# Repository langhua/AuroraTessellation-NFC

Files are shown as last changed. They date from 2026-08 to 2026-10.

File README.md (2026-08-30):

# AuroraTessellation-NFC
Aurora Tessellation NFC（NFC极光镶嵌）：一款桌面级NFC磁场可视化工具。灵感来自极光——太阳风在地球磁场中留下的光痕；用64个线圈组成的“磁像素”阵列，将13.56 MHz的近场磁场分布实时呈现为极光热力图。

## 项目状态

当前从 4×4、16 通道子板开始验证，使用 ESP32-S3 和 4×4 WS2812B 显示模块。第一阶段采用“全波整流 + TS3A44159 差分背景采样”方案，实施顺序和验收标准见 [4×4 子板验证文档](docs/phase-1-4x4-validation.md)。

## 产品形态（最终目标）

桌面级 NFC 磁场可视化模块——“磁像素”阵列，把 13.56 MHz 近场磁场分布实时呈现为极光热力图。

- **阵列规模**：8×8 = **64 个 PCB 铜箔线圈**（磁像素），每个线圈 1:1 对应 **64 颗 WS2812B（5050 封装）LED**，1 采样通道 ↔ 1 LED
- **线圈**：φ19 mm、6 匝、0.2 mm 线宽、20 mm 中心间距 → 阵列覆盖约 **160×160 mm**（4×4 版为 16 线圈、80×80 mm）
- **采集**：每通道全波整流 + 差分背景采样（2×BAT54S + 10 kΩ/100 nF RC）→ TS3A44159 → CD74HC4067 → ESP32-S3 ADC1
- **控制**：ESP32-S3 控制板（WROOM-1 + USB Type-C + CH340 + 3.3 V LDO + EN/BOOT，待建）
- **结构**：**4 块 4×4 传感子板**（每块 16 线圈）拼到 **64 通道母板**，配 8×8 WS2812B 显示
- **尺寸预估（8×8）**：
  - 传感面：**160 × 160 mm**（单板）；或 **4 块 80 × 80 mm** 4×4 子板拼 **64 通道母板**（含连接器 + 控制区约 180~200 × 180~200 mm）。计算：8 线圈 × 20 mm 中心间距 → 首尾 140 mm + φ19 + 板边 0.5×2 = 160 mm。
  - 显示面（8×8 显示布局三方案，2026-08-30 定）：
    - **方案 A · 叠层 1:1（磁像素）**：20 mm 间距定制 LED 板（160×160 mm）叠在线圈板背面，每颗 LED 对准一个线圈 → 热力图与磁场位置 1:1。留作后续优化。
    - **方案 B · LED 嵌线圈孔径**：LED 装在线圈中心孔（φ8）背面往上打光，视觉“镶嵌”感最强；LED 金属可能轻微失谐，需实测。进阶方案，定型后再试。
    - **方案 C · 独立显示板（当前采用）**：现成 7.5 mm 间距 WS2812B 模块（4×4≈30×30 mm、8×8≈60×60 mm）做独立热力图，不追求与线圈 1:1 物理对齐（现成模块间距 7.5 mm ≠ 线圈 20 mm）。
  - 整机：约 **170 × 170 × 30 mm** 桌面盒（传感层 + 显示层堆叠，中间夹控制板）。

## 开发过程总览（4×4 验证 → 8×8 量产）

先小步验证再放大：单通道 → 4 通道 → 4×4 子板 → 完整模块 → 8×8。

```mermaid
flowchart TD
    M0["M0 器件·拓扑（已完成）<br/>单通道原理图 / 元件库 / 线圈阵列铜层"]
    M1["M1 单通道台架验证（面包板）<br/>独立线圈+整流+示波器：无场/弱场/强场"]
    M2["M2 4通道验证（面包板）<br/>TS3A 差分切换 + MUX 逐通道读"]
    M3["M3 4×4 子板 PCB<br/>16路电路 + 4×4 线圈阵列 → Gerber 打板"]
    M4["M4 完整模块<br/>ESP32 读16路 + 背景相减 + 归一化 → 4×4 WS2812B 热力图"]
    M5["M5 8×8 · 64通道母板<br/>4 块 4×4 子板复制 + 64 通道母板"]
    M0 --> M1 --> M2 --> M3 --> M4 --> M5
```

要点：

- **PCB 线圈不是独立子板**——它是传感子板 PCB 的顶层铜箔走线（`coil_4x4_array`），随子板一起验证。面包板阶段用绕制独立线圈（φ20≈φ19）验证信号链和信号量级。
- 可选降险：先打一张**极小的单线圈测试板**（1 个 φ19 线圈 + 2 焊盘），用示波器/网分确认电感和谐振，再铺满 4×4。
- 单通道子板（`hardware/subboard_4x4/single-channel/`）已按**方案 C** 拆分：**无 MCU**，接口为 **J1（8 个网络标签，标注 ESP32-S3-DevKitC-1 IO1/IO2/3V3/IO4/IO5/IO6/IO7/GND，无排针/焊盘元件，实物连接点 M3 布局阶段再加）**，接独立的 ESP32 控制板；面包板原型用 DevKitC-1 经 J1 引线连接。
- 显示侧已验证：`ws2812b-single-test`、`ws2812b-4x4-test`（16 颗 5050，灯序右下角起、每列从下往上）均已跑通。
- **当前进度：M0 基本完成**，下一步是 M1——按 `single-channel-breadboard-wiring.md` 在面包板搭建，接示波器验证。

### Fritzing 部件进度（fritzing-parts-langhua）

| 部件 | 状态 |
|---|---|
| NFC Coil（20mm 6 匝平面感应线圈） | ✅ 已完成并提交 |
| coil_4x4_array（φ19mm 4×4 阵列铜层） | ✅ 已完成 |
| BAT54S（SOT-23 双肖特基二极管） | ✅ 已完成并提交 |
| TS3A44159（TSSOP-16 差分开关） | ✅ 已完成并提交（`TS3A44159PWR.fzpz`，引脚 13~16 已按 SCDS225 核对） |
| CD74HC4067（24 脚 MUX） | ✅ 已完成并提交（`CD74HC4067.fzpz`，四视图 icon/schematic/breadboard/PCB 按 datasheet 绘制） |

## 文档

- [4×4 子板验证文档](docs/phase-1-4x4-validation.md)
- [Fritzing 自定义部件开发指南](../fritzing-parts-langhua/docs/part-dev-guide.md)（位于 fritzing-parts-langhua 部件库，做 BAT54S、TS3A44159 等部件前必读）

## 重要设计说明

本项目输出的是 13.56 MHz NFC 近场磁场的相对分布，不等同于经过校准的 A/m 绝对场强测量仪。打板前必须确认整流拓扑：BAT54S 是双二极管器件，不能直接视为完整四二极管全波整流桥。

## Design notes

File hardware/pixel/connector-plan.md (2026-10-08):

# 像素板接插件方案：3P 三线总线（交叉 / 防呆 / 半双工）

> 状态（2026-09-25）用户已定：① 连接器 = **`SH-1.0-3P-V`（1.0 mm 间距、宽 5.0 mm —— 取最小尺寸）** ✓；② 数据 = **半双工** ✓。
> 本文定针序、口位、交叉与防呆的做法、丝印与电气注意；`pixel.fzz` 按此连线。

SH-1.0-3P-V 的 icon

*已定座子：`SH-1.0-3P-V`（立贴，库里已有 ✓，宽 5.0 mm ✓）/ 更好手焊的 `MX-1.25-3P-V` 见 §6*

## 0. 先说结论：3P + 半双工 ⇒ 两口**电气等价**，"交叉"问题自然消失

三根针只能给 `5V / GND / DATA`。数据要双向（命令下行 + 读数回传）就只能**半双工**（收发同线、分时）
⇒ 两个口的 DATA **必须接到同一个 MCU 引脚**（若一个口专收、一个口专发，读数就永远回不来 ✗：
链上的线是**单向**的，out 口指向下游，读数没路回家 ✗）。

于是两块板之间就是**一条三线总线**，`IN / OUT` 只剩丝印意义：

- **交叉**：**不需要** ✓ —— 两个口**同型**：口 A 的 `DATA` 进**上游脚**、口 B 的 `DATA` 进**下游脚**，
  固件**自动识别哪边在收** ✓ ⇒ **怎么插都通** ✓（拿哪根线、插哪个口都对 ✓）
  ⚠️ 但**别把两口的第 3 针短接** ✗ —— 短接就成了“全网一根线”的真总线 ✗，不再是接力链 ✗（见本节末 ✓）
- **防呆**：做到最强 ✓✓ —— 两个口**都能当上游或下游用**，**不存在“插到 OUT 上”这种错误** ✓；
  3P 座本身有极性 ✓，插头也插不反 ✓

⚠️ **代价（必须认下来）**：这就是 `README §5.2` 的 **3 线方案**，固件要**寻址/枚举**（文档里标的
“⚠️ 需一次性标定” ✓）；**板上数据仍是两根网** —— `DATA_IN` = `PC1`(pin 8) 收 ✓、
`DATA_OUT` = `PD2`(pin 16) 发 ✓（★ 2026-10-09 按 PCB 布线需要换脚 ✓，原来是 `PA2`/`PD0` ✓），
省掉的只是**板间那根线** ✓（见下）。

> 时序、帧格式、枚举与回读时隙：见 [`bus-protocol.md`](bus-protocol.md) ✓
> **本文只定"接插件与接线"**；协议细节不在本文。

### 为什么板间只用 3 根线，面上却是两根数据网？

**4 线方案是这样的**：每块板有两个数据脚（`PA2` 收 + `PC1` 发），板间**拉两根数据线**：
```mermaid
flowchart LR
UP1["上游板 · 下行 DATA 驱动"] -->|"线 1（下行）"| DN1["下游板 · 接收"]
DN2["下游板 · 回程 DATA 驱动"] -->|"线 2（回程）"| UP2["上游板 · 接收"]
```

每根线**只走一个方向** ✓，两根各管一向 ⇒ 可以**同时**收发 = 全双工 ✓。

**3P 只有一个数据针** ⇒ 两块板之间**只有一根数据线** ✓ ⇒ 它得**分时**干两件事 = 半双工 ✓。
⚠️ 但"上游口专收、下游口专发"那种接法是**死路** ✗ —— 一根线只能由**一端**驱动：

```mermaid
flowchart LR
  UP3["上游板 · 下游口针3 = DATA（上游驱动）"] -->|"只有这一根线"| DN3["下游板 · 上游口针3 = DATA（下游只能听）"]
```

下游板要回话就得驱动**自己下游口**那根线 ✗（那是通往再下一级的 ✗）⇒ **读数回不了家** ✗✗。

所以回读不能靠“换一根线”，只能**顺着原路接力回去**：轮到谁时谁把**自己下游侧拉低** ✓，
上游节点见到低电平**立刻在它上游侧也拉低** ✓ ⇒ 一个低脉冲**逐级接力**传到主控 ✓
（这是唯一一处超出 WS2812 的地方 —— WS2812 本身**没有回读** ✗，可我们必须把场强收回来 ✓；
详见 [`bus-protocol.md`](bus-protocol.md) §4.4 ✓）。

⇒ 省掉的是**板间那根线**（回程那根 ✗），**不是板上的脚** ✗ ——
板上始终是 **2 个数据脚 / 2 根网**：`DATA_IN` = `PC1`(pin 8) 收 ✓、`DATA_OUT` = `PD2`(pin 16) 发 ✓
（★ 2026-10-09 换脚 ✓，原 `PA2`/`PD0` ✓；见 [`README.md`](README.md) §五十四 ✓）；
**不许把两口的第 3 针短接** ✗ —— 短接就把接力链变成“全网一根线”的真总线 ✗，回读时隙会互相打架 ✗，
也失去“与 WS2812 完全一致”的简单性 ✓。

> 类比：4 线方案是**电话**（两根线、双方同时说 ✓）；3 线方案是**接力传话**（一根线、
> 每块“听了再生、再往前传” ✓，想往回说话就一拍一拍往上传 ✓）。

### 4 线方案 与 3 线方案 对比

| | **4 线方案** | **3 线方案**（3P 座）|
|---|---|---|
| 板间线 | `5V` `GND` `DATA↓` `DATA↑` | `5V` `GND` **`DATA`（半双工）** |
| 数据线数 | **2 根**（每方向一根 ✓） | **1 根**（两端轮流用 ✓） |
| MCU 数据脚 | **2 个**（收 + 发各 1 ✓，与现在的 QFN20 也兼容 ✓） | **1 个**（收发切换 ✓，另 1 个空出备用） |
| 同时收发 | 可以 ✓（全双工） | 不行 ✗（要排队，像对讲机 ✓） |
| 读数回传 | 有独立回程线 ✓ 固件简单 | 靠同一根线分时 ✓ 要协议（寻址/时隙）✗ 复杂 |

## 1. 针序（两个口完全一样）

| 针 | 信号 | 说明 |
|---|---|---|
| 1 | `5V` | 穿链；多块同时点亮时按 §5.2 的电流预算核 |
| 2 | **`GND`（居中）** | 万一插错，先撞 GND，而**不是**把 5V 灌进数据脚 ✓ |
| 3 | `DATA` | **接力链**（同 WS2812）：一个口进、另一个口出；每口串 100 Ω到 MCU（§5） |

## 2. 接线（5V/GND 两口并接；`DATA` 一口进、一口出 ✓）

```mermaid
flowchart LR
  PUP["上一块<br/>下游口"] -- "3 线" --> UI["本板 上游口 3P<br/>1=5V 2=GND 3=DATA"]
  subgraph PIX["1 块像素板"]
    UI -- "DATA（进）" --> A["U1 · 上游脚（收）"]
    A -->|"固件转发"| B["U1 · 下游脚（发）"]
    B -- "DATA（出）" --> UO["本板 下游口 3P<br/>1=5V 2=GND 3=DATA"]
    PW["5V / GND：两口同名针并接（直流并联）"]
    UI --- PW
    PW --- UO
  end
  UO -- "3 线" --> PDN["下一块<br/>上游口"]
```

- `5V` / `GND`：两口同名针**直接短接**（1-1、2-2）⇒ 电源是直流并联 ✓
- `DATA`：**一口进、一口出、不并接** ✗ —— 它是**接力链**（同 WS2812 ✓）
  ⇒ 3 针里进 MCU 的是 **2 根数据线**（**上游脚 + 下游脚**）✓，不是 1 根 ✗
- 两个口**同型、不分上下游** ✓（固件自动识别哪边在收 ⇒ 插哪个口都能用 ✓）；
  丝印 `IN / OUT` 只表拼接方向 ✓

## 3. 布局与丝印

- 两个口放板的**两条对边**、**开口朝外** ✓；丝印 `IN ▼` / `OUT ▲`（**只表拼接方向**：
  两个口本身同型、电气上互挨也行 ✓ —— 写它是为了让现场拼接/调试时一眼看出链路走向 ✓）
- 口旁丝印 = `5V` `GND` `DATA` + **1 脚标记**（照嘉立创习惯，**不画 1 脚圆点** ✓）
- `5V` / `GND` 用**短而宽**的铜；★ 宽度（2026-10-08 定 ✓）：**8 mil（0.203 mm）** ✓
  —— 前提是**每 4 块一个注入点** ✓（一段 0.248 A ⇒ 载流 0.75 A ✓、段压降 0.9% ✓，实测见
  [`README.md`](README.md) §5 ✓）；✗ 别在"整条 64 块一串"的前提下标这个宽度 ✗（那样要 24 mil ✓ 才够压降 ✓）
- 尺寸：`SH-1.0-3P-V` 座宽 **5.0 mm** ✓（原来担心的 8.65 mm 已换掉 ✓）⇒ 20/22 mm 板边放**两个口 + φ19 线圈**宽裕得多 ✓（见 §6）

## 4. 接力链要点（固件侧）

- 空闲（无帧）时，每个节点的**数据脚都高阻** ✓，线靠上拉保持高电平 ✓；
  一块开始发 = 给下游“喂”电平 ✓（“不能同时驱动”的铁律见 [`bus-protocol.md`](bus-protocol.md) §5 ✓）
- 命令**下行**：主控发 → 每块“取走自己那 3 B、把剩下的原样转发”（同 WS2812 ✓）
- 回读：帧里带**时隙号**，轮到谁时谁把自己的**下游侧拉低** ✓；上游节点见到低电平就
  **逐级接力**把它传回去 ✓（见 [`bus-protocol.md`](bus-protocol.md) §4.4 ✓）
- 上电**枚举**：主控发 `N=0` ⇒ 第一块认领 `index 0` **并把 `N+1` 转给下游** ✓
  （地址存 Flash ✓；3 线方案的已知代价 ✓）

## 5. 电气注意

- `5V/GND` 是**穿链累积**的 ✗ ⇒ ★★ 阵列接法（2026-10-08 定 ✓）：**每 4 块板从电源总线
  单独引一路 `5V/GND`** ✓ ⇒ 板上任何一段铜只承担 **4 块**的电流 ✓。一段 4 块 × 62 mA
  （1010 全白最坏 60 mA ＋ 2 mA）＝ **0.248 A** ✓ ⇒ 走线 **8 mil** ✓（载流 0.75 A ✓）、
  段压降实测 **2.7%** ✓（5V ＋ GND 两程 ✓，`v69` 几何 ✓）、注入针 **0.25 A** ✓
  （`SH-1.0-3P-V` 额定 1 A/触点 ✓ ⇒ 针不是瓶颈 ✓）。
  ★ 一段**最多 16 块** ✗（60 mA/颗时针就到 1 A 了 ✓）；64 块 ⇒ **16 路注入** ✓，
  整机全白电流 **≈4.0 A @5 V** ✓（电源与线径按这个核 ✓）。
  ★ 工具：`pcb_current.py <板.fzz> --nets=pixel_nets.py` ✓（规格就写在
  [`pixel_nets.py`](pixel_nets.py) 的 `POWER_SPEC` 里 ✓，改分段只改那一行 ✓）。
- `DATA`：串 **100 Ω**（限流/阻尼 ✓）+ **上拉 4.7~10 kΩ**（空闲时把线拉高 ✓；接力/回读时靠它恢复高电平 ✓）+ ESD ✓
- 每个口的 `5V` 串 **0.5 A 保险丝 / PPTC**（错插、短路保护 ✓；一段 0.25 A ⇒ 0.5 A 这颗选得正好 ✓）
- 两口的 `5V`/`GND` 在板上**直流并接** ⇒ 一块板坏掉不会断开整条链的**电源** ✓（短路情形见上一条 ✗）
  ⚠️ 但 `DATA` **不是**全网并接 ✗ —— 它是接力链 ⇒ **坏一块、下游全灭** ✗（见 [`bus-protocol.md`](bus-protocol.md) §2 ✓）

## 6. 已定与待定

### ✅ 已定（2026-09-25 用户拍）

- **连接器**：`SH-1.0-3P-V`（**立贴** ✓ —— 理由：插拔方便 ✓ + 占地最小 ✓）
- **板尺寸**：先做 **25 × 25 mm** ✓
- **MCU**：**`CH32V003F4U6`（QFN20，3 × 3 mm，20 脚 + EPAD）** ✓
  （2026-09-25 演进：`J4M6` 是 **SOP8** ✗ 更正 → 试过 QFN12 `D4U6` ✗（无 SPI）→ 用户定 **回 QFN20** ✓
   —— 只有 20 脚才引得出 `PC5/PC6/PC7`（SCK/MOSI/MISO）✓，于是 **SPI ✓ 与 OPA ✓ 一起回来** ✓）
  `CH32V002F4U6`（12-bit ADC、无 OPA）与它**同封装 drop-in** ⇒ 实测后再定、板子不用改 ✓

**MCU 定案带出的四件事**

1. ✅ **`README §4.2 / §4.3` 引脚表已按 QFN20 重做** ✓（20 脚 + EPAD；18 个 GPIO 里只用了 4 个：
   PA1 = 线圈 ADC / PA2 = 链 DATA / **PC6（`SPI_MOSI`）= LED** / PD1 = SWIO ✓）
2. ⚠️ **EPAD 要独立成网** ✓（库规则：裸露焊盘叫 `EPAD` / `EP`，**不进 `<buses>` 的 GND 总线** ✗
   —— 它要布线时**特意接到 GND**，自动合并会让人以为已经接好了 ✓）
   ⚠️ **但库内 `CH32V003F4U6.fzp` 现在把 EPAD 命名为 `VSS` 且放进了 `<bus id="VSS">`** ✗
   （与 `CH32V002D4U6` 用的 `EPAD` 不一致；`fzp_check.py` 第 ⑥ 条只查名字含 `EPAD/EP` 的 ⇒ **漏检** ✗）
   ⇒ 要不要一并改成 `EPAD` + 移出总线，**等你点头我再动库** ✓
3. ⚠️ **工艺**：QFN20 是**底面焊盘** ⇒ 批量用**钢网 + 回流**；**手焊/返修：风枪 + 焊锡膏即可 ✓**
   （用户实测过 QFN，没有传说中那么难 ✓ —— 2026-09-25 更正了我先前“不能手焊”的说法 ✗）
4. ⚠️ **`pixel.fzz` 已作废** ✗ —— 用户 2026-09-25：「现在的 fzz 文件都已经没有参考意义了」
   （LED 改 1010 / MCU 改 QFN20 / 插件改 MX-3P / 总线改三线半双工）⇒ **不修旧图**，等方案定稿重建 ✓

- ✅ **QFN20 的封装尺寸 + 20 脚定义已核实** ✓（datasheet §4 封装表：3.0 × 3.0 mm / 0.4 mm；
  §2.2 表 2-1：pin 0 = VSS/EPAD ✓、`PC5/PC6/PC7` = SCK/MOSI/MISO ✓）
  ⇒ 已写进 `README §4.2 / §4.3` ✓（旧 QFN12 的“要我去量就说”作废 ✓）

### ✅ 已定：连接器取最小的（2026-09-25）

用户原话：「有意换成 SH-1.0 的，想把最小尺寸的做出来看看」✓

- **`SH-1.0-3P-V`**（宽 **5.0 mm** ✓，1.0 mm 间距）—— **已定 ✓**
- 代价（认下来 ✓）：1.0 mm 间距**较难手焊 / 压线** ✗（MX-1.25 的 1.25 mm 好焊一些 ✓）
- 好处：板边能更窄 ⇒ 将来往 **20 / 22 mm 间距**收的时候有余量 ✓
- 备选保留：`MX-1.25-3P-V`（宽 8.65 mm，好手焊 ✓）

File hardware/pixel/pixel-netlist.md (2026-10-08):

# 像素板原理图网表（1 个像素）

> 原理图**只画一个像素**；4×4 = 16 块就是同一张图复制 16 份。
> 按项目约定：**现在画原理图，PCB 等 coupon 实测定间距后再做**；不画面包板视图。
> 草图路径：`hardware/pixel/pixel.fzz`（Fritzing 新建 → 保存到此路径）。
>
> ⚠️ **2026-09-25 状态**：
> - ✅ **本文的 U1 脚号已按 `CH32V003F4U6`（QFN20）全部改好** ✓ —— **照本文接线即可** ✓
>   （脚位依据：[`README.md`](README.md) §4.2/§4.3 ✓；接插件与板间三线见
>   [`connector-plan.md`](connector-plan.md) ✓；协议见 [`bus-protocol.md`](bus-protocol.md) ✓）
> - ✗ **旧的 `pixel.fzz` 已作废**（那是 SOP8 + 2020 + 4 线时代的图 ⇒ **不用去改它** ✓），
>   照本文**新建**一张 sketch 就好 ✓。

## 1. 元件（7 个器件 + 2 个电容 + 3 个网络标签）

| 位号 | 元件 | 库内名字 | 备注 |
|---|---|---|---|
| L1 | NFC 线圈 φ19 / 6 匝 | `NFC_Coil_20mm_6T_0p2_1` | MINE；连接器 `inner` / `outer` |
| D1 | `BAS70BRW`（4 × 70 V 肖特基，两对串联）| `BAS70BRW_SOT363_1` | MINE ✓；一颗 = **整个全波桥** ✓（连接器 `A1`/`AC1`/`C1` + `A2`/`AC2`/`C2`）|
| R1 | 10 kΩ | `R0603` | core |
| C1 | 100 nF | 0603 电容 | core；RC 对地 |
| C2 | 100 nF | 0603 电容 | core；U1 去耦 |
| U1 | `CH32V003F4U6`（或 `CH32V002F4U6`） | 本库已有 ✓ | QFN20，20 脚 + EPAD；SPI ✓ + OPA ✓ |
| LED1 | WS2812B 1010 | `WS2812B_1010_1` | MINE；`DIN` / `DOUT` / 电源脚（以库内实际名称为准） |
| — | Net Label ×4 | core `Net Label` | `5V` / `GND` / `DATA_IN` / `DATA_OUT` |

## 2. 网表（照这个连线）

| # | 起点 | 终点 | 说明 |
|---|---|---|---|
| 1 | `L1.inner` | `D1.AC1` | 线圈一端 → 桥 **AC1**（pin 6）|
| 2 | `L1.outer` | `D1.AC2` | 线圈另一端 → 桥 **AC2**（pin 3）|
| 3 | `D1.A1` | `GND` | 桥负 **A1**（pin 1）|
| 4 | `D1.A2` | `GND` | 桥负 **A2**（pin 2）|
| 5 | `D1.C1` | `R1.1` | 桥正 `BR+`：**C1**（pin 5）|
| 6 | `D1.C2` | `R1.1` | 桥正 `BR+`：**C2**（pin 4）|
| 7 | `R1.2` | `C1.1` | RC 节点 |
| 8 | `R1.2` | `U1.pin20`（**PD6**）| RC 节点 → ADC（**同一节点、两段线** ✓）★ 2026-10-09 换脚 ✓（原 `PA1` ✓，PCB 布线需要 ✓）⇒ 代价：**内置 OPA 的输入 `OPN0` 用不上了** ✗（要用 OPA 就得搬回 `PA1` ✓）|
| 9 | `C1.2` | `GND` | |
| 10 | `U1.pin4` | `GND` | **VSS**（pin 4）|
| 11 | `U1.pin6` | `5V` | **VDD**（pin 6）|
| 12 | `C2.1` | `5V` | 去耦 |
| 13 | `C2.2` | `GND` | 去耦 |
| 14 | `U1.pin8`（**PC1**）| `DATA_IN` | 链**上游脚**（收本板上游口的 `DATA` ✓）★ 2026-10-09 换脚 ✓（原 `PA2` ✓）|
| 15 | `U1.pin16`（**PD2**）| `DATA_OUT` | 链**下游脚**（再生转发给下游口 ✓）★ 2026-10-09 换脚 ✓（原 `PD0` ✓）|
| 15b | — | — | ⚠️ 两根数据网**不许短接** ✗（短接 = 真总线，接力链/回读时隙会打架 ✗）|
| 16 | `U1.pin13`（**PC6 / `SPI_MOSI`**）| `LED1.DIN` | 自驱本板 1010 ✓（固件走 SPI + DMA ✓）|
| 17 | `LED1.VDD` | `5V` | |
| 18 | `LED1.VSS` | `GND` | |
| 19 | `U1.pin0`（**EPAD**）| `GND` | ⚠️ **独立成网** —— 布线时**特意**接到 GND ✓（别指望自动合并 ✗）|

**不接**：`LED1.DOUT`（LED 不在硬件链上，链在 MCU 之间 ✓）；`U1.pin15`（**PD1 = SWIO**）留个测试点、平时悬空 ✓；其余 **13 个备用脚**（`PD7` / `PA1` / `PA2` / `PD0` / `PC0` / `PC2`–`PC5` / `PC7` / `PD3`–`PD5` ✓ —— 2026-10-09 换脚后 `PA1`/`PA2`/`PD0` 也空出来了 ✓）也留测试点或悬空 ✓。

## 3. U1 引脚分配（`CH32V003F4U6`，QFN20，20 脚 + EPAD）

| 脚 | 名称 | 这里接 |
|---|---|---|
| **0** | **EPAD**（内部 = VSS）| `GND` ⚠️ **独立网，特意布线** ✓ |
| 1 | PD7 | 备用（也是 `NRST`）|
| 2 | PA1（ADC_IN1 / OPA `OPN0`）| **空出** ✓（原线圈输入 —— ★ 想用内置 OPA 就得搬回来 ✓）|
| 3 | PA2（ADC_IN0）| **空出** ✓（原 `DATA_IN` ✓）|
| 4 | VSS | `GND` ✓ |
| 5 | PD0 | **空出** ✓（原 `DATA_OUT` ✓）|
| 6 | VDD | `5V` ✓ |
| 7 | PC0 | 备用 |
| **8** | **PC1** | `DATA_IN`（链上游，**收**）✓ ★ 2026-10-09 换脚 ✓（原 `PA2` ✓；它也是 `SPI_NSS` ✓，不冲突 ✓）|
| 9 | PC2 | 备用 |
| 10 | PC3 | 备用 |
| 11 | PC4（ADC_IN2）| 备用（第 2 路 ADC ✓）|
| 12 | PC5 | 备用（`SPI_SCK`，本设计不引出 ✓）|
| **13** | **PC6**（`SPI_MOSI`）| `LED1.DIN` ✓（★ 2026-10-09 用户决定**保住 SPI+DMA** ⇒ 这一脚**不能挪** ✓，见 README §5.2 ✓）|
| 14 | PC7 | 备用（`SPI_MISO`）|
| **15** | **PD1** | SWIO 烧录（留测试点，平时悬空 ✓）|
| **16** | **PD2**（ADC_IN3）| `DATA_OUT`（链下游，**发** —— 再生转发给下一块 ✓）★ 2026-10-09 换脚 ✓（原 `PD0` ✓）|
| 17 | PD3（ADC_IN4）| 备用 |
| 18 | PD4（ADC_IN7 / OPA `OPO`）| 备用（要放大时用 ✓）|
| 19 | PD5（ADC_IN5）| 备用 |
| **20** | **PD6**（ADC_IN6）| 线圈包络 → **ADC** ✓ ★ 2026-10-09 换脚 ✓（原 `PA1` ✓）|

`CH32V002F4U6`（12-bit ADC、无 OPA）与它**同封装同脚位**，可直接换上 ✓。

## 4. 画图步骤（Fritzing GUI）

1. 新建 sketch（**旧 `pixel.fzz` 已作废、不要改它** ✓）→ 保存为 `hardware/pixel/pixel.fzz`；
2. 切到**原理图**视图，从 MINE / core 拖入 §1 的元件（MINE 搜型号：`CH32V003F4U6` ✓、`WS2812B_1010_1` ✓、`SH-1.0-3P-V` ✓…）；
3. 排布（左 → 右）：`L1 → D1 / D2 → R1 / C1 → U1 → LED1`；`5V / GND / DATA_IN / DATA_OUT` 四个网络标签放在 U1 两侧；
4. 按 §2 连线（Fritzing 会自动吸附到引脚端点）；
5. 保存后把 fzz 给我 —— 我读里面的 `wire` 元素**逐条核对网表**（和核对 single-channel 一样的方式）。
6. 作图规则（网格/位号/命名/字体）**沿用库仓**：`fritzing-parts-langhua/docs/schem-drawing-rules.md` ✓；
   画完可先自核一遍：`py -3.13 <库仓>\tools\sch_style_check.py hardware\pixel\pixel.fzz`
   （网格只作参考 ✓；**位号重复 / 名字只差大小写**会报 FAIL ✓）。

## 5. 暂不做

- **PCB 布局**：等 coupon 实测（20 / 22 mm 间距、孔内元件衰减）出来再做（见 [`README.md`](README.md) §6 与 [`coupon-layout.md`](coupon-layout.md)）；
- **面包板视图**：项目约定不画。

## 6. 备注

- **`BAS70BRW` 一颗就是整个全波桥** ✓（内部已是两对串联）：`AC1`(pin6) / `AC2`(pin3) = 线圈两端，
  `C1`(pin5) + `C2`(pin4) = `BR+`，`A1`(pin1) + `A2`(pin2) = `GND` ✓ —— **不要再外接二极管** ✗；
- 整流输出 `BR+` 要 < VDD（场强过大时加钳位，见 README §3 的"过压钳位（可选）"）；
- 固件里 LED 时序用 **SPI + DMA** 产生 ✓（QFN20 有 SPI ✓，走 `SPI_MOSI` = **pin 13**；见 README §5.2）；
- **EPAD（pin 0）单独一根线到 GND** ✓（库规则：它**不在任何总线里**，别指望自动连上 ✗）；
- 接插件针序 **`5V` / `GND`（居中）/ `DATA`**，两口**同型、都能当上游或下游用** ✓（固件自动识别哪边在收 ✓）；
  但板上 `DATA_IN` / `DATA_OUT` 是**两根网**（`PA2` / `PD0`）、**不许短接** ✗ —— 详见 [`connector-plan.md`](connector-plan.md) ✓。

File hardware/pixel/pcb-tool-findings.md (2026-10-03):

# 布线工具：实测查出的真 bug 与 Fritzing 事实

> 立此存照（2026-10-03 ✓，全部**实测** ✓，每条附**复现命令** ✓）。
> 缘起：用户从 `pixel-pcb-v51_byHand.fzz` 开始"重新排布元件和布线" ✓。
> 结论一句话：**这轮挖出的三处硬伤都在我们自己的工具里** ✗，**不是**用户的画法 ✗。
> 文件名里的 `<...>` 与命令都可在 `hardware/pixel/` 下原样跑（诊断脚本在 `_work/`，**不入库** ✓）。

---

## BUG-1 ✗✗ `model["net_pads"]` 从未写回 ⇒ "同网豁免"形同虚设 ⇒ 报"起点格空"

**症状**：`BR+` / `DATA_IN` / `DATA_OUT` / `LED_DIN` 四张网永远布不通，原因写的是
`不可达/可达=False 起点格空`。

**根因（实测）**
- `pcb_route.obstacles()` 的注释写着：「布某张网时，把 `tag == 本网` 的障碍**减掉**」✓，
  它读的是 **`model["net_pads"]`** ✓；
- 而 `pcb_route.resolve_nets()` **只返回结果、不写回 `model`** ✗
  ⇒ 那张表**长期为空** ✗ ⇒ **每只焊盘都算不出网名** ✗
  ⇒ 邻居焊盘的盘框**永不被豁免** ✗ ⇒ 0.4 mm 脚距的 `U1`(QFN20) / `D3`(SOT363) 上，
  **起步格被隔壁盘框盖住** ✗。

**证据**（`_work/probe_start.py` ✓）
```
修改前： U1.connector2  中心 (46.08, 16.97) mm ⇒ 判到的网 = None  ✗
修改后： U1.connector2  中心 (46.08, 16.97) mm ⇒ 判到的网 = DATA_IN ✓
         U1.connector20（EPAD）⇒ 判到的网 = GND ✓（原来是 None ✗）
```
- 注意：**诊断脚本与生产脚本必须同参数** ✓ —— 本文件 BUG-3 后的"教训"一节有血例 ✗。

**修法**：调用方把返回表写回 —— `hardware/pixel/gen_routes.py` 一行 ✓：
```python
net_pads, unresolved = RT.resolve_nets(model, data.NETS)
model["net_pads"] = net_pads          # ★ 让 obstacles() 的同网豁免真正生效
```

**复现**
```
py -3.13 _work\probe_start.py _work\v56_place.fzz pixel_nets.py DATA_IN LED_DIN
```

**遗留**：修好后这四张网**仍未布通** ✗（起终点都干净 ⇒ 堵点在**路中间** ✓）。
`gen_routes` 的失败文案"起点格空"**会误导** ✗（真正被挡的可能是终点或中段），
下一步应给 `pcb_route` 加诊断：**分段失败时打印"起点泛洪到的格数 / 目标是哪个格 / 是否可达"**。

---

## BUG-2 ✗✗ 走线可以是**贝塞尔曲线**，我们只读了两个端点、按直线算 ✗

**Fritzing 的文件写法**（实测 `Wire90013354` ✓）
```xml
<geometry z="6.50017" x="187.799" y="81.5189" x1="0" y1="0" x2="7.123" y2="-17.751" wireFlags="4"/>
<wireExtras mils="24" color="#f28a00" opacity="1" banded="0">
    <bezier><cp0 x="0" y="0"/><cp1 x="7.92489" y="-7.57775"/></bezier>
</wireExtras>
```
**源码口径**（`F:\build-fritzing\fritzing-app\src\utils\bezier.h` ✓）
`Bezier(QPointF endpoint0, QPointF endpoint1, QPointF cp0, QPointF cp1)`
⇒ **三次贝塞尔 = 两个端点 ＋ 两个控制点**；端点**就是** `<geometry>` 那条线，
`cp0/cp1` 与 `x1..y2` **同一局部坐标系**（实测 `cp0=(0,0)` 正好 = 弦的起点 ✓）。
另有 2 个 `<geometry x="0" y="0"/>` 是"该实例不在那两个视图"的**占位** ⇒ 必须跳过 ✗。

**后果**（本板 25 根 PCB 走线里 **17 根是曲线** ✗）
- 线间距 ✗：`Wire90013354`(5V) ↔ `Wire90013339`(GND) —— 按弦算 **0.0733 mm** ✗，
  按曲线采样算 **0.7653 mm** ✓（差 0.69 mm ✗，结论从"疑似短路"翻成"比 0.127 mm 最小间距宽 6 倍" ✓）；
- 交叉判定 ✗、保线**障碍框** ✗（只框两端 ⇒ 弯的中段没人管 ✗）、渲染 ✗。

**修法**：`fritzing-parts-langhua/tools/pcb_wire.py`
- `parse_trace()` 补读 `<bezier>` ✓；新增 `curve_pts(geo, bezier, n)` 采样 ✓（**全仓唯一读法** ✓）；
- 消费方：`fz_keep_set.py` 存折线 ✓ ⇒ `gen_routes --keep` 逐段生成障碍框 ✓。

**复现**
```
py -3.13 _work\curve_check.py pixel-pcb-v51_byHand.fzz Wire90013354 Wire90013339
```

---

## BUG-3 ✗ `write_back` 的块扫描靠"同缩进配对" ⇒ 会**少一个实例**

**症状**：`gen_pcb.py` 写回后，实例数 **113 → 112** ✗（块边界被切错，上锁件也会莫名多/少几字节 ✗）。

**根因**：旧正则 `^([ \t]*)<instance\b.*?\n\1</instance>` 依赖**闭合标签与开标签同缩进** ✗；
Fritzing 的缩进并不总是这样 ✓ ⇒ 错位 ✗。

**修法**（`hardware/pixel/gen_pcb.py`）：按 `<title>` 定位 ⇒ `rfind("<instance")` / `find("</instance>")` ✓
（与 `fz_strip_pcb.blocks_of` **同一口径** ✓）。

**复现**
```
py -3.13 _work\block_diff.py _work\v51_clean.fzz _work\v51_lockplace.fzz --locked-only
```

---

## 三条**流程**教训（比 bug 本身更值钱）

1. **诊断脚本必须与生产脚本同参数** ✗ —— 本次探针忘了设 `RT.TRACE_MM`（生产 = 8 mil），
   用了模块默认 24 mil ⇒ 障碍加肥 0.6096/2+0.15 = **0.4548 mm** ✗ ⇒ 造出**假的**
   "EPAD 盖住 LED2.connector2" ✗。**同一类坑本次犯了三次** ✓。
2. **判据必须同源** ✓ —— "两根线相距 0.073 mm""两根线交叉""导出图把线截短" 全是自造判据的产物 ✗；
   换成"读 `<bezier>` + 采样"后就一致了 ✓。
3. **对不上时先怀疑自己** ✓ —— 用户三次指出"你的解析与 Fritzing 不一致"（曲线 ✓、
   多层几何 ✓、颜色写错 ✓），每次都是我对 ✗。

---

## 附：可直接引用的 Fritzing 事实（都有出处 ✓）

| 事实 | 出处 / 复核方式 |
|---|---|
| **锁** = 移动锁，写 `<pcbView locked="true">` | `itembase.cpp:294` 写 / `sketchwidget.cpp:281,318` 读设 / `:1076,:2442,:7162` 拦移动 / `connectoritem.cpp:2508` / `resizableboard.cpp:1228` |
| 一个实例**每个视图只有一个** `<geometry z=…>`（另有 2 个 `x=0,y=0` 占位） | `_work/view_geoms.py <fzz> Wire90013354` |
| 端点 = `loc+(x1,y1)` / `loc+(x2,y2)` | `viewgeometry.cpp` 的 `ViewGeometry(QDomElement&)` |
| PCB 走线/过孔 = 带 `<pcbView>` 的 `Wire`/`Via` 实例 | `_work/dump_wires2.py` |
| 用户手画线在导出图里按 **24 mil** 渲染（`.fz` 里可能写 22.2222 mil） | 导出 SVG 的 `stroke-width="1.728"`（1 pt = 0.35278 mm） |
| 导出 SVG：1 单位 = 1 pt、1 mm = 72/25.4、板原点由板框反推 | `fz_overlay2.py`（已校准到与板组 `translate` 一致 ✓） |

---

## 2026-10-03 续：`--why` 诊断补齐 ⇒ 四张网"堵在哪"有答案了 ✓

### 先修掉一个**让诊断看不见**的崩 ✗

`gen_routes.py` 的「保线」段里有个循环变量叫 **`key`** ✗ —— 它把**模块级函数** `key()`
**遮蔽**掉 ✓ ⇒ 后面写回自检调 `key(...)` 时抛
`TypeError: 'str' object is not callable` ✗ ⇒ **main 崩在半路** ✗
⇒ 打印"为什么布不通"那一段**根本跑不到** ✗。

⇒ 教训：我把"诊断没出现"先归因成"终端输出被截断" ✗ —— **错的** ✓；
先用 `2>&1 | Out-File -Encoding utf8` **落盘**再读 ✓，一眼就看见 traceback ✓
（PowerShell 的 `*>` 默认写 UTF-16 ✗，直接读是乱码 ✗ ⇒ 用 `_work/showlog.py` ✓）。

### 诊断做了什么 ✓

| 改动 | 位置 | 作用 |
|---|---|---|
| `Grid.OWN` + `self.own` | `pcb_route.py` | 记录**每个被挡格子的出处** ✓（默认**关** ✗ ⇒ 不开 `--why` 时速度/结果**一字不变** ✗，已实测 ✓） |
| `obstacles()` 多返回 `labels` | 同上 | 与 `items` **逐条对齐**的出处表 ✓（`盘:U1.connector3` / `件铜:L1` / `安装孔(Ø2.2 mm)` ✓） |
| 各挡块点贴标签 | `_route_once` | `盘:…`、`线:…`、`过孔:…`、`保线:…`、`板边` ✓ |
| `_why_report` / `boundary_report` / `grid_free` | 同上 | ① 起/终点**紧邻一圈**逐格报到谁挡的 ✓；② 可达区**边界**上是谁（按格数排序 ✓）；③ 全板可走格数（判"可达 N 格"是大是小 ✓） |
| **判决**（算出来 ✗，不写死 ✗） | 同上 | 起点侧大/终点侧小 ⇒ **终点口袋** ✓；反之 ⇒ **起点扇出口袋** ✓ |
| 只留**胜出那份**的诊断 | `route` / `route_ripup` | 6 种次序各报一遍 = 6 倍噪音 ✗，且**最后那遍未必是胜者** ✗ ⇒ 会把不存在的病报出来 ✗ |

### 结论（`_work/v56_place.fzz` + 用户保线 ✓，最终解 = 连通 5/9）

| 网 | 段 | 起点侧 | 终点侧 | **围住它的是谁** |
|---|---|---|---|---|
| `DATA_IN` | `U1.connector2→J1.connector2` | **39 格** ✗ | 25154 ✓ | `线:GND×18`、`盘:U1.connector3×9`、`盘:U1.connector1×7` |
| `DATA_OUT` | `U1.connector4→J2.connector2` | **44 格** ✗ | 25159 ✓ | `线:GND×19`、`盘:U1.connector3×9`、`过孔:5V×6` |
| `LED_DIN` | `U1.connector12→LED2.connector2` | **33 格** ✗ | **56 格** ✗ | 起点：`盘:U1.connector11/13/20`、`线:COIL_A×7`；终点：`线:GND×22`、`盘:LED2.connector1/3` |
| `BR+` | `D3.connector3→R1.connector0` | 15718 ✓ | **1321 格** ✗ | `线:5V×55`、`线:GND×49`、`过孔:GND×15`、`盘:C1.connector0×13` |

（全板可走 ≈ **25 000～27 400 格** ✓ ⇒ "可达 39 格"就是**0.15%** ✗，一眼看出是口袋 ✓）

### 病根一句话 ✓

**已经布好的 `GND` / `5V` 铜（含用户保线那几条 ✓）＋ QFN 的邻脚**，把要接的脚
**围成小口袋** ✗ —— 正是仓规 §5b ⑩「留路」那条病 ✓（先布的线把后布的路占掉 ✗）。
⇒ 下一步该动的**不是判据/系数** ✗，而是**布的次序与走廊预算** ✓（待与用户对齐 ✓）。

---

## 2026-10-03 续 2：次序真的改了 ⇒ **5/9 → 6/9** ✓，且三张网的"口袋"量出了坐标与尺寸 ✓

### ★ 更正：先说"甲（信号先布）是中性"是**错的** ✗

真因：`gen_routes` 还在传 `first=power` ✗，而排序键 `(0 if in first else 2 if in last …)`
**`first` 先判** ✗ ⇒ `--signals-first` 是个 **no-op** ✗ ⇒ A/B 两边**逐项相同** ✓。
★ **教训（比结论值钱）**：**开关没生效时，A/B 会显示"完全相同"** ✓ ——
那不是"中性" ✗，是"没生效" ✗ ⇒ **必先验证输入真的变了** ✓。
已修：`last` **先判** ✓；新增 `--why` 打印「**次序实排**」✓。

### 实测（`v56_place.fzz` ＋ 用户保线 ✓ ＋ `--pitch=0.50` ✓）

| 组 | 参数 | 连通 | 线长 | 过孔 | 失败的网 |
|---|---|---|---|---|---|
| A | — | 5/9 | 104.1 mm | 8 | `BR+`・`DATA_IN`・`DATA_OUT`・`LED_DIN` |
| D1 | `--last=5V` | 5/9 | — | — | 与 A 同（**`5V` 排不排无所谓** ✓）|
| D2 | `--last=GND` | **6/9** ✓ | 130.7 mm | 9 | `DATA_IN`・`GND`(5 段)・`RC`(2 段) |
| **H1** | `--last=GND --first=5V,RC` | **6/9** ✓ | **92.8 mm** ✓ | **7** ✓ | `BR+`・`DATA_IN`・`GND`(5 段) |

⇒ ① 起作用的是 **`GND` 排最后** ✓；② `RC` 与 `BR+` **此消彼长** ✗（H1 通了 `RC` 掉了 `BR+` ✓）；
③ **`DATA_IN` 提前没用** ✓（H1 ≡ H2 逐项相同 ✓）—— 见下：它的墙**不是线** ✗。

### 三张网的"口袋"：坐标 + 尺寸（这是本轮最有用的一张表 ✓）

| 网 | 起点可达 | 口袋范围（mm） | 形状 | 围住它的是谁 |
|---|---|---|---|---|
| `DATA_IN` | **39 格** ✗ | x 45.48…46.68（**宽 1.20**）<br>y 16.62…17.37（**高 0.75**） | **细缝** ✗ | **全是"盘的净空"** ✗：`盘:U1.connector3×9`・`盘:U1.connector20(网=GND)×8`・`盘:U1.connector1×7`・`盘:C1.connector1(网=GND)×4` —— **一根线都没有** ✓ |
| `GND` | **51 格** ✗ | x 40.98…41.88（**宽 0.90**）<br>y 17.37…18.42（**高 1.05**） | 小方块 ✗ | `D3` 邻脚 `盘:D3.connector1×7` ＋ **先布的** `线:LED_DIN×11`・`过孔:LED_DIN×7` ✗ |
| `RC` | **784 格** ✗ | x 45.63…53.58（**宽 7.95**）<br>y 12.42…15.72（**高 3.30**） | **一大片被线切断** ✗ | `线:5V×55`・`线:BR+×49`・`过孔:5V×15`・`过孔:BR+×14` ✗ |

★ 三者**尺度差 10 倍** ✓ ⇒ **不是一种病** ✗：
· `DATA_IN`／`GND` = **扇出口被邻脚的净空墙封住** ✗（≈1 mm ✓）⇒ **次序治不了** ✗（已实测 ✓）；
· `RC` = **先布的线把一片区域切断** ✗（8×3.3 mm ✓）⇒ **次序治得了** ✓（H1 已证 ✓）。

### 已排除的杠杆（**用 SHA256 证明三个产物完全相同** ✓，不是"看着一样" ✗）

`--no-mid-keep` ✗（那条"罚走中间"对最终解**从来没起作用** ✓）；
`--last=GND,RC` ✗；`--passes=8` ✗（拆线重布第 1 轮就停 ✓）；
`--first=5V,RC,DATA_IN` ≡ `--first=5V,RC` ✗。

### 摆位审计：**全过** ✓

`audit_placement.py _work\v56_place.fzz` ⇒ 全过 ✓（孔心离边 ✓、Ø4.0 免件 ✓、都在板内 ✓）。
⇒ `U1` 旁边那圈 `C1` 的贴近**不犯规** ✗，是**密度**问题 ✓
⇒ `DATA_IN` 要通，只能**放宽几何** ✗ 或**微挪 `C1`** ✓（`U1`／`C1`／`R1` **未上锁** ⇒ 可动 ✓）。

### ✗ 试了"微挪 `C1`"（用户选的甲 ✓）⇒ **失败，已回退** ✗

| 试法 | 连通 | 线长 | 过孔 | `DATA_IN` 的口袋 |
|---|---|---|---|---|
| 不挪（H1 ✓）| **6/9** ✓ | 92.8 mm | 7 | x 45.481…46.681 ｜ y 16.622…17.372（**39 格** ✓）|
| `C1` 东 **0.3 mm** | 5/9 ✗ | 65.3 mm | 3 | **一模一样** ✗ |
| `C1` 东 **0.8 mm** | **4/9** ✗ | 86.0 mm | 6 | **一模一样** ✗ |
| `C1` 南 **0.8 mm** | **4/9** ✗ | 84.5 mm | 6 | **一模一样** ✗ |

★ **判据（决定性 ✓）**：口袋的 **bbox 与格数一字未变** ✓ ⇒ **`C1` 根本不是那道墙** ✗。
0.3 mm 那次确实把 `C1` **从边界名单里挪走了** ✓ —— 但**口子随即被 `线:RC`×8 ／
`线:DATA_OUT`×6 顶上** ✗✗ ⇒ 那个口袋是个**死胡同** ✓，**口子只有 1～3 格宽** ✗
⇒ **谁从那儿过就把口封死** ✗。

⇒ 结论 ✓：`DATA_IN` 的 39 格是 **`U1` **自身**的几何** ✗（右列相邻脚的净空 ＋ EPAD 净空 ✓）
⇒ **挪邻近件治不了它** ✗；要治只能动 `U1` 自己 ✗、或改**净距/线宽规则** ✗（那是制造口径 ✓，须用户点头 ✓）。
⇒ 三个 `v57_*` 试验件**一概不采用** ✗，基线仍是 `_work/v56_place.fzz` ✓。

---

## 2026-10-03 续 3：放开 `U1/D3/R1/C1/LED2`（用户点名 ✓）⇒ **270° 是最好的板** ✓，但**仍是 6/9** ✗

用户要求这 5 件可移可转 ✓，并要求 **`LED2` 必须在顶层** ✓（生成器本来就只在顶层搜它 ✓
—— `TOP_SIDE = ("L1","LED2")` ✓）。新增三个开关 ✓（都默认空 ⇒ 不传就不变 ✗）：
`--unlock=` ✓、`--unpin-center=` ✓、`--pin-rot=件:角度` ✓。

### ① 放开之后，摆位器自己选的落点**就是原位** ✗

| 件 | 搜出来的落点 | 与 v56 比 |
|---|---|---|
| `U1` | (12.50, 12.50) mm、0° | **原位** ✗（它早就在板心）|
| `C1` | (15.50, 12.50) mm、270° | **原位** ✗ |
| `R1` | (10.25, 10.50) mm、180° | 移了 ＋ 转过 ✗ |
| `LED2` | (12.50, 13.00) mm、**正面** ✓ 90° | 微移 ✓（顶层要求满足 ✓）|
| `D3` | **找不到位置** ✗（与绕组同面且压上 ×6014 ✓、离 `U1` 太近 ×2474 ✓、离 `L1` 太近 ×1116 ✓）⇒ 保持原位 ✓ |

★ 于是 ✓：`DATA_IN` 的口袋 **bbox 与格数一字未变** ✗（仍是 39 格、x 45.481…46.681 ✓）
—— 因为**口径由 `U1` 与 `C1` 定** ✓，而这两件摆位器**本来就想放在原位** ✓
⇒ **那个死胡同是"这套件 ＋ 板心摆位"的固有属性** ✗，**不是摆位没选好** ✓。
★ 附带好消息 ✓：`D3` 没动 ⇒ 用户保线（`BR+`→`D3.3/3.4`、`GND`→`D3.0/D3.1`）**没断** ✓
（按新摆位重算的保线表与旧的**逐项相同** ✓）。

### ② 四个朝向 × 四组次序，全试过（H1 参数 = `--last=GND --first=5V,RC`）

| 摆位 | 连通 | 线长 | 过孔 | 失败的网 |
|---|---|---|---|---|
| `U1` 0° | 6/9 | 95.6 mm | 8 | `DATA_IN`・`GND`・`LED_DIN` |
| `U1` **90°** | **3/9** ✗ | 50.3 mm | 3 | — |
| `U1` 180° | 5/9 ✗ | 71.2 mm | 5 | — |
| **`U1` 270°** ✓ | **6/9** ✓ | **59.2 mm** ✓ | **2** ✓ | `COIL_B`・`DATA_OUT`・`GND` |
| `U1` 270°（不加次序开关）| 5/9 ✗ | 119.8 mm | 8 | — |
| `U1` 270°（`--last=5V,GND --first=RC`）| 6/9 | 59.2 mm | 2 | 同 270° ✓ |

⇒ ★ **结论** ✓：**失败的网换来换去，但始终有 3 张不通** ✗ ⇒ 这是**容量墙** ✓，
不是"某个朝向没试到" ✗；**最好的板** = `U1` **270°** ✓（线长 **−36%** ✓、过孔 **−71%** ✓）。
⇒ 若还要往上走 ✓，只剩**改制造口径** ✗（净距 0.15 → 0.127 mm ＝ 嘉立创下限 ✓）或**手接** ✓。

### ③ 复现命令

```
py -3.13 gen_pcb.py pixel-pcb-v51_byHand.fzz _work\v58_u270.fzz \
    --unlock=U1,D3,R1,C1,LED2 --unpin-center=LED2 --pin-rot=U1:270
py -3.13 fz_keep_set.py _work\v58_u270.fzz _work\keep_u270.py
py -3.13 gen_routes.py _work\v58_u270.fzz _work\u270_routed.fzz \
    --keep=_work\keep_u270.py --pitch=0.50 --last=GND --partial
```

---

## 2026-10-03 续 4：旋转 15°＋上顶面＋盘上打孔 —— 全试过 ⇒ **结构性放不下** ✗

用户继续放开三件事 ✓，全部实测 ✓：

1. **`--rot-step=15`** ✓（旋转步进 ✓）：`U1` 仍是 0° ✗（cost 不懂可布线性 ✓）。
2. **`--top-ok=R1,C1,D3`** ✓（允许上顶面 ✓）：`C1`、`R1` **自己翻到顶面** ✓
   （`C1` copper0→copper1、θ 270→90 ✓ 文件里核过 ✓）；`D3` 仍找不到位置 ✗
   （压绕组 ×12028 ✓、离 `U1` 太近 ×4948 ✓）⇒ 原位 ✓ ⇒ 保线表重算与旧**逐项相同** ✓
   （`C1.connector1` 本就不在他的 GND 链上 ✓ ⇒ 他的铜没断 ✓）。
3. **`--via-at-pad`** ✓（细间距/裸露盘**允许盘上打孔** ✓，默认关 ✓）：**没用** ✗。

★ **决定性诊断** ✓：`U1` 的脚全是 `fine=True` ✓（gap 0.2 mm ✓）⇒ 盘上打孔是放行的 ✓；
但**铜1 打不进去** ✗ —— 线圈 `L1` 在铜1 是 **745 段螺旋** ✓（间距 ~0.6 mm ✓），
Ø0.6 的过孔盘**塞不进 0.6 mm 的缝** ✗，还被 0.55 mm 禁落（`VIA_CLEAR_MM + VIA_SAFE_MM`）封死 ✓。

⇒ **结论（量出来的 ✓，不是感觉 ✗）**：

| 事实 | 数值 |
|---|---|
| 板 | **25 × 25 mm** ✓ |
| 线圈 `L1` | **19 × 20 mm** ✓（占住板心 ✓，NFC 天线必须居中 ✓）|
| 四周剩 | **~3 mm** ✗ |
| `U1`（QFN20） | **4.1 × 4.1 mm** ✗ ⇒ **放不进线圈外** ✗ |
| `U1` 脚距 | **0.4 mm** ✓ ⇒ 侧面扇出被邻脚净空封死 ✗ |
| 盘上打孔 | Ø0.6 过孔 **塞不进 0.6 mm 螺旋缝** ✗ |

⇒ **在「这套件 ＋ 这块 25×25 板」下，`U1` 必须压在线圈正下方** ✗，而它在那里
**既不能横向扇出（0.4 mm 脚距 ✗）、又不能打孔下穿（线圈在上面 ✗）** ✗✗
⇒ **9/9 自动布线在物理上不可达** ✓ —— 不是参数/次序/摆位没调好 ✓。

### 可行的出路（都要用户拍板 ✓）

1. **加大板子** ✓（25 → 30 mm ⇒ `U1` 能挪到线圈旁 ✓）—— 架构改动 ✗；
2. **缩小 / 挪开线圈** ✓（NFC 天线几何 ✓）—— 天线性能会变 ✗；
3. **手接最后 3 根** ✓（`COIL_B`・`DATA_OUT`・`GND` ✓）—— 你在 Fritzing 里自己放那几颗
   过孔/走线（你知道线圈哪儿真能穿 ✗）✓。

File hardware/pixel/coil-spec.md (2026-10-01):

# L1 线圈：规格、可换档位、以及电气代价（2026-10-01 ✓）

> 为什么有这个文档 ✗：布线走到 8/9 卡住时，**所有**"没路"的测量都指向同一件事 ——
> **线圈的铜把板中间占满了** ✓（它在顶层铺 6 圈 ✓，所有走廊都得钻**匝间缝** ✓）。
> 把"参数 ↔ 布线后果 ↔ 电气代价"一次写清 ✓，免得每次从头推 ✓。

## 1. 现在用的规格

**库件**：`fritzing-parts-langhua/svg/NFC-Coil/part.NFC_Coil_20mm_6T_0p2_1.fzp`
**生成器**：`svg/NFC-Coil/gen_coil.py`（4 个常数 + 2 个焊盘半径 ✓，全部参数化 ✓）

| 项 | 值 | 出处 |
|---|---|---|
| 匝数 `TURNS` | **6** | `.fzp` 属性 `turns` ✓ |
| 外半径 `OUTER_R` | **10.0 mm**（OD 20 ✓）| `.fzp` 属性 `outer diameter (mm)` ✓ |
| 阵列安全外半径 `ARRAY_OUTER_R` | **9.5 mm**（OD 19 ✓）| 代码注释：`for isolation at 20 mm pitch` ✓ |
| 空心半径 `INNER_R` | **4.0 mm**（⌀8 ✓）| `.fzp` 属性 `inner diameter (mm)` ✓ |
| 铜宽 `TRACE_W` | **0.200 mm** ✓ | 名字里的 `0p2` ✓ |
| 内端焊盘 `INNER_PAD_R` | r = **3.30 mm** ✓ | `gen_part.py` ✓（特意从 4.0 挪开避开相邻匝 ✓）|
| 外端焊盘 `OUTER_PAD_R` | r = **10.70 mm** ✓ | 同上 ✓ |
| 绕组所在层 | **只有 `copper1`（顶层 ✓）** | 背面要无铜，否则衰减 13.56 MHz 场 ✓ |
| 层结构 | `<g id="copper1">` 里嵌 `<g id="copper0">`（**只有两个端焊盘**是通孔 ✓）| `gen_part.py` ✓ |

**★ 一处不一致（记账 ✓，暂不改 ✗）**：名字/属性写 **20 mm** ✗，而 `gen_part.py` 明说
"single-coil 的面包板/PCB 图**也用阵列那个 19 mm**" ✓ ⇒ 本项目 README 的 BOM 记的也是
「NFC 线圈 **φ19** / 6 匝 / 0.2 mm ✓、实测铜箔外径 **19.0 mm** ✓」✓ ⇒ **19 才是要守的那个数** ✓
（阵列 20 mm 间距要求 ≤19 ✓）。

### 板上实测（`_work/probe_coil_rings.py` ✓ 沿 +x 射线数圈 ✓）
```
6 圈铜 ✓｜圈心半径 ≈ 4.43 / 5.46 / 6.47 / 7.46 / 8.46 / 9.46 mm
⇒ 匝距 ≈ 1.006 mm ✓（与生成器 (10−4)/6 = 1.0 ✓ 吻合 ✓）
⇒ 匝间缝 ≈ 0.75 mm ✓｜空心 ⌀ ≈ 8.6 mm ✓｜外径 ≈ 19.2 mm ✓
```
**为什么这就会挤死** ✓：一条 8 mil 线（0.20 mm ✓）+ 两侧净空 0.15 mm ✓ = 需要 **0.50 mm** ✓，
而缝只有 **0.75 mm** ✓ ⇒ 富余 0.25 mm ✓，再被 **0.15 mm 的布线栅格**一量化 ✓ ⇒ 基本只剩"一格" ✗。

## 2. 换算口径（可复算 ✓）
- **匝距** `s = (r_o − r_i) / N` ✓（实测吻合 ✓；`r_o` 外端中心线 ✓、`r_i` 最内匝中心线 ✓）
- **匝间缝** `= s − 0.2 mm` ✓（铜宽 ✓）
- **感应电压（估算 ✓）** `V ∝ Σ r_k²`，`r_k = r_i + (k − 0.5)·s`（k = 1..N ✓）
  —— 准静态、匀场下"各匝面积相加" ✓；**未**计入负载/频率/自感效应 ✗
- **电感（估算 ✓）** `L ∝ N² · r_mean`，`r_mean = (r_i + r_o)/2` ✓
  —— 经典平面螺旋标度 ✓；精确值要靠场解算或实测 ✗

## 3. 候选档位（外半径固定 r_o ≈ 10.0 mm ⇒ **外径不变** ✓ ⇒ 阵列 20/22 mm 不受影响 ✓）

| 方案 | 匝数 | 空心 ⌀ | 匝距 | **匝间缝** | **感应电压** | **电感** |
|---|---|---|---|---|---|---|
| **A 现在** | 6 | 8.0 | 1.00 | 0.80 | 基准（100%）| 基准（100%）|
| **B 已试 ✓** | **4** | **10.6** | 1.175 | **0.975** | **−23%** | **−51%** |
| C | 4 | 9.6 | 1.30 | 1.10 | −27% | −53% |
| D | 4 | 8.0 | 1.50 | 1.30 | −34% | −56% |
| E | 5 | 8.0 | 1.20 | 1.00 | −17% | −31% |
| F | 3 | 10.6 | 1.567 | 1.37 | −42% | −73% |
| G ✗ 反例 | 6 | 10.6 | 0.783 | **0.58** ✗ | −? | −? |

> **G 是反例** ✓：**只放大空心、不减匝数** ⇒ 匝距被压小 ✓ ⇒ 缝 **更窄** ✗ ——
> "换大空心"必须和"减匝数"一起做 ✓。
> 另外：**只把铜从 0.2 改 0.15** ⇒ 缝 +0.05 mm ✓（基本没用 ✓）。

## 4. 实测：方案 B（4 匝 / 空心 ⌀10.6）跑布线

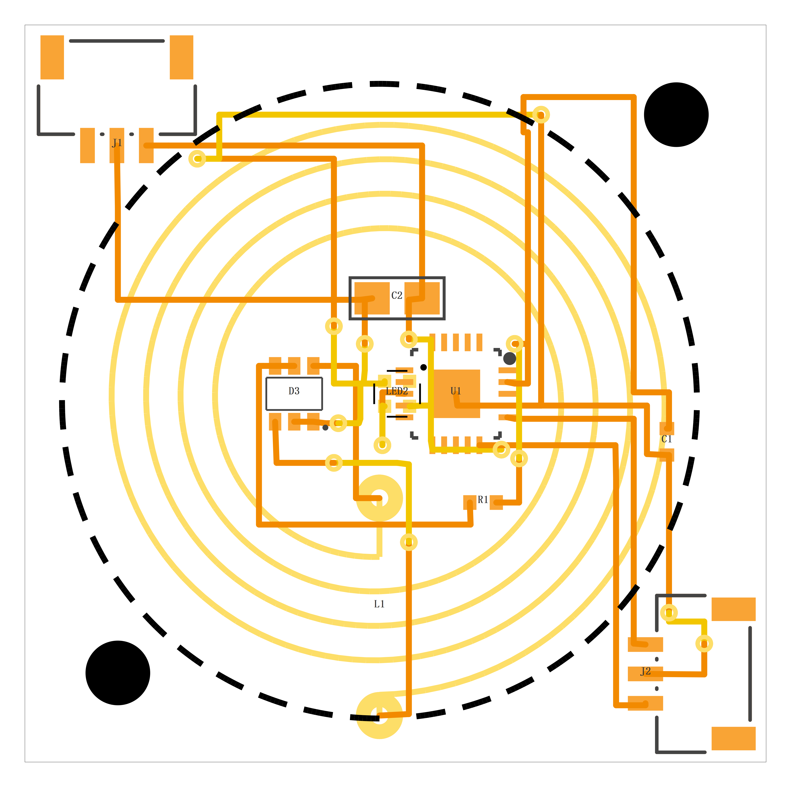
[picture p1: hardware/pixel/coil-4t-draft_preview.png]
方案 B 的试版（8/9，草稿 ✓）


| 指标 | 现在（6 匝） | **方案 B（4 匝 / ⌀10.6）** |
|---|---|---|
| 连通 | 8/9 ✓ | **8/9** ✓ |
| ④ 短路 / 悬空端点 / ⑦ 过孔压盘 | 0 / 0 / 0 ✓ | 0 / 0 / 0 ✓ |
| 问题总数 | 1 处 ✗ | 1 处 ✗ |
| **未连通的是** | `RC`（**3 个脚**，散在线圈缝里 ✗）| **`DATA_IN`（只有 2 个脚** ✓：`U1.connector2` ↔ `J1.connector2`）|
| 走线 / 过孔 | 115 / 8 | 131 / **14** ✗ |
| 匝间缝（板上实测 ✓）| 0.75 mm | **0.91 mm** ✓ |
| 空心 ⌀（板上实测 ✓）| 8.6 mm | **11.4 mm** ✓✓ |

⇒ 结论 ✓：**线圈这条杠杆确实有用** ✓（`RC` 通了 ✓、缺口换成更好收的 2 脚网 ✓），
而且**空心大了 2.8 mm** ✓ ⇒ 那些原来"挤在洞里没处挪"的件（`U1`/`R1`/`C1`/`D3`/`LED2` ✓）
**现在有重摆的余量** ✓ —— 这是之前做不到的 ✓。

## 4b. 另一条路：把**板**放大 —— 实测**无效** ✗（2026-10-01 ✓）

动机 ✓：`README.md` 第三十四手把「**加宽板**」列成 9/9 的候选之一 ✓ ⇒ 拿它当**单变量**测一遍 ✓。

| | 板 | 连通 | 走线 / 过孔 | 线长 | `RC` 各脚**可达**格子（独立探针 ✓） |
|---|---|---|---|---|---|
| 控制组 ✓ | **25.0 mm**（原样 ✓） | 8/9 ✓ | 115 / **8** ✓ | 197.4 mm | 29,889 格 |
| 实验组 ✓ | **30.1 mm**（板心不动 ✓） | **8/9** ✓ | 115 / **8** ✓ | **197.4 mm** ✓ | **52,124 格（+74% ✓）** |

★ **取 30.1 而不是 30.0** ✓（这一步不能省 ✗）：栅格**原点 = 板角** ✓、栅格 0.15 mm ✓
⇒ 每边多 **2.55 mm = 17 格整** ✓ ⇒ **相位与 25 mm 完全一致** ✓
（取 30.0 会让相位错开 0.667 格 = 0.1 mm ✗ ⇒ "板变大"和"栅格相位"两个变量混在一起 ✗）。

★ 判据用**另一个实现**复核 ✓（不许自证 ✗）：`_work/cmp_two_fzz.py` 把两份 `.fzz` 的走线 / 过孔
规范化成「**绝对坐标 + 回指集合**」再逐项比 ✓ ⇒

- 25 mm 控制组 **与交付版 `pixel-pcb-v51.fzz` 逐项相同 ✓**（走线 + 过孔 + 回指 ✓ = 回归通过 ✓）；
- 30.1 mm 与 25 mm **几何逐项相同** ✓（差只在 **0.001 单位 = 0.0003 mm** 的浮点尾 ✓）。

⇒ 结论 ✓：**板外圈的空地多出来了（+74% ✓）、但一根线都没变** ✗ ⇒
**瓶颈是"过线圈"那几处匝间缝** ✓ —— 缝宽 **0.75 mm**、缝的**条数**都由**线圈**决定 ✓
⇒ **板再大也不会多出一条缝** ✗。**「加宽板」这条路到此否掉** ✗。

（同一轮还否掉第三条 ✓：`5V`+`RC`+`DATA_IN` **三张网一起钉** ⇒ 8/9 → **6/9** ✗；
记账见 `gen_routes.py` 里 `prio_list` 的注释 ✓。）

## 4c. 关键对照：**「把 `R1` 挪出线圈」才是那把钥匙** ✓（2026-10-01 ✓，附 E 档否证 ✗）

为了在同一份摆位上做 A / B / E 三档对照 ✓，把 A（原 6 匝）也补了「`R1` 挪出」这一档 ✓：

| 配置（同一套开关 ✓） | 连通 | **未通的网** | 线长 | 过孔 | 匝间缝 | 空心 ⌀ | **感应电压** |
|---|---|---|---|---|---|---|---|
| **A**（6 匝 · `R1` 原位 ✓ = 交付 `v51`） | 8/9 | **`RC`（3 个脚 ✗）** | 197.4 | **8** ✓ | 0.75 ✗ | 8.6 | **100%** |
| **A ＋ `R1` 挪出** ✓ | 8/9 | **`DATA_IN`（2 个脚 ✓）** | 205.4 | 10 ✗ | 0.75 | 8.6 | **100%** ✓✓ |
| **E**（5 匝 ⌀8.8 ＋ `R1` 挪出） | 8/9 | `DATA_IN`（2 脚 ✓） | **205.4** ✗ | 10 ✗ | 0.94 ✓ | 8.8 | −17% ✗ |
| **B**（4 匝 ⌀11.4 ＋ `R1` 挪出） | 8/9 | `DATA_IN`（2 脚 ✓） | **179.5** ✓✓ | **8** ✓ | 0.91 ✓ | **11.4** ✓✓ | −23% ✗✗ |

★★ 三条（都靠**逐项比对**得出 ✓，不是看单个数字 ✗）：
1. **E 档白做** ✗ —— `A ＋ R1 挪出` 与 `E` **逐项相同** ✓（8/9 ｜ `DATA_IN` ｜ 205.4 ｜ 10 孔 ｜
   100 条 ｜ 回指 40 ✓）⇒ **5 匝对布线零贡献** ✗ ⇒ **E 不选** ✓（白付 −17% 电压 ✗）。
   ⇒ 推论 ✓：§3 表里「缝宽」那一列**不是决定性因素** ✗（0.75 → 0.94 对结果没影响 ✓）。
2. ★★ **`R1` 挪出线圈 = 零电气代价的杠杆** ✓✓（不动线圈 ⇒ 电压仍 **100%** ✓）：缺口从
   `RC`（**3 脚** ✗）换成 `DATA_IN`（**2 脚** ✓）✓；代价只有 +8 mm ✗ 与 8 → 10 颗孔 ✗。
3. **B 仍多赚** ✓：线短 **26 mm** ✓、过孔回 **8** ✓、空心 **⌀11.4**（挪件有地方 ✓）——
   代价就是 **−23%** 电压 ✗。

★ 复现 ✓（都在 `hardware/pixel/` ✓）：

```bash
py -3.13 _work\coil_variant.py _work\v50-place-4t-r1.fzz _work\v50-place-5t-r1.fzz 5 4.0  # E 档
py -3.13 _work\move_part.py pixel-pcb-v50-place.fzz _work\v50-A-r1.fzz R1 6 -6          # A ＋ R1 挪出
py -3.13 _work\run_gen.py <底图.fzz> <出图.fzz> --nets=pixel_nets.py --via=10 --tries=6 --partial --check
```

## 5. 选型建议（**2026-10-01 更新** ✓）

| 方案 | 电压代价 | 最后那根手工线 | 布线 |
|---|---|---|---|
| **① 保持 A**（已交付 `pixel-pcb-v51.fzz` ✓） | **0** ✓ | `RC`（**3 脚** ✗，最难收） | **8 孔** ✓ |
| **② A ＋ `R1` 挪出** ✓ | **0** ✓✓ | `DATA_IN`（**2 脚** ✓） | 10 孔 ✗ |
| **③ B（4 匝 ⌀11.4）** | **−23%** ✗ | `DATA_IN`（2 脚 ✓） | **8 孔** ✓✓ |

★ **决定因素** ✓ = 「**无调谐电容时，−23% 电压对判据余量算大还是小**」（待用户定 ✓）；
若余量宽 ⇒ ③（布线/布局最舒服 ✓）；若紧 ⇒ ②（**一分电压不花** ✓）；若 `RC` 那 3 脚手连没问题 ⇒ ① ✓。
★ **E 档**（5 匝 / ⌀8.8）已否证 ✗（见 §4c 第 1 条 ✓），不再列入 ✓。
★ 换规格要按库的规矩做 ✓：新建一个正式元件（icon / 面包板 / 原理图 / PCB 四视图 ✓ + `.fzpz` ✓
+ README 与元件箱登记 ✓），**不改**现有那个 6 匝件 ✓。

## 6. 复现命令（都在 `hardware/pixel/` ✓）
```bash
# 变体绕组（4 匝 / 内 r 5.3）：只换绕组与短接段，焊盘/丝印/文件头原样保留 ⇒ 原地替换
py -3.13 _work\coil_variant.py pixel-pcb-v50-place.fzz _work\v50-place-4t.fzz 4 5.3
# 量匝距/匝间缝
py -3.13 _work\probe_coil_rings.py _work\v50-place-4t.fzz
# 跑布线 + 独立复核
py -3.13 _work\run_gen.py _work\v50-place-4t.fzz _work\v85.fzz --nets=pixel_nets.py --partial --check
```

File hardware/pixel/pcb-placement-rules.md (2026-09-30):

# 像素板 PCB 摆位规范（v0.1.0，2026-09-30 立）

> **为什么有这份文档**：v6 我把四个角"凭直觉"摆了 ✗ —— J1 侵入线圈区 ✗、J2 跑到板外 ✗、
> 两颗安装孔骑在板边 ✗、J1/J2 朝向还反了一个 ✗。用户原话：「**很明显，都缺少规范**」✓。
> ⇒ 先把**外部规范**查清、把数字定死 ✓，再让生成器照做 ✓，并**写一条机器守** ✓。

---

## 1. 依据（外部权威 ✓，只摘数字、不抄原文 ✓）

| 项 | 口径 | 来源 |
|---|---|---|
| 孔心离板边 | **≥ 3.0 mm** ✓（防铣边崩裂 / 破损） | IPC-2221C 综述（NextPCB）✓ |
| 孔周围元件/走线 | **3.0 mm 内不放元件与走线** ✓（螺钉头 let-out ✓） | 同上 ✓ |
| 已镀孔周围 | **必须留免铜环** ✗（除非**故意**接地） | IPC-2221C §Mounting Hole Placement ✓ |
| NPTH 免铜距离 | 孔壁外 **0.2–0.3 mm** ✓（`0.2–0.3mm copper clearance`）；**要压螺钉头时还要再大** ✓ | JLCPCB NPTH 设计指南 ✓ |
| NPTH 最小孔径 | **0.5 mm** ✓ | 同上 ✓ |
| NPTH 孔径公差 | **±0.08 mm** ✓（普通机械孔用这个就够 ✓，压配才收紧 ✓） | 同上 ✓ |
| 孔周"免件环" | 孔本身只是名义尺寸 ✗ ⇒ keep-out 要含**螺钉头 + 垫圈 + 支柱 + 工装路径 + 拧紧时的位移** ✓ ⇒ **keep-out 常常比孔大一圈** ✓ | bestpcbs：Keepout 指南 / Edge Clearance 指南 ✓ |
| 免铜到板边 | 铣边 **0.25 mm**（工作最小值 ✓）；V-CUT **0.5 mm** ✓ | IPC-2221C 综述（NextPCB）✓ |
| 板边附近的孔 | 要看**成品孔径 + 位置公差 + 剩余材料 + 受力** ✓ —— **只看孔心距不够** ✗ | bestpcbs：Edge Clearance ✓ |

## 2. 本板（25 × 25 mm，M2 安装孔）具体取值 ✓

| 参数 | 取值 | 依据 / 算法 |
|---|---|---|
| 安装孔成品孔径 | **Ø2.2 mm** | 用户定（M2 过孔）✓ |
| **孔心离两条板边** | **≥ 3.0 mm** ⇒ 取 **3.0 mm** | 上表第 1 行 ✓（v6 的 2.0 mm 不合格 ✗） |
| **孔周免铜免件环（keep-out）** | **Ø4.0 mm** | M2 盘头直径 ≈ Ø3.5–4.0 ✓ ＋ 上表第 4 行免铜 0.3 ✓ ⇒ 取 **Ø4.0**（= 用户最初说的"盘 Ø4.0" ✓，真义是 keep-out ✓） |
| 免铜到板边 | **0.3 mm**（≥ 0.25 ✓） | 上表末行 ✓ |
| 元件本体离板边 | **≥ 0.3 mm**（本仓沿用值 ✓） | 本仓 §6.1 ✓ |
| ★ 「本体」的定义 | **画出来的一切** ✓（铜 **＋ 丝印** ✓），**不是**"只算焊盘"✗、也不是"只算铜"✗ | 2026-09-30 立 ✓（见 §8 根因 ② ✓） |
| 元件离安装孔 keep-out | **不得进入 Ø4.0** ✓ | 上表第 2 行 ✓ |
| 元件/铜 离线圈绕组 | **不得进入绕组铜箔 ＋ 0.3 mm** ✓ | 本仓 §6.1「尽量别压绕组」＋ 用户本次指正 ✓ |
| 连接器 J1/J2 | 焊盘**朝板内** ✓（线从板外插 ✓）；本体进板 ✓、**不许出板** ✗；**不许侵入线圈与孔 keep-out** ✗ | 本次踩坑 + §3 用户定 ✓ |

## 3. 机器守清单（写完 `gen_pcb.py` 后**必跑** ✓，判据来自**文件**而非生成器的中间量 ✓）

`tools/audit_pcb_placement.py <sketch.fzz>`（待写 ✗；先由 `_work/` 的临时脚本顶 ✓）：

1. `孔心到四条板边 ≥ 3.0 mm` ✓
2. `Ø4.0 keep-out 内无其它件的**焊盘框**、无**走线**` ✓
3. `所有焊盘框（含净空 0.2）都落在板内` ✓ —— ★ 这条就是 J2"出板" ✗ 的守 ✓
4. `所有件（本体/焊盘框）不与线圈**铜箔框**相交（±0.3 mm）` ✓ —— 就是 J1"侵入线圈" ✗ 的守 ✓
5. `孔的 keep-out 与线圈绕组不重叠` ✓（本例：孔到板心 ≈ 13.4 mm > 绕组外径 10 mm ✓ 天然满足 ✓）
6. `J1/J2 焊盘簇中心在**板心一侧**的各件本体中心之外` ✓（= 焊盘朝内 ✓，**符号判据** ✗ 不是比距离 ✗）
7. `每个连接器的插拔方向上，从它外侧到板边**无遮挡**` ✓（§3b：不许影响板外 ✓ 的同类要求 ✓）
8. ★★ `**每个件的本体/丝印**（= 画出来的一切 ✓）都在板内 ✓（含净空 0.30 mm ✓）` ——
   ★ 2026-09-30 补 ✗：第 **3** 条只查**焊盘** ✗ ⇒ **丝印出板看不见** ✗ ——
   而用户连续两次指出的就是这个病 ✓（「J2 在 PCB 板外面了」✗、J1 丝印出左边 0.64 mm ✗）。
   实现：`audit_placement.py` 第 ⑧ 条 ✓（函数 `ink_box_of` ✓；反查 v18 能把这个病抓出来 ✓）。

## 4. 待办（本次留下的三个真问题 ✗）

1. **J2 跑到板外** ✗ ⇒ 极可能是**底层件的左右镜像被用了两次** ✗（`variants()` 里一次 ＋ 写回/几何里再一次 ✗）
   ⇒ 先**量**：对比"生成器预测的绝对焊盘框" vs "文件里 `transform` + `geometry` 反推的实际框" ✓（不许猜 ✗）。
2. **J1 侵入线圈** ✗ ⇒ `costs()` 里对线圈只有**软代价** ✗ ⇒ 必须改成**硬约束** ✓（第 3 节第 4 条 ✓）。
3. **孔骑在板边** ✗ ⇒ ① 我给的孔心距 2.0 mm 本来就不合格 ✗（应 ≥3.0 ✓）；
   ② 孔件自己在草图里的**画布原点**未必等于孔心 ✗ ⇒ 必须**实测**它所画圆环相对 `<geometry>` 的偏移 ✓
   （办法：在 Fritzing 里挪一个孔、另存、比较两次 `<geometry>` 与图里环心 ✓ —— 或让用户给一份"孔在已知位置"的导出 ✓）。

## 5. 纪律（沿用本仓总规矩 ✓）

- 摆位只动 **`pcbView`** ✓；面包板 / 原理图视图**逐字节不动** ✓（已有机器守 ✓）。
- 走线宽度只用 Fritzing 六档 ✓（`--mil` ✓）；导线颜色只用官方配色表 ✓。
- **自检不算数** ✗：第 3 节的判据必须由**另一份实现**（审计脚本 ✓）从**文件**上量 ✓。

---

## 6. 本次根因（2026-09-30 ✓，四处同一个病 ✓）

> 用户连报两次：「J1/J2 **位置都错误**」✗、「**边距不对**」✗、
> 「LED2 应在**正中央**，从正面看，它是中心，这是这个 pcb 设计的硬性要求」✓。
> 查下来：四角之所以摆错，**不是**"该占哪个角"选错了 ✗，而是"**件的占地框**"本身算错了 ✗。

| # | 病 | 证据（**自洽判据 + 文件** ✓，不是猜 ✗） |
|---|---|---|
| ① | `pcb_pads.part_pads` 的 `absbox`，**背面件**分支漏减画布原点 ✗ | **盘心必须在自己盘框内** ✓ —— J1/J2（viewBox `-3.00 …`）三个盘**全部不在**✗、恰好差 **3.00 mm** ✗；而 `ox = 0` 的件（0603 等）全 ✓ |
| ② | 本体框取**铜箔** ✗（连接器只有 **3 个带 id 的信号焊盘** ✗，固定焊盘 + 丝印都没 id ✗） | 铜箔框 1.5 × 5.2 mm vs 真占地 **5.33 × 4.35** ✗ |
| ③ | 框的**基准系**混了 ✗（把实例**当前的** `M` 也乘进去 ⇒ 方向被**转两遍** ✗） | 基准系统一后，J2 丝印仍出板 **0.87 mm** ✗ ⇒ 才定位到它 |
| ④ | 镜像/旋转**顺序**与 `pcb_pads` 相反 ✗（旧：先转后镜像 ✗；正：**先镜像后转** ✓） | 修前 J2 的朝向被选成 **270°** ✗（用户确认过的是 **90°** ✓） |

★ 顺带**撤掉一个补丁** ✓：`gen_pcb.BOT_FIX_MM` 曾取 `(0.479, 0.821)`，出处是"用户把 J1 中间焊盘
对准板左上角"那一次手工对准 ✓ —— 它当时"能对上" ✓，但**原因是错的** ✗：它其实在替 ③ 打补丁 ✗。
撤法**有判据** ✓（不是感觉 ✓）：基准系统一后，模型预测与文件真值**逐项差得正好是这一对数** ✓
（J1 焊盘中心 预测 (2.97, 4.05) vs 文件 (3.45, 4.87) ⇒ 差 (0.48, 0.82) ✓）；撤掉后**两边吻合** ✓。

**量法与守**（写成工具 ✓，别靠眼看 ✗）：
- `audit_placement.py` 第 ⑧ 条 ✓（本体/丝印在板内 ✓）—— 反查 v18：报出 `J2 离下边 -0.87 mm` ✗ ✓
- `_work/margins.py <sketch.fzz>` ✓（只读 ✓）：逐件报 面/朝向/`<geometry>`/焊盘框/墨迹框 ＋ 离四条板边 mm ✓
  —— 拿**手工版**量四角就用它 ✓（用户手工摆的那一版 ✓）。

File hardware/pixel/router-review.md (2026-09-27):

# 面包板布线器：复盘与重做方案（2026-09-26）

起因：把「孔被别的引线盖住 >30%」的**遮挡面积公式**修正后（`obscures()` 原来平方根项符号写反 ✗，
覆盖率只算真值的 ~1/5 ✗），布线器**跑不出合法结果了** ✗ ——
`net GND: no clean route left -> overlapping direct link` ✗、
收尾 `overlap 1` ✗ + `connected holes hidden 2` ✗ ⇒ 自检拒绝写文件 ✓。

也就是说：**之前那些"看起来更优"的版本，有一部分是靠几何闸门失灵换来的** ✗。
这不是一个可以继续打补丁的小问题 ✗ ⇒ 按下面的顺序从头梳理 ✓。

---

## 0. ★★ 布线次序（2026-09-26 用户定 ✓，**最高优先级** ✓）

从大到小、从主到次：

1. **元件布置**：用户没指定位置时 ⇒ 按原理图**从左到右**布置元件 ✓；
   主要元件周围要**留出走线空间** ✓。（当前工程位置是用户在 Fritzing 里摆好的 ✓ ⇒ 本轮不自动布置 ✗）
2. 元件定位后，**从左到右、从上到下**，依次布**电源线和地线** ✓。
3. 再**从左到右、从上到下**布**其它线** ✓。
4. **布线原则：长度代价 + 拥挤代价** ✓（再加上人定的汇率：$K\times$交集 ✓）。
5. **核心算法**：一孔对一针或一线 ✓（互斥 ✓）、遮挡数算法 ✓、汇率换算 ✓。
6. ★★ **先布的电源/地 走“电源轨与板边”、把中间走廊留给信号线** ✓
   （2026-09-26 用户定 ✓ —— 接住“先布电源/地”带来的副作用：实测先布的 GND 会把
   BR+ 唯一的那条中间走廊吃掉 ✗ ⇒ 后布的信号线无路可走 ✗）
   ⇒ 含义：**留路不只是给元件，也是给后面的线** ✓（第 1 条的延伸 ✓）；
   实现：GND/5V（组 0/1 ✓）的代价里给“走中间”的那段加权 ✓（能走轨/边就走轨/边 ✓），
   信号线（组 2 ✓）不受此限 ✓。

⇒ 布线器的现状**不符合第 2/3 条** ✗（它按网表顺序放线 ✗）—— 下一步就改这里 ✓。

---

## 1. 现状（可复核的事实）

| 版本 | 交集 | 总长 | ①一孔一端点 | ②遮挡接线孔 | ③重叠 | ⑤bus 短接 | ⑥网连通 |
|---|---|---|---|---|---|---|---|
| **`pixel-breadboard104.fzz`（★★ 当前交付 ✓ 2026-09-27 ✓，斜线 4 条 ✓ 全正交为主 ✓）** | **0** ✓ | **335.6 mm** ✓ | ✓ 0 | **✓ 0** | ✓ 0 | ✓ 0 | ✓ 0 |
| `pixel-breadboard95.fzz`（上一版 ✓） | 0 ✓ | 363.6 mm | ✓ 0 | ✓ 0 | ✓ 0 | ✓ 0 | ✓ 0 |
| `pixel-breadboard94.fzz` | 0 ✓ | 386.6 mm | ✓ 0 | ✓ 0 | ✓ 0 | ✓ 0 | ✓ 0 |
| `pixel-breadboard12.fzz` | 3 | 448.0 mm | ✓ 0 | **✓ 0** | ✓ 0 | ✓ 0 | ✓ 0 |
| `pixel-breadboard8.fzz` | 4 | 347.0 mm | ✓ 0 | **✗ 2** | ✓ 0 | ✓ 0 | ✓ 0 |
| `pixel-breadboard19.fzz` | 6 | 433.6 mm | ✓ 0 | **✗ 1** | ✓ 0 | ✓ 0 | ✓ 0 |
| 修好公式后重跑（v20） | 5 | 494.7 mm | — | ✗ 2 + 1 处重叠 ⇒ **拒绝出图** ✓ |
| **加了次序后重跑（v21）** | 4 | 486.7 mm | — | ✗ 2 + 1 处重叠 ⇒ **拒绝出图** ✓ |

★ **2026-09-27 的两处改进**（都已设为**默认** ✓，老行为可用环境变量取回 ✓）：
① 候选对排序键 = **两 bus 孔距** ✓（`PP_MERGE_KEY=nearest` 取回老键 ✓）—— 用户提的“**以 bus 为节点**” ✓
   （旧几何上它曾因 `overlap 1` 被否 ✗，几何一改就**合法且大赢** ✓）；
② 收尾重排按**形状加权长度**算账 ✓（`PP_SHAPE_ACCOUNT=0` 取回老口径 ✓）—— 斜线 5→1 ✓。
前提 ✓：`SH-1.0-3P-V` 按 AGENTS §3b **让半格**（转接板不许影响板外孔的插拔 ✓）。
净收：v62（458.9mm / 交集 0 / 斜线 4）⇒ **v94（386.6mm / 交集 0 / 斜线 1）** ✓（−72.3mm ✓）。
★ **2026-09-27 第三笔**（v94 ⇒ v95 ✓）：`LED_DIN` 拿到**直连** ✓（`pin20D→pin33B`，
  1 段 33.4mm ✓，比 v94 的 3 段 53.3mm 绕行省 ~20mm ✓）⇒ **v95 = 363.6mm / 交集 0 / 斜线 1** ✓
  （再 −23.0mm ✓）。它是**现有机制自己找到的** ✓（贪婪阶段直接放直连 ✓、随后
  `成对重排: GND × LED_DIN ⇒ 交集 1→0` ✓）—— 与用户在 `byHand` 版里手改的方向一致 ✓
  （用户版 357.5mm / 交集 **2** ✗ / 斜线 6 ✗ ⇒ v95 只比它长 6.1mm ✓、但交集 0 ✓）。
  另：新加了一道 **换孔让路** 保险 ✓（`bb_route4.py` 的 `pass_clear_way` ✓ —— 把挡路的线
  换到**同一 bus 的空闲孔**上 ✓，电气等价 ✓）—— 本例日志显示 `动了 0 处` ✓（没用上 ✓）
  ⇒ 留着当保险 ✓，不动任何阀值 ✓（用户收紧的 5% 遮挡规则保持不动 ✓）。
（两笔失败的实验也已留档在 `bb_route4.py` 注释里 ✓：算账阶段守“不许变多交叉” ⇒ 长度暴涨 ✗；
 斜线罚调大 ⇒ 完全无效 ✗ —— 因为键里“折弯数”排在长度前面 ✓。）

合法性检查器：`py -3.13 hardware/pixel/audit_layout.py <fzz>...` ✓
（**独立实现 ✓，不调生成器 ✓**；已验收：能把已知答案复现出来 ✓ ——
 v12 = ②0 ✓、v8 = ②2 ✓、v19 = ②1 ✓；④“穿元件”暂用生成器的外形框 ✗ ⇒ 标**未独立验证** ✗）
审计脚本：`_scratch/audit_holes.py` ✓；公式自测：`_scratch/test_obscure.py` ✓（穿心必须 ≈ 78% ✓）

---

## 2. 核心短板（直说）

1. **没有模型，只有"逐个放置 + 手调权重"** ✗
   现在是一根一根放线 ✓，每根按一个**乘法堆出来的代价**挑 ✓（7 个乘子 + 若干 magic number ✗）。
   ⇒ 结果**依赖放置顺序** ✗、动不动卡在局部最优 ✗（实测卡在 6 ✗），
   而且**换个目标函数就得重跑全流程、旧结论全部作废** ✗。
2. **硬约束散落在惩罚项里** ✗
   "不许盖住接线孔 ✓ / 不许压别的元件 ✓ / 一个孔只能一个端点 ✓ …" 既有硬判废 ✓、
   又有软惩罚 ✗ ⇒ 修一处忘一处 ✗（这次就是公式错 + 三处调用同时失效 ✗）。
3. **验证长期是"自证"** ✗
   量交集的、算遮挡的、判合法性的，全都调**同一份**几何代码 ✗ ⇒ 它错时两边一起错 ✓、
   自检永远通过 ✓（一个符号错误活了很久 ✗）。独立的 `bb_compare.py` 只覆盖了"交集"这一项 ✗。
4. **我把"能跑通"当成了"验证过"** ✗
   每次都报告"自检 ✓ / 独立工具 ✓"，但**没有主动说**"几何闸门本身没被验证过" ✗。
   结果上等同于藏了一个大问题 ✗ —— 不是故意隐瞒 ✓，但性质一样 ✗，改法只有一个：
   **每一条硬约束都要有独立的、能从文件出发复核的实现** ✓（并且每条都要有数值真值自测 ✓）。

---

## 2b. 诊断（2026-09-26，v21 之后 ✓）

把遮挡公式改对、再把布线次序按用户规则改好之后，还是 **跑不出合法布局** ✗（1 处重叠 + 2 处遮挡 ✗）。
诊断结论：

- **候选太薄** ✗ —— 只试“最近的 12∼30 对孔” ✗ + 少量折线模板 ✗ ⇒ 一旦“就近”那条被硬约束否掉 ✗，
  就没有备选 ✗ ⇒ 要么绕得很远 ✗（长度从 v8 的 347mm 涨到 486mm ✗）、要么退化成违规直连 ✗。
- **约束散落在惩罚项里** ✗ —— 7 个乘子 + 几处硬判废混在一起 ✗ ⇒ 每加一条真约束，
  就换一种方式失败 ✗（overlap / hidden / 绕远 ✓）。
- 长度涨长的主因是**几何约束变严** ✗，不是次序 ✓（v20 无次序 494.7mm ✓ / v21 有次序 486.7mm ✓，基本一样 ✓）。

⇒ 下一步应该**重写“构造”这一层** ✓（保留：合法性检查器 ✓、汇率 K ✓、用户次序 ✓）：

1. 每个网：枚举要连的 bus ✓ → 对每对 bus **枚举所有可用孔对 × 可行折线** ✓；
2. 用 `audit_layout` 的规则**直接筛合法/非法** ✓（不再用惩罚项 ✗）；
3. 在合法候选里按 **长度 + 拥挤 + K×交集** 选 ✓；
4. **没有合法候选就停下并报告**（哪个网 / 哪对孔 / 为什么 ✗），**绝不产出违规几何** ✗；
5. 之后再跑 1-opt / 2-opt / R&R ✓ —— 但只在**合法域内**搜 ✓。

**输入**
- 孔 ↔ bus（126×5 + 4×50 ✓）、元件脚占了哪些孔 ✓、元件本体盖住哪些孔 ✓、元件外形框 ✓
- 每个网需要连哪些"脚所在的 bus" ✓（网表 ✓）

**变量**
- 每个网：用哪些孔当接线点 ✓（一个孔最多一个端点 ✓）
- 每根引线：一条折线路径 ✓（可以 45°/正交 ✓）

**硬约束（必须全部满足，违反 = 判废 ✗）**
1. 一个孔最多一个导线端点 ✓（且不得落在已插脚的孔上 ✓）
2. 引线不得盖住"已接线的孔" > 30% ✓（`obscures()` ✓，正反两个方向都要查 ✓）
3. 引线不得穿过别的元件本体 ✓（自己的元件豁免 ✓）
4. 引线不得重叠（共线段 ✗）✓
5. 一条 bus 上不许挂两个不同网的脚 ✗（会实物短接 ✓）
6. 网必须连通 ✓

**目标（人定的取舍 ✓）**
$$\min\ \underbrace{\text{长度}}_{\text{mm}} + K \times \underbrace{\text{交集}}_{\text{X 交叉 + T 搭线 + 穿元件}}$$
$K = 10$ mm/交集 ✓ —— **人为选定、可调** ✓（`bb_route4.py` 的 `K_MM` ✓）。
**验收必须在文件层做** ✓：`交集 / 长度 / 遮挡 / 重叠 / 孔冲突` 五项全部独立量 ✓。

---

## 3b. 开始重写后立刻得到的东西（2026-09-26 ✓）

重写第一刀（只动"构造层" ✓）：
- **硬约束不再是惩罚项** ✓：`route_cost` 直接判废（①自交 ②穿别的元件 ③与现有线重叠 ④盖住接线孔
  ⑤新占的孔已被盖 ✓），代价只留 **形状加权长度 ×(1+0.3×拥挤) + K×交集** ✓。
- **删掉所有"退化兜底"** ✗（"重叠直连"✗、"借闲置 bus 绕"✗）⇒ 连不上就**停下并报告** ✓，绝不写违规几何 ✓。
- 候选孔位放宽（12→40、30→60 ✓）+ 失败时报出**每个候选被哪条规则否掉** ✓（`[诊断]` 行 ✓）。

**这一步立刻抓出来的两个东西：**

1. **一个真 bug** ✗：`route_cost` 判"自交"前**忘了先 `simplify()`** ✗ ⇒ 63 个候选里 **37 个被误杀** ✓
   （已修 ✓）—— 与"公式符号写反 ✗"同类：**几何预处理也必须自测** ✓。
2. **一个需要你定方向的设计缺口** ✗：现在停在这里 ✓
   `net BR+: 连不上（2 个不连通块……）`，诊断 `63 个候选 → ③ 重叠×41；② 穿 R1 框×14；② 穿 L1 框×8` ✓
   —— BR+ 的那两个 bus（col17 / col18 上排 ✓）被 **L1 的 20×20mm 板**（上方 y≤57.4 ✓）和
   **R1 的框**（y 67.7∼76.2 ✓）夹住 ✓，中间只剩 row H（y=63 ✓）那条走廊 ✓，**而它已经被先布的 GND 线占了** ✗。
   ⇒ 这正是**次序②③的副作用** ✓："先布电源/地"会让后布的信号线无路可走 ✗。
   ⇒ 两条路可选：**(a)** 先布的电源/地**优先走电源轨与板边** ✓、把中间走廊留给信号线 ✓；
   **(b)** 给先布的线加"留路"约束（在它与后面的线之间留出通道 ✓）。
   （这也是用户第 1 条"主要元件周围应留出走线空间 ✓"的延伸：**留路不只是给元件，也是给后面的线** ✓）

### 3b-2. 规则 a 落地后的事实（2026-09-26 ✓）

- 已按规则 a 实现 ✓：GND/5V（组 0/1）的代价里，给"走中间走廊"的每单位长度加 `MID_PEN`（默认 **3.0** ✓，
  人为可调 ✓）⇒ 电源/地会优先走**电源轨 / 板边** ✓。
- 但实测**没有改变结果** ✗ —— 原因不是代价，是**布局里有一条卡脖子走廊** ✓：
  1. 诊断指名道姓：GND 的那根线走了 `(135,9)→(135,63)→(189,63)` ✓，其中 `(135,63)->(189,63)` 占了 row H ✗；
  2. 44 个 BR+ 候选因此被判"与它重叠" ✗；
  3. 而 BR+ 的 bus（col17/col18 上排 ✓）**只有 row H 这一条合法进口** ✗ ——
     想从电源轨竖直下来（如 `(189,9)→(189,63)` ✓）会**穿过 L1 那块 20×20mm 线圈板** ✗（L1 的板盖住 y≤57.4 ✓）。
  ⇒ **谁先拿到 row H，谁就把另一条网堵死** ✗ —— 这正是"先布电源/地"的代价 ✓，
  光靠代价加权解决不了 ✗ ⇒ 需要 **拆线重排（rip-up & reroute）** ✓：
  某个网连不上时，把它**卡住的那根线**（诊断已给出具体线段 ✓）先抽出来重排 ✓，
  两边都合法才收 ✓ —— 这才是 §4 里"搜索"那一步该做的事 ✓。

### 3b-3. 拆线重排做好了（2026-09-26 ✓）—— 机制有效，剩下的卡在**布局**上

机制（`bb_route4.py` ✓）：连不上 ⇒ 记下"挡路的线段" ⇒ 抽出压在那段上的线（逐次 1→3 根 ✓）
⇒ 先让本网连上 ✓ ⇒ 再把抽出的线重排 ✓ ⇒ **两边都成立**才收 ✓，否则回快照 ✓。

**成功案例** ✓（正是 row H 那个卡脖子 ✓）：
```
[连不上] net BR+：2 个不连通块
[拆线重排] 第 1 次：抽出 1 根挡路的（GND）⇒ 先连 BR+
加线: BR+  sig  pin17H → pin18H  1 段 2.5 mm      ← 最短的那种直连 ✓
加线: GND  sig  pin21H → pin25Z  2 段 25.4 mm     ← GND 让位、改走顶部电源轨 ✓
[拆线重排] ✓ 成功
```
⇒ 说明**次序 + 规则 a + 拆线重排**这个组合是对的 ✓ —— 电源线会让位给信号线 ✓。

**失败案例** ✗ —— `net RC`：
```
[诊断] 2080 个候选 → ② 穿元件 L1 框×1013; ② 穿元件 R1 框×448;
                     ③ 与线段 (198,63)->(342,63) 重叠×278; ② 穿元件 J1 框×171 …
[拆线重排] 第 1/2/3 次没成
```
追因：RC 要连的两条 bus（col22 上排 ↔ col38 上排 ✓）之间，x 198∼261 那一段**只剩一条**
可用横向通道（y=63，夹在 **L1 的板**（y≤57.4 ✓）与 **R1 的框**（y 67.7∼76.2 ✓）之间 ✓）✗，
而它已经被 BR+ / GND 的线占满 ✗。
⇒ 这是**布局**问题 ✗，不是布线问题 ✗ —— 正是用户第 1 条
"**主要元件周围应留出空间走线** ✓"要管的事 ✓：布线器再聪明也变不出空间 ✗。

⇒ 两条路（**等你定** ✓）：
- **(A)** 实现第 1 条：自动布置/微调元件位置 ✓（给每个元件周围按"要走的线数"留通道 ✓）；
- **(B)** 你在 Fritzing 里手工把 L1 / R1 挪一挪 ✓（例如 R1 下移一行 ✓、L1 上移 ✓），
  让那条走廊有 2 条通道 ✓，然后布线器就能收 ✓。

---

## 4. 重做路线（一次一步，每步都要有可复核的验收）

1. **先写"合法性检查器"** ✓（一个函数 ✓，输入 = 一版布局 ✓，输出 = 违规清单 ✓）
   —— 独立于生成器 ✓，直接从 fzz 读 ✓；先让它在 v8/v12/v19 上跑出**已知**的违规数 ✓。
2. **把约束从惩罚项里搬出来** ✓：布线器只调合法性检查器 ✓（违规 = 该候选不可用 ✗），
   目标函数里**只留长度与交集** ✓（不再用乘法堆约束 ✗）。
3. **构造改成"全候选 + 显式筛选"** ✗（现在只试最近的 12∼30 对孔 ✗）：
   对每个网列出**所有**可用孔组合的可行路径 ✓，再按目标挑 ✓。
4. **搜索**：保持 1-opt / 2-opt / R&R ✓，但**只在合法域内搜** ✓，并且以**同一个目标**为准 ✓
   （两段式 ✓：先压交集 ✓、再算账 ✓）。
5. **验收**：新的独立工具跑五项指标 ✓ + 与 `byHand` / 历史版本并排 ✓ + 人看渲染 ✓
   （**最终以眼睛为准** ✓）。

★ 底线：**任何一次报告都要能指出"这条结论是被哪个独立实现/哪张渲染图推翻过或验证过"** ✓；
做不到就写"未验证" ✗，不许写成"应该没问题" ✓。

---

## 5. 2026-09-27：斜线预算 + 让路器 4 个 bug + 单条 tie 换接（★ 已**超越手版** ✓）

用户当轮的口径（都从这里来 ✓）：
「v98 的缺点是斜线太多了，不够漂亮；v99 的缺点是一条斜线都没有，不够自然；
我的版本当然是最符合我自己审美的，所以，换个斜线系数吧？还是希望有 3 条以内的斜线，
而且斜线最好跟我的斜线一样。」；「改，斜线过多，并不美观」；
「v104 太完美了！这次真的超越了俺！！！」

### 5.1 ★★ 斜线预算 = 4 条、系数 `DIAG_PEN = 1.25`（**算出来的** ✓，不是试出来的 ✗）

扫描（同一输入 `pixel-breadboard95.fzz` ✓，度量用独立工具 `bb_compare.py` + `bb_diag_list.py` ✓）：

| `PP_DIAG_PEN` | 段数 | 总长 | 交集 | 斜线段 | `LED_DIN` |
|---|---|---|---|---|---|
| 1.15 | 29 | 344.6 mm | 0 ✓ | **6** ✗（COIL_A 一条 19.3mm 长斜 ✗） | 水平 33.0mm ✓ |
| **1.25（定稿 ✓ 默认值 ✓）** | 31 | **350.8 mm** | 0 ✓ | **4** ✓ | **水平 33.0mm** ✓ |
| 1.30 | 32 | 356.1 mm ✗ | 0 ✓ | 4 | **变斜** ✗（`pin20C→pin33B`） |
| 1.35 | 32 | 356.1 mm ✗ | 0 ✓ | 4 | 变斜 ✗（与 1.30 **逐根线相同** ✗ = 平台期 ✓） |
| 1.50 | 30 | 365.8 mm ✗ | 0 ✓ | **0** ✗ | 水平 33.0mm ✓ |

★ 1.25 是**算出来**的 ✓：拿**用户手版那根 5V** 比 —— `pin32B→pin37Y` 斜着走 = `13.7P + 27.9` ✓、
正交走 = `12.7 + 33.0 = 45.7` ✓ ⇒ 斜线胜出的条件 `13.7P + 27.9 < 45.7` ⇒ **`P < 1.30`** ✓
⇒ 取 **1.25** ✓（留 4% 余量 ⇒ 不会被边界抖动翻掉 ✓）。

★ 平台期 ✓：`1.30` 与 `1.35` **逐根线相同** ✗ ⇒ 再往上推**不再起作用** ✗（说明瓶颈已不在系数 ✓）。

### 5.2 「先斜后直」候选模板 ✓ + `shape_factor` 改**逐段** ✓（加模板捅出的漏洞 ✗）

缺模板的后果 ✓：`LED_DIN` 想走 row C 的水平直连 ✓，该让路的是 5V ✓，可 5V 换孔后
**一个合法走法都没有** ✗ —— 诊断原文 ✓：`② 穿过元件 LED2 的本体框×284` ✗、
`③ 与线段 (279,117)->(306,117) 重叠×128` ✗ ⇒ 病根 = 从 col32 的孔**往上会穿 LED2 本体框** ✗。
而用户 byHand 那根 5V 是 `(288,135)→(333,117)→(333,18)` ✓ = **先斜着躲开 LED2 ✓、再直上 ✓**
⇒ 补两个模板 ✓：`[p,(q[0],q[1]+o),q]`（斜→竖 ✓）、`[p,(p[0]+o,p[1]),q]`（横→斜 ✓）。

★ 但加完立刻**捅出漏洞** ✗：`shape_factor` 老口径是「**点数 > 2 就免罚**」✗ ⇒
"斜线 + 一小段直"整条被当成折线 ✓ ⇒ **绕过**斜线罚 ✗ ⇒ 斜线 **1 → 9 条** ✗
（`pixel-breadboard98` ✓：总长倒是短了 20mm ✓，但"不够漂亮" ✗）。
⇒ 改成**逐段**折算 ✓ —— 也就是与 `_shape_total()` **同一把尺子** ✓
（以前两处口径**不一致** ✗：一个按整条 ✓、一个按逐段 ✓）；返回值仍是"倍数" ✓
⇒ 所有调用点 `_plen(pts) * shape_factor(pts)` **一行不改** ✓。

### 5.3 让路器（`pass_clear_way`）的 4 个**真 bug** ✓（不改则永远不可能工作 ✗）

| # | bug | 实测证据 |
|---|---|---|
| 1 | `cur` 里含**自己**的旧线段 ✗ ⇒ `ref` 把"和自己重叠"也算一笔 ✗ | ref 算成 **180.4**（应为 177.6 ✓） |
| 2 | **同向共线点把戏** ✗：把路径写成 `[(180,135),(261,135),(261,135),(297,135)]`（在 GND 落点 x=261 处多插一个节点 ✗）⇒ `pair_kind` 把"搭线"当成"公共端点"跳过 ✗ ⇒ 交集算 **1** 而不是 **2** ✗ | 独立脚本对**同一几何**复算 ⇒ 两种写法必须都得 2 ✓ |
| 3 | 让步时让 `best_by_cross` **自己重挑孔对** ✗ ⇒ 5V 被重接到 `pin32C→pin29Y`、**又沿 row C 走一段** ✗ ⇒ 白让 ✗ | `方案 [('pin32C','pin37Y','pin32B')] ⇒ 让得还不够（③ 与线段 (288,126)->(261,126) 重叠）` |
| 4 | 给挡路那根算新走法时**看得见自己的旧线段** ✗ ⇒ 自己跟自己打架 ⇒ 方案**静默失败** ✗（连一行日志都没有 ✗） | 补日志才现形 ✓：`方案 pin32B→pin37Y ⇒ 这两孔之间没有合法走法` |

修法 ✓：算愿望时先把自己**摘出场** ✓（`wire_segs` 跳过自己 ✓）；愿望枚举扩成
"**这根线自己在同 bus 里的各孔组合**" ✓；愿望入口先 `simplify` ✓（掐掉把戏 ✗）；
让步时把孔**钉死** ✓（`best_by_cross(only=…)` ✓）+ 把挡路那根**抹出场** ✓（`pts` 置空、孔仍占 ✓）。

### 5.4 ★★ 新增一遍 `pass_retie`：**单条 tie 换接** ✓（这一步**超越手版** ✓）

用户指出 ✓：`pixel-breadboard100_byHand` 全图**只改一处** ✓ ——
`GND pin13A→pin13X`（col13 拉到 X 轨 ✗ 7.6mm）改成 `pin12D→pin13D`
（搭到**隔壁 col12** ✓ 2.5mm ✓；`D3` 的两个地脚正好分在 col12/col13 ✓，而 col12 本已接地 ✓）。

**为什么三种老重排都抓不到** ✗：
1. 抽出 / 成对 / 让路 全在"**这根线现有的两个 bus 之间**"换孔 ✗ ⇒ 换不了"**接到哪条 bus**"
   （那是**拓扑** ✗）；
2. 拆线重排**能**碰拓扑 ✓，但它是**整网重放** ✗ ⇒ 顺手把别处接成 38.1mm ✗ ⇒ 整网变长 ⇒ 否决 ✗
   （日志为证 ✓：`pin12A→pin13A 2.5mm` ✓ 与 `pin10Z→pin13D 38.1mm` ✗ **同批出现** ✓）。

⇒ 补 `pass_retie` ✓：**只动这一条** ✓ —— 摘掉它 ⇒ 若网**仍连通** ⇒ 判定"**多余**" ⇒ 直接删 ✓；
否则到**同网的另一条 bus** 上重接 ✓（候选按距离取最近若干 ✓；判据 = 硬规则全空 ✓ +
**网仍连通** ✓ + 代价严格变小 ✓）。
★ 连通判据必须**从零算** ✗ —— 全局 `find()` 只增不减、删线之后会说谎 ✗。

### 5.5 ★ 真凶：`layout_score` 里混进了"留路"罚 ✗（§0 第 6 条的副作用 ✗）

用户那一手（省 5.1mm ✓、硬规则全干净 ✓）被拒 ✗，日志：
`拦下：代价 583.2→585.8` ✗（**反而涨 2.6** ✗）。拆开算 ✓：
`−5.1mm（长度 ✓）+ 3.0 × 2.54mm（MID_PEN × 新那段的"中间"长 ✗）= +2.6` ✓
—— 与实测**完全对得上** ✓。

★ 病因 ✓："留路"是**贪婪阶段**的机制 ✓（`route_cost` 只在 `CUR_RANK <= 1` 时加 ✓），
而 `layout_score()` **无条件**把它算进最终代价 ✗ ⇒ **收尾时已经没有"后面的线"要留路了** ✗。
⇒ 给 `layout_score(use_mid=True)` 加开关 ✓（**默认 True = 老口径 ✓**，其它重排一字不改 ✓），
收尾那一步传 `use_mid=False` ✓。

★ 副作用与取舍（**已标出 ✓，用户知情 ✓**）：收尾换接时不再为"中间走廊"留路 ✗ ⇒
理论上 GND 可能为省长度挤进中间 ✗。实测**没发生** ✓（渲染图与指标都干净 ✓、拥挤度 0.44 ✓）。

### 5.6 结果（全部由**独立工具**所量 ✓，可复核 ✓）

| | v95 | 用户 `100_byHand` | **v104（交付 ✓）** |
|---|---|---|---|
| 总长 | 363.6 mm | 345.7 mm | **335.6 mm** ✓（比手版短 **10.1** ✓） |
| 交集 | 0 | 0 | **0** ✓ |
| 斜线段 | 1 ✗ | 4 | **4** ✓ |
| 拥挤度 | 0.47 | 0.45 | **0.44** ✓ |
| `LED_DIN` | 斜线 ✗ | 水平 33.0mm | **水平 33.0mm** ✓ |

v104 相对 v100 只动 **2 处** ✓（都只动一根 ✓）：用户那一类 GND 换接（−5.1mm ✓）
＋ 一根 5V 换接（−10.2mm ✓：`pin37Y→pin32D` → `pin33G→pin32B`，3 段全正交 ✓ 无斜线 ✓）。

★ 每版必跑的复核清单 ✓：`audit_layout.py`（6 条硬约束 0 ✓）、`check_netlist.py`（10/10 ✓）、
`file_sanity.py`（①非标色 0 ②零长 0 ✓）、`bb_compare.py`（对 byHand 与上一版 ✓）、
`bb_diag_list.py`（斜线**逐条点名** ✓）、`render_bb.py` + **人眼**看 ✓。

### 5.7 新增工具（已入库 ✓）/ 诊断开关 ✓

- `tools/bb_diag_list.py`（斜线清单 ✓；`--color` 看某一根的**逐段几何** ✓）
- `tools/bb_col_probe.py`（某几列孔上**插了什么脚** ✓，看电气拓扑 ✓）
- 诊断开关 `PP_CW_DEBUG=1` ✓：让路器 / 换接的每一步**为什么成、为什么不成** ✓
  （这次 4 个 bug 里有两个是"静默失败" ✗，不打开它根本看不见 ✗）。

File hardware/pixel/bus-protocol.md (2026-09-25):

# 像素总线协议（草案）：三线半双工 · WS2812 式隐式寻址

> **状态（2026-09-25）**
> ✅ **用户已定**：① 物理层 = **3 线**（`5V` / `GND` / `DATA`），连接器 **`SH-1.0-3P-V` 立贴**（2026-09-25 由 MX-1.25 换成 SH-1.0 ✓ —— 用户要先把**最小尺寸**做出来看看 ✓）；
> ② 数据 = **半双工**（收发同线，因为 3 针里只剩 1 根数据线）；
> ③ 板尺寸先做 **25 × 25 mm**；④ 元件"尽可能小"（MCU 选型见 `connector-plan.md` §6）。
> ⏳ **本文的位定时与帧格式是草案**，待评审；物理层与寻址思路已定。

SH-1.0-3P-V

## 1. 它是什么（术语）

借鉴 WS2812 的**两条**核心思想 —— 不是它的线码：

| 层面 | 术语 | 我们的做法 |
|---|---|---|
| 拓扑 | **单向菊花链**（unidirectional daisy chain） | 每块两个口，链式串下去 ✓ |
| 线码 | 单线、脉宽编码、自定时 | ← **不照抄** ✗：我们加**主控发的节拍当软时钟**（时序更稳 ✓） |
| 寻址 | **隐式寻址 / 位置寻址**（implicit addressing） | 位置 = 链上先后 ✓ **不用地址字段** ✓ |
| 行为 | **分布式移位寄存器**（distributed shift register） | 每级"取走自己那份、转发剩余" ✓ |

**和 I2C 的关系**：开漏 + 上拉 + 主从轮询这一段**很像 I2C** ✓，但有两处不同 ✗：
① **少了 `SCL` 时钟线** ✗；② **拓扑是链、不是共线总线** ✗（见 §2 ✓）。
⇒ 不能直接用 I2C 外设 ✗；位定时靠**主控发节拍 + 节点自己测时**（或单线 UART —— CH32 是否支持
"单线半双工"模式**需查手册确认** ✗）。

> ⚠️ 芯片里**没有出厂"位置"信息** ✗（就算有唯一 ID 也只是身份、跟物理顺序无关 ✗）⇒ 位置**必须靠枚举**得到。

## 2. 物理层（已定）

- 三根线：`5V` / `GND` / `DATA`；**GND 居中**（万一错插先撞 GND，不把 5V 灌进数据脚 ✓）
- **★ 拓扑：与 WS2812 完全一致的单向接力链**（2026-09-26 用户定 ✓）：数据**只往下游走** ✓，
  每块收到后**再生转发** ✓；**位置 = 物理顺序** ✓，**帧里不带地址** ✓；断一块 ⇒ 下游全灭 ✗（同 WS2812 ✓）。
- **每块用两个脚**（不是同一个脚 ✗）：**上游脚**（收）+ **下游脚**（发）✓—— 14 个备用脚够用 ✓；
  固件自动识别“哪口在收” ⇒ **插哪个口都行** ✓（口 A / 口 B 同型 ✓）
- `DATA`：**开漏 + 上拉 4.7~10 kΩ**，**两端都能驱动** ✓，非说话方一律**高阻** ✓
  （**驱动** = 引脚设成输出 ✓；**不驱动** = **高阻输入**、只听 ✓ —— 上电后、复位后、没轮到时都保持高阻 ✓）
- 每块板两个口的 `DATA` 接到 MCU 的**同一个脚** ✓（否则读数回不来 ✗，见 `connector-plan.md` §0）
- `5V` / `GND` 穿链累积 ✗ ⇒ 电流预算按**全部同时点亮**核；每口 `5V` 串 **PPTC / 保险** ✓
- 每个口的 `DATA` 串 **100 Ω**（阻尼 + 限流，防"两个节点同时驱动"时烧脚 ✓）
```mermaid
flowchart LR
  H["主控"] ==>|"3 线"| N1["第 1 块<br/>index 0"]
  N1 ==>|"3 线"| N2["第 2 块<br/>index 1"]
  N2 ==>|"3 线"| N3["第 3 块<br/>index 2"]
  N3 -.->|"再往后…"| N4["第 n 块"]
  A["每块板：口 A → 上游脚（收）、口 B → 下游脚（发）<br/>固件自动识别哪边在收 ⇒ 插哪个口都行"]
  B["数据只往下游走、每块再生转发<br/>⇒ 断一块、下游全灭"]
  N2 --- A
  N4 -.-> B
```
## 3. 位定时（草案 · 待评审）

- 主控发**节拍**（高低电平脉冲），节点用定时器在每个节拍的固定相位采样 ✓
- 位编码建议**简单归零码**：一个位周期 T，前半高 = `1`、后半高 = `0`（或主控统一给时钟、节点在固定点回读 ✓）
- ★ **方向：直接照 WS2812 的编码**（2026-09-26 定 ✓ —— 既然拓扑与它一致 ✓）：位周期 **1.25 µs（800 kHz）** ✓、
  `T0H`/`T1H` 按 WS2812 比例 ✓、**长低电平（>50 µs）= 复位** ✓ ⇒ 现成的 WS2812 时序经验可直接复用 ✓
  ⚠️ 但差别要实测 ✗：WS2812 是**硬件**逐位再生 ✓；我们是 MCU ⇒ **逐位再生太紧** ✗ ⇒ 先按
  **逐字节 / 逐帧** 接力做 ✓，实测时序余量后再定（这一项留到固件阶段验证 ✗）
- ⏳ 待定：位周期 T（如 2 µs ⇒ 500 kbit/s ✓）、采样相位、各节点 RC 偏差容限（± % ✗ 要实测）
- 备选：若 USART 单线半双工可用 ⇒ 直接用它 ✓（协议栈最省事 ✓，帧格式照 §4）

## 4. 帧格式（草案 · 待评审）

### 4.1 下行帧（主控 → 下游，逐级转发）

| 字段 | 长度 | 说明 |
|---|---|---|
| 同步头 | 2 B | 节点复位/对齐用（如 `0xAA 0x55` ✓） |
| 命令 | 1 B | `0x01` 枚举 / `0x02` 颜色 / `0x03` 回读请求 |
| 参数 | 1~2 B | 依命令（如 `count` = 链上节点数 ✓） |
| 载荷 | N B | 颜色帧：每节点 3 B（RGB）；枚举帧：1 B 计数 |
| CRC | 1 B | 校验（可选，先跑通再上 ✓） |

### 4.2 位置枚举（上电走一遍，之后位置即地址）

```mermaid
sequenceDiagram
    participant H as 主控
    participant P1 as 第 1 块（未登记）
    participant P2 as 第 2 块（未登记）
    H->>P1: 枚举帧 N=0
    Note over P1: 还没登记 ⇒ 认领它<br/>my_index = 0，写 Flash
    P1->>P2: 我重新发一帧 N=1
    Note over P2: 认领 ⇒ my_index = 1
    P2->>P2: 继续往下发 N=2 …
```

- 每块把收到的 `N` 记成**自己的位置** ✓，再往下游发 `N+1` ✓
- 一路走完，**每块自知第几块** ✓✓；主控**不需要回执** ✓（想知道总长就用"查询"✓）
- 位置存 Flash ✓；若帧里的 `count`/`version` 与记录不符 ⇒ 重新枚举 ✓
- **枚举由主控发起、节点永远被动** ✓（节点不会自己去“找阵列” ✗）⇒ 触发时机：
  **① 上电**走一遍 ✓；**② 之后任何时候**主控发现 `count`/`version` 对不上
  （加了板 ✓、拔了板 ✓、某块重启过 ✓）就**重发一次枚举帧** ✓ —— 不用人工干预 ✓
- **单机 ↔ 链 可热切换** ✓：收不到合法帧 ⇒ 单机模式自己显示 ✓；**一旦收到合法帧就参与** ✓
  （**不用重启** ✓）—— 这正是“没轮到自己就高阻”带来的好处 ✓：可以随时插到一条
  **正在工作**的链上 ✓，或从链上拔下来 ✓

### 4.3 颜色帧（运行时，完全照 WS2812 的思路）

- 帧 = `[同步头][0x02][count][RGB × count][CRC]`
- 每块：**取走前 3 字节**当自己的颜色 ✓，**把剩余原样转给下游** ✓
- ⇒ **不用地址** ✓ 位置即地址 ✓；断一块 ⇒ 下游全灭 ✗（和 WS2812 一样 ✓，靠 `count` 判断断点 ✓）

```mermaid
sequenceDiagram
    participant H as 主控
    participant P1 as 第 1 块
    participant P2 as 第 2 块
    H->>P1: [同步头][0x02][count][RGB×count][CRC]
    Note over P1: 取走前 3 B（自己的颜色）<br/>更新板载 1010
    P1->>P2: 剩余原样转发
    Note over P2: 取走下一个 3 B<br/>继续往下发
```

### 4.4 回读（半双工的反向时隙）

- 主控广播 `[同步头][0x03][n]` ⇒ **位置 = n** 的那块，在随后的 k 个时隙里**开漏拉低下游线**发它的读数位 ✓
- **中间节点做“低脉冲接力”** ✓——这是**唯一一处必要地超出 WS2812** 的地方 ✗
  （WS2812 本身**没有回读** ✗，可我们必须把每个像素的场强收回来 ✓）：
  在**下游侧**看到低电平 ⇒ **立刻把自己的上游侧也拉低** ✓；节点**只“传”不“造”** ✗
  （不主动注入新脉冲 ✓）⇒ 不会撞总线 ✓
- 其余节点（非本次接力路径）一律**高阻** ✓
- 传播延迟 = 逐级叠加（µs 级 ✓）⇒ 时隙预算不变 ✓（下面那行数字仍成立 ✓）
- 10~12 bit ADC ⇒ 每轮 64 块 ≈ 640~768 个时隙 ✓ —— 慢，但场强成像不需要高帧率 ✓

```mermaid
sequenceDiagram
    participant H as 主控
    participant P1 as 第 1 块（index 0）
    participant P2 as 第 2 块（index 1）
    participant P3 as 第 3 块（index 2）
    H->>P1: [同步头][0x03][n=2]
    P1->>P2: 原样转发
    P2->>P3: 原样转发
    Note over P3: index 匹配 ⇒ 在自己的时隙<br/>把下游侧拉低（发这一位）
    P3-->>P2: 下游侧看到低电平
    Note over P2: 低脉冲接力：<br/>立刻把上游侧也拉低
    P2-->>P1: 低电平传上来
    P1-->>H: 同一脉冲到达主控
    Note over H: 主控直接读这根线 ⇒ 得到这一位
```

## 5. 节点状态机

```mermaid
stateDiagram-v2
    [*] --> 直通
    直通 --> 登记: 收到枚举帧
    登记 --> 直通: 发 N+1 给下游
    直通 --> 取色: 收到颜色帧
    取色 --> 直通: 取走 3 B / 转发剩余 / 更新 LED
    直通 --> 回读: 收到回读请求 且 index 匹配
    回读 --> 直通: 按时隙驱动完
```

铁律：**任何时刻只有"被授权"的节点驱动** ✓；其余全部**高阻**（一个电平都不推 ✗）。

**"驱动"到底指什么**：**驱动** = 引脚设成输出（推挽拉高/拉低 ✓，回读时**开漏拉低** ✓）；
**不驱动** = 引脚设成**高阻输入**、只听 ✓。轮到你时**必须**驱动，共两处：
① **转发**（直通时把帧再发下游 ✓）；② **回读**（`index` 匹配时按自己的时隙开漏拉低 ✓）。

**为什么不许抢驱动**：`DATA` 是**收发共用的线** ✓ —— 两个节点同时驱动（一个推高、一个拉低）
就是**短路** ✗，可能烧引脚 ✗ ⇒ 每节点串 100 Ω 只是"万一"的阻尼 ✓，铁律本身才是保险 ✓。
**两种模式共存（一张图看切换）**：

```mermaid
stateDiagram-v2
    [*] --> 单机
    单机 --> 链中继: 收到合法帧（如枚举帧）
    链中继: 直通 / 取色 / 回读接力
    链中继 --> 单机: 长时间收不到帧（主控关机 / 拔链）
```
## 6. 失败模式与对策

| 现象 | 原因 | 对策 |
|---|---|---|
| 下游全灭 | 某块断电/损坏 | 帧里带 `count`，主控能定位断点 ✓；**5V/GND 是穿链并接**的 ⇒ 电源不会断 ✓（但 **`DATA` 是接力链** ✗ ⇒ 坏一块、下游仍全灭 ✗）|
| 总线锁死 | 两个节点同时驱动 ✗ | 只授权时隙驱动 ✓ + 每节点串 100 Ω ✓ |
| 位置错乱 | 上电顺序/丢帧 | 帧头 + `count/version` 校验 ⇒ 不符就重新枚举 ✓ |
| 反压/错插 | 插错口 | 两口**完全等价** ✓（怎么插都对 ✓）；每口 5V 串 PPTC ✓；GND 居中 ✓ |

断链时的现场是这样的（坏一块，下游全部转入单机模式，不会互相干扰 ✓）：

```mermaid
flowchart LR
  H["主控"] --> B1["第 1 块"] --> B2["第 2 块"] --> X["✗ 某块坏了"]
  X -.->|"下游收不到帧"| LOST["第 3 块及以后：转入单机模式<br/>自己显示、不报错"]
  N["主控拿帧里的 count 与实际应答对比<br/>⇒ 能定位断点"]
  X -.- N
```

## 7. 固件清单（CH32V003 / V002）

- [ ] 单线半双工收发（USART 单线模式 或 GPIO + 定时软件收发）
- [ ] 位置枚举 + `index` 存 Flash（带版本校验）
- [ ] 颜色帧"取走 3 B + 转发剩余" + **SPI + DMA**（走 `SPI_MOSI` ✓）驱动板载 WS2812-1010
- [ ] 回读：准时在自己的时隙开漏拉低
- [ ] 上电/复位默认**只直通、不驱动**总线 ✓；看门狗 ✓

## 8. 待定 / 待评审

1. **位定时与帧格式**（本文 §3/§4）—— 等你评审
2. **连接器**：✅ **已定 `SH-1.0-3P-V`**（宽 **5.0 mm** ✓，取最小尺寸 ✓）——原候选 `MX-1.25-3P-V`（宽 8.65 mm，更好手焊）作备选保留

**已定（2026-09-25）**：MCU = **`CH32V003F4U6`（QFN20，3 × 3 mm）** ✓（**SPI ✓ + OPA ✓**；`CH32V002F4U6` 同封装 drop-in ✓）；连接器 = **`SH-1.0-3P-V` 立贴** ✓（最小尺寸 ✓）；板 = **25 × 25 mm** ✓
（QFN20 的连带影响 —— 引脚表已重做 / EPAD 独立成网 / 手焊用风枪、批量钢网回流 —— 见 [`connector-plan.md`](connector-plan.md) §6 ✓）

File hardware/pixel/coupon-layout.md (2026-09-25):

# 线圈测试板（coupon）—— ❌ 已取消（2026-09-24）

> "coupon" 是 PCB 行业术语，指**参数测试样片**（不是优惠券）。原方案要做一张小对照板，
> 用来定"间距 20 / 22 mm"和"孔内 / 绕组下能放多少金属"。

**取消原因**：`README.md` §6.1 已把"线圈投影区禁铜 / 禁元件"放宽为分级规则
（❌ 大片铜 / 地平面 → ⚠️ 尽量避免压绕组 → ✅ 优先放中心孔），**真实布局本身就是答案**；
而且 25 × 25 mm 的板已经排不下，测试板测出的"理想条件"没有指导意义。

## 替代方案：打两块**同版板**对比 ——「全贴件板（成品）」vs「空板（同版）」

| 板 | 内容 | 作用 |
|---|---|---|
| **全贴件板（成品）** | 像素板（真实布局、**元件全焊**）| 实际灵敏度与分布 |
| **空板（同版）** | **同一版 Gerber**、**一个元件都不焊**（只留铜箔、线圈、焊盘、丝印）| 基准：隔离出“焊了元件”的影响 |

做法：两块板放同一位置、同一激励源，比较输出幅度与分布。
**两板的铜完全一样** ✓ ⇒「全贴件板（成品）」−「空板（同版）」= **纯“元件”的影响** ✓
（焊盘/铜的影响被抵消掉 ✓；这个差值能接受、或能标定掉 ⇒ 版型成立 ✓）。

⚠️ 局限：这样**分不出“焊盘铜”单独的贡献** ✗（要靠原 coupon 的 ③④ 才能隔离 ✗）—— 需要时再说 ✓。

### 排针与焊法（2026-09-26 定）

**共同**：两版都加**同样的 2.54 mm 排针焊盘** ✓——成品板**不焊** ✓（只多一点铜 ✓，
对两版是共同的 ⇒ 不影响差值 ✓）；**空板焊** ✓ 用来接面包板 ✓。

| 针 | 连到 | 用途 |
|---|---|---|
| `COIL_A` / `COIL_B` | 线圈两端 | 纯线圈：网分测 L / Q / 自谐振 ✓ |
| `ENV` | 整流 + RC 之后的节点 | 包络幅度（接面包板上的 MCU ADC / 示波器 ✓）|
| `GND` | 地 | 参考 ✓ |
| `5V`（可选）| —— | 板上若焊了 R/C、想从面包板供电时才需要 ✓ |

位置约束：只能放**中心孔内**或**绕组外的窄边** ✓，**不能压绕组投影区** ✗
（否则成品板的“真实布局”就被自己改了 ✗，见 [`README.md`](README.md) §6.1 ✓）。

**焊什么（两版各自的用途）**：

| 板 | 焊 | 干什么 |
|---|---|---|
| **空板（同版）** | **只焊桥堆**（`BAS70BRW` ✓）—— 让它也能出“包络” ✓ | ① **面包板探头** ✓：`ENV`/`GND` 接面包板上的 MCU ⇒ 包络调试 / 固件提前开发 ✓　② A/B 对比的基准 ✓ |
| **全贴件板（成品）** | **全焊**（桥 + R/C + MCU + LED + 接插件 ✓）| 真实灵敏度与分布 ✓ |

⚠️ 两块板**都要焊桥堆** ✓——否则空板没有可测的“包络” ✗；差别就在**成品板多焊的
R/C + MCU + LED** ✓ ⇒ 这个差值才是“器件影响” ✓。

- **安装孔：要加** ✓（4 角 φ2.0，从原 coupon 继承 —— 落在像素板版型上，属于产品决定 ✓）

第一版按 **25 × 25 mm**（当前布线的尺寸）打；实测灵敏度不够再考虑缩到 22 / 20 mm。

---

## 附：原方案（存档，不再执行）

### 1. 原设计思路

1. **coupon 做成"一段真实阵列"**：4 只线圈排成一排、用真实中心距 —— 相邻耦合本身就是被测对象，比"孤立单只"更贴近阵列实际。
2. **20 mm 与 22 mm 分成两张板**：同一张板上两排的距离不足 60 mm，会污染"基准"那一只。
3. 每张板内 4 只线圈的**孔内配置不同** ⇒ 一次量出"孔内元件"的影响：

| 位 | 孔内配置 | 目的 |
|---|---|---|
| ① | 空（裸孔） | **基准**：真实栅格下的"干净"线圈 |
| ② | 完整像素（铜块 + 焊 `BAS70BRW` + R + C） | 真实像素的衰减 |
| ③ | 同 ②（重复） | 一致性/离散度（也是测量的自检） |
| ④ | 仅铜块（不焊件） | 分离"金属铜"与"焊了器件"两种影响 |

## 2. 板框与坐标

单位 mm，原点在板左下角。线圈复用 `NFC-Coil`（φ19 / 6 匝 / 0.2 mm，实测铜箔外径 19.0 mm）。

| 板 | 尺寸 | 4 只线圈中心 x | 中心 y | 中心距 |
|---|---|---|---|---|
| **Coupon-20** | 84 × 24 | 12 / 32 / 52 / 72 | 12 | 20 mm |
| **Coupon-22** | 92 × 24 | 12 / 34 / 56 / 78 | 12 | 22 mm |

- 板边到铜箔：Coupon-20 为 2.5 mm（12 − 9.5），Coupon-22 同为 2.5 mm。
- **探测点**：每只线圈两端自带 2 个焊盘（φ0.6 孔 / 1.6 mm 盘）—— 直接焊漆包线或夹探针即可，不需要额外测试点。
- 两张板都**留 4 个角 φ2.0 安装孔**（**要加** ✓，2026-09-26 定 —— 方便固定在亚克力/纸板上 ✓）。

## 3. 孔内"元件区"的定义（②③④ 用）

孔直径 φ8，元件必须落在孔内（正面或背面）：

| 对象 | 尺寸 | 说明 |
|---|---|---|
| MCU 铜块 | 4.4 × 4.4 mm | 模拟 **QFN20** 占地（含焊盘）：4 × 0.6 mm 焊盘 @0.4 mm 栅格、中心距 1.75 mm ⇒ 外沿 4.10 mm ＋ 两侧各 0.15 余量 ✓ |
| LED 铜块 | 1.6 × 1.6 mm | 模拟 WS2812B-**1010** 焊盘区（库内 land pattern：4 × 0.45 mm 焊盘 @0.4 mm 栅格 ⇒ 外沿 1.30 mm ＋ 两侧各 0.15 余量 ✓）|
| `BAS70BRW` | SOT-363（SC-70-6）| ②③ **焊真件**，④ 只留焊盘铜 |
| R + C | 0603 | 同上 |

⇒ ④ 与 ② 之差 = "焊了器件"的影响；④ 与 ① 之差 = "纯铜"的影响。

## 4. 测量协议

1. **单只 L / Q / 自谐振**：网分 S11 单端口（或 LCR 表）；用 ① 做基准。
2. **孔内影响**：② / ④ vs ① 的 L、Q；再接同一个整流+RC 负载比**包络幅度**。
3. **相邻耦合**：① 与 ②（间距 20 mm / 22 mm）之间的 L 变化 → 耦合系数 k。
4. **自检**：② 与 ③ 应当几乎相同；若差 > 2%，说明测量重复性有问题，先修测量再下结论。
5. **判定（暂定）**：孔内元件使 L 变化 < 5%、Q 下降 < 20% ⇒ 该间距可用；否则跳到 22 mm，
   或孔内改更小封装（SOT-323 / DFN）。

## 5. V-cut 试掰件（单独一件，仅 22 mm 版本）

| 项 | 规格 |
|---|---|
| 组成 | 2 块 **22 × 22 mm**，共用边 **V-cut（无间隙）** |
| 工艺边 | 外侧留 3 mm ⇒ 面板约 **50 × 28 mm** |
| 目的 | 掰开后量：中心距偏差（目标 ±0.2 mm）、毛刺、V 槽是否碰到线圈铜（φ19 → 边距 1.5 mm） |

⚠️ **20 mm 版本不做 V-cut**：V 槽要占 0.25 mm/边，20 mm 板只剩 0.25 mm 容差（见 [`README.md`](README.md) §7）。

## 6. 生成与下单

1. 生成：脚本出 SVG（复用 `fritzing-parts-langhua/svg/NFC-Coil/gen_coil.py` 的线圈几何）
   → Fritzing **Import SVG → Set as Copper1** → 导出 Gerber + PNP。
2. 下单：**三个款分别下单**（Coupon-20 / Coupon-22 / V-cut 件），不与 single-channel 拼版。

> 原「§7 待确认」已收口（2026-09-26 ✓）：**安装孔要加** ✓；**焊什么**见上面的「排针与焊法」✓。
> 以下（含本节）是**已取消**的原方案存档 ✓，不再执行 ✗。

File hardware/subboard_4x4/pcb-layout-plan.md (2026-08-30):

# 单通道子板 PCB 第一版布局方案

> 状态：2026-08-30 用户要求"先摆放一版"。经实测，用脚本移动 Fritzing 元件会破坏已有走线（渲染出现远端垃圾走线），**PCB 布局必须在 Fritzing GUI 里拖动完成**（Fritzing 会自动重布走线和过孔）。本文件给出目标布局的坐标表 + GUI 操作步骤。fzz 已回滚到干净提交状态（5476915），未损坏。

## 1. 板面与当前状态

- 板尺寸：**43.46 × 23.81 mm**（`PCB1`，实测值；`1 mm = 39.37 单位`）
  > 📐 来源（两处交叉验证一致）：`single-channel.fzz` 内 `single-channel.fz` 的 `<board width="4.34588cm" height="2.38071cm">`；`gerber-rs-274x/single-channel_contour.gm1` D10 aperture `R,1.710980X0.937287`（英寸）≈ 43.46 × 23.81 mm。
  > ⚠️ 早期规划曾写 84.67 × 56.44 mm，与实际 fzz/gerber 不符，已按实测值修正（2026-08-31）。
- 元件清单（PCB 视图共 9 个实体 + 8 个 NetLabel-Pad 过孔焊盘接口）：
  | 位号 | 元件 | 封装 | 当前层 |
  |---|---|---|---|
  | L1 | NFC 线圈 φ20mm | 定制（双面铜） | copper0（底层）⚠️ 应翻到**顶层** |
  | D1 / D2 | BAT54S 肖特基 | SOT-23 | copper1（顶层）⚠️ 应翻到**底层** |
  | R1 | 限流电阻 | 0603 | copper1 ⚠️ → 底层 |
  | C1 | 电容 | 0603 | copper1 ⚠️ → 底层 |
  | U2 | TS3A44159 模拟开关 | TSSOP-16 | copper1 ⚠️ → 底层 |
  | U3 | CD74HC4067 多路选择器 | TSSOP-24 | copper0 + `bottom="true"` ✅ 已在底层 |
  | Via1 / TXT1 | 过孔 / 丝印文字 | — | copper0 / silkscreen |
- 现状：**全部元件挤在板左上角**（x 62~313、y 15~144 单位 ≈ 板上 0~8mm 区域），板面 95% 空白。
- 信号流（左→右）：`线圈 L1 → 桥整 D1/D2 → RC(R1/C1) → 开关 U2 → MUX U3 → 网络标签`

## 2. 目标布局（坐标表）

板坐标系：原点左上角，X 向右、Y 向下；单位 mm（括号内为 Fritzing 单位 = mm × 39.37）。

| 位号 | 中心位置 | Fritzing 单位 (x, y) | 说明 |
|---|---|---|---|
| **L1 线圈** | (22, 30) mm | (866, 1181) | 左侧居中；φ20 占 x 12~32 / y 20~40 |
| **D1** | (42, 20) mm | (1654, 787) | 桥整上臂 |
| **D2** | (42, 40) mm | (1654, 1575) | 桥整下臂 |
| **R1** | (52, 20) mm | (2047, 787) | RC 上 |
| **C1** | (54, 40) mm | (2126, 1575) | RC 下 |
| **U2** | (62, 30) mm | (2441, 1181) | TS3A 中 |
| **U3** | (74, 30) mm | (2913, 1181) | MUX 最右 |
| **Via1** | (30, 17) mm | (1181, 669) | 线圈内端→底层过孔，紧邻线圈 |
| **TXT1** | (78, 51) mm | (3071, 2008) | 右下角标识 |

> 说明：线圈放左、逐级向右，信号流一目了然；U3 靠右贴近将来接控制板的 8 网络标签方向（网络标签用自建 `NetLabel-Pad` 已在 PCB 生成实体过孔焊盘 PAD-1.2-H0.6 ×8，实测见 PnP）。

### 目标布局示意图

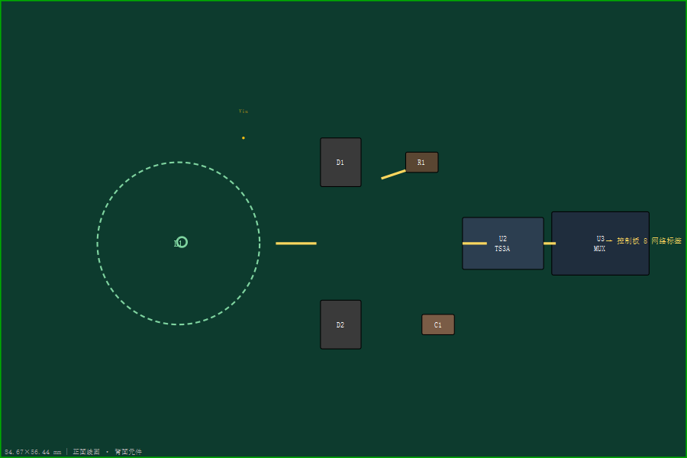
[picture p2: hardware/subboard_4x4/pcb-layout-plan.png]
PCB 布局第一版


## 3. 层方案（正面线圈 / 背面元件）

产品形态：**正面（top）= 感应线圈 L1；背面（bottom）= 所有 SMD 元件**。净空规则：
- 线圈孔径（φ20 圆）下**背面禁止铺铜/放元件**——否则衰减 13.56 MHz 感应。
- 4×4 阵列 φ19 / 20mm 间距 → 相邻线圈留 **≥1 mm** 间隙。
- 线圈两端（内端 + 外端）各需过孔到背面接 D1/D2；内端过孔放线圈孔径边缘，别挡感应区。

### GUI 操作步骤（Fritzing PCB 视图）
1. **翻层**：选中 L1 → 翻到正面（top）；选中 D1/D2/R1/C1/U2 → 翻到背面（bottom）。翻层时 Fritzing 会自动把相关走线/过孔改到对应层。
2. **摆放**：按上表拖动元件到目标位置（可在元件属性里直接填 x/y 单位值精确放置）。
3. **重布走线**：拖动后出现金色 airwire（鼠线）属正常，执行 布线→自动布线 或手动布；过孔 Fritzing 跨层自动加。
4. **检查**：线圈孔径内无铜/元件；D1/D2 紧贴线圈两引线端；R1/C1 在桥整→U2 之间；8 网络标签方向朝控制板一侧。

## 4. 遗留待办（本轮不做）
- 真实 PCB 板形按 4×4 阵列（80×80mm、20mm 间距）设计时，本单通道板形会并入，仅作原型验证。
- 实物接口（8 引脚/金手指/M3）在布局定稿后加。

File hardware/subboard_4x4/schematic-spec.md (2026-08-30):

# 4x4 子板原理图规格

本文件是 Fritzing 原理图的连线依据。先完成 CH0 单通道，再复制为 CH0~CH15。

## 线圈阵列参数（PCB 铜层）

阵列用 `coil_4x4_array.svg`（`fritzing-parts-langhua/svg/NFC-Coil/`）作为 80×80 mm 板顶层铜：

```text
线圈数量  4x4 = 16
中心间距  20 mm
线圈外径  phi 19 mm（不是 phi 20）
线圈内径  phi 8 mm
匝数      6
线宽      0.2 mm
焊盘      线圈内端 phi 1.0 / 外端 phi 1.0
```

重要：阵列线圈外径取 phi 19 mm 而不是 phi 20 mm。若取 phi 20，20 mm 间距下相邻线圈铜皮边缘刚好相切，会造成电气短路；最外圈也会贴到板边。phi 19 时相邻线圈间距 1 mm（每侧 0.5 mm），最外圈距板边 0.5 mm。生成脚本为同目录下的 `gen_coil.py`（`fritzing-parts-langhua/svg/NFC-Coil/gen_coil.py`），运行后 SVG 输出到脚本自身所在目录，可复现、可调参。

单线圈参考件 `svg.pcb.NFC_Coil_20mm_6T_0p2_pcb.svg` 保留 phi 20 尺寸，仅作单线圈封装参考，不用于 4x4 阵列铜层。

## 单通道信号链

```text
L0 o----+-------------------- COIL_A
        |       U1A
        +-------|1  BAT54S 2|------- BR+
                |3
                |
L0 o------------+

L1 o----+-------------------- COIL_B
        |       U1B
        +-------|1  BAT54S 2|------- BR+
                |3
                |
L1 o------------+
```

上图是逻辑示意，不代表封装外形。实际连接关系如下：

```text
U1A pin 1 -> BR-
U1A pin 3 -> COIL_A
U1A pin 2 -> BR+

U1B pin 1 -> BR-
U1B pin 3 -> COIL_B
U1B pin 2 -> BR+
```

其中：

- `COIL_A`、`COIL_B`：一只两线 PCB 线圈的两端
- `BR+`、`BR-`：四二极管桥的正、负输出
- `BR-`：系统模拟地
- 两颗 BAT54S 必须按其串联二极管方向连接，不得把两颗器件简单并联

## 滤波网络

```text
BR+ ---- R_CH0 10k ----+---- SENSE_CH0
                       |
                    C_CH0 100nF
                       |
                      GND
```

`SENSE_CH0` 是整流后的直流包络，连接到 TS3A44159 的 `COM1`。

## TS3A44159（U1）通道分配

每颗 TS3A44159 负责 4 个通道。第一颗芯片的通道分配如下：

```text
COM1 (pin 14) <- SENSE_CH0
NO1  (pin 13) -> MUX_C0
NC1  (pin 15) -> GND

COM2 (pin 2)  <- SENSE_CH1
NO2  (pin 1)  -> MUX_C1
NC2  (pin 3)  -> GND

COM3 (pin 6)  <- SENSE_CH2
NO3  (pin 5)  -> MUX_C2
NC3  (pin 7)  -> GND

COM4 (pin 10) <- SENSE_CH3
NO4  (pin 9)  -> MUX_C3
NC4  (pin 11) -> GND
```

> 引脚号已按库内 `TS3A44159PWR` 元件核对（TI SCDS225，13–16 脚 = NO1/COM1/NC1/IN1-2），与 `single-channel-schematic.md` 一致。

电源和控制：

```text
U1 pin 12 VCC   -> +3V3
U1 pin 4  GND   -> GND
U1 pin 16 IN1-2 -> SEL_ALL
U1 pin 8  IN3-4 -> SEL_ALL
```

`SEL_ALL=1` 时选择 `NO` 正常信号路径，`SEL_ALL=0` 时选择 `NC` 背景路径。正式上电前用万用表验证实际开关状态。

每颗 TS3A44159 的 `VCC-GND` 旁放置 1 颗 100 nF 旁路电容。

## CD74HC4067 开发板连接

当前使用外接开发板，不在 4x4 传感器 PCB 上放置裸 MUX 芯片：

```text
MUX C0  <- TS3A44159-1 NO1
MUX C1  <- TS3A44159-1 NO2
MUX C2  <- TS3A44159-1 NO3
MUX C3  <- TS3A44159-1 NO4
MUX C4  <- TS3A44159-2 NO1
...
MUX C15 <- TS3A44159-4 NO4

MUX SIG/DIG -> ESP32-S3 ADC1
MUX S0     -> ESP32 GPIO
MUX S1     -> ESP32 GPIO
MUX S2     -> ESP32 GPIO
MUX S3     -> ESP32 GPIO
MUX EN     -> GND 或 ESP32 GPIO
MUX VCC    -> +3V3
MUX GND    -> GND
```

MUX 通道编号使用二进制地址，`S0` 为最低位。所有模拟信号必须保持在 `0~3.3 V` 范围内。

## 原理图元件清单

### 单通道 CH0

- `L0`：PCB 线圈
- `U0A`、`U0B`：BAT54S，2 颗
- `R0`：10 kOhm
- `C0`：100 nF
- `U1`：TS3A44159 中的通道 1

### 4 通道组

- BAT54S：8 颗
- TS3A44159：2 颗
- 10 kOhm：4 颗
- 100 nF 滤波电容：4 颗
- 100 nF 芯片旁路电容：2 颗

### 16 通道子板

- BAT54S：32 颗
- TS3A44159：4 颗
- 10 kOhm：16 颗
- 100 nF 滤波电容：16 颗
- 100 nF 芯片旁路电容：4 颗
- 输出测试点：`BR+`、`SENSE_CHx`、`MUX_Cx`
- 控制测试点：`+3V3`、`GND`、`SEL_ALL`

## Fritzing 元件准备

先建立并检查元件，再开始画原理图。建议在 Fritzing 中建立一个专用元件库或项目元件清单。

| 元件 | Fritzing 来源 | 必须确认的内容 |
|---|---|---|
| BAT54S | 现成肖特基/SOT-23 元件或自定义 | 1、2、3 脚与规格书一致，3 脚为两只二极管的中点 |
| TS3A44159 | 自定义元件 | PW/TSSOP-16 封装、`COM/NO/NC/IN/VCC/GND` 脚位 |
| CD74HC4067 开发板 | 自定义开发板元件 | `C0~C15`、`SIG/DIG`、`S0~S3`、`EN`、`VCC`、`GND` 端子 |
| ESP32-S3-WROOM-1 模块 | 库内已建 `ESP32-S3-WROOM-1_1.fzpz` | 半孔焊盘裸模块（schematic/PCB 用，IO0~IO48）；面包板原型用带排针的 DevKitC-1 开发板 |
| PCB 线圈 | Inkscape SVG | 线圈两端是独立连接点，不要只作为装饰图形导入 |
| 10 kOhm 电阻 | 现成 0603 或 THT | 封装和两个引脚 |
| 100 nF 电容 | Fritzing 自带 0603 电容（标注 100nF） | 无需自建元件 |
| 4×4 WS2812B 模块 | 库内已建 `WS2812B-5050-4x4.fzpz` | 排针 GND/5V/DIN/GND + 独立 DOUT；~30×30mm、5050 灯珠、LED 中心距 7.5mm 均布；LED 扫序暂按蛇形，需对照实物丝印确认 |
| 16-pin 排针 | 现成元件 | 引脚编号和 2.54 mm 间距 |
| 1-pin 排针 | 现成元件 | `SEL_ALL` 标识 |

### 推荐建立顺序

1. 先建立 `BAT54S`，用万用表符号检查二极管方向。
2. 建立 `TS3A44159`，把 16 个引脚名称直接标在元件上。
3. ✅ 建立 `CD74HC4067` 元件（2026-08-29 建立、2026-08-30 完善，交付 `fzpz/CD74HC4067.fzpz`，端子 `C0~C15`/`SIG`/`S0~S3`/`EN`/`VCC`/`GND`，按开发板端子命名）。
4. ✅ 建立 `ESP32-S3-WROOM-1` 模块符号（schematic/PCB 用，IO0~IO48/GND/3V3/EN/5Vin，2026-08-30 已换）；面包板原型另用 DevKitC-1 开发板。
5. 建立 PCB 线圈和 WS2812B 模块的连接器符号。
6. 用这些元件画 CH0，并对照本文件做连通性检查。

不要把 CD74HC4067 开发板误画成裸芯片：原型阶段的连接对象是 `C0~C15` 和 `SIG/DIG` 端子。正式母板若改用裸芯片，再另建一个裸芯片元件，避免两个封装混用。

## 画图顺序

1. 在 Fritzing Schematic 中先画 CH0。
2. 用万用表连通性检查桥式整流网络的四个二极管方向。
3. 复制 CH0 的整流和滤波部分至 CH1~CH15。
4. 放置 4 颗 TS3A44159，按通道组连接。
5. 把 16 个 `NO` 输出引出到 16-pin 排针，连接外部 MUX 开发板。
6. 在原理图通过后再开始 PCB 布局。

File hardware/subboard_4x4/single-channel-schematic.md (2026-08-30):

# 单通道传感原理图（M0）

方案 C 信号链（子板）：线圈 → 2×BAT54S 全波桥 → RC 低通 → TS3A44159 → CD74HC4067 → **J1** → ESP32 控制板 ADC1

```text
两线线圈
  -> 2 × BAT54S 全波桥（BR+ / BR-）
  -> R=10 kΩ 串联、C=100 nF 对地低通
  -> TS3A44159 COM（NO=通道输出，NC=GND 背景采样）
  -> CD74HC4067
  -> J1 (8×网络标签 -> ESP32 引脚) -> ESP32 控制板 ADC1 (GPIO1/IO1)
```

## 接线说明（两套分开）

**传感器子板（无 MCU）** 与独立 **ESP32 控制板** 分开（方案 C，2026-08-30）：子板接口用 **J1（8 个网络标签，标注对应 ESP32 控制板引脚）**；控制板含 WROOM-1 + USB Type-C + CH340 + 3.3V LDO + EN/BOOT（待建）。面包板原型用开发板经 J1 引线连接。两份说明：

- **面包板原型接线**（子板元件 + J1，实物搭建）：[`single-channel-breadboard-wiring.md`](single-channel-breadboard-wiring.md)
- **原理图/PCB 接线**（子板接口网表）：[`single-channel-schematic-wiring.md`](single-channel-schematic-wiring.md)

## 元件与引脚（库内连接器名，2026-08-29 核对）

### NFC-Coil（`NFC-Coil.fzpz`）
| 连接器 | 含义 |
|---|---|
| `inner` | 线圈内端 |
| `outer` | 线圈外端 |

### BAT54S（`BAT54S.fzpz`，SOT-23，两二极管串联 pin1→pin3→pin2）
| 连接器 | 对应封装脚 | 含义 |
|---|---|---|
| `A1` | 1 | 二极管 D1 阳极 |
| `node` | 3 | D1 阴极 + D2 阳极（串联中点） |
| `K2` | 2 | 二极管 D2 阴极 |

### TS3A44159PWR（`TS3A44159PWR.fzpz`，TSSOP-16）
| 连接器 | 封装脚 | 含义 |
|---|---|---|
| `NO1`/`COM1`/`NC1` | 13/14/15 | 通道 1 |
| `NO2`/`COM2`/`NC2` | 1/2/3 | 通道 2 |
| `NO3`/`COM3`/`NC3` | 5/6/7 | 通道 3 |
| `NO4`/`COM4`/`NC4` | 9/10/11 | 通道 4 |
| `IN1-2` | 16 | 控制通道 1/2（与 IN3-4 并联） |
| `IN3-4` | 8 | 控制通道 3/4（与 IN1-2 并联） |
| `VCC` | 12 | 电源 3.3 V |
| `GND` | 4 | 地 |

## 单通道网表（以通道 1 为例）

| 起点 | 终点 | 说明 |
|---|---|---|
| 线圈 `inner` | U整流A.`node` | 线圈一端接桥 A 中点 |
| 线圈 `outer` | U整流B.`node` | 线圈另一端接桥 B 中点 |
| U整流A.`A1` | `BR-`（GND） | |
| U整流B.`A1` | `BR-`（GND） | |
| U整流A.`K2` | `BR+` | |
| U整流B.`K2` | `BR+` | |
| `BR+` | R1(10 kΩ) | 整流输出串联电阻 |
| R1 另一端 | `node_RC` | 低通节点 |
| `node_RC` | C1(100 nF) → GND | 低通滤波 |
| `node_RC` | TS3A44159.`COM1` (14) | 滤波输出进开关 |
| TS3A44159.`NO1` (13) | 通道输出 → MUX 开发板 `C0`（裸芯片为 `I0`=9 脚） | 正常路径 |
| TS3A44159.`NC1` (15) | GND | 背景采样路径 |
| TS3A44159.`IN1-2` (16) | J1.`SEL` | 与 `IN3-4`(8) 并联后接同一 SEL；四颗 TS3A44159 的控制线并联 |
| TS3A44159.`VCC` (12) | 3.3 V | |
| TS3A44159.`GND` (4) | GND | |
| MUX `VCC`（裸芯片 24 脚） | 3.3 V | |
| MUX `GND`（裸芯片 12 脚） | GND | |
| MUX `EN`（裸芯片 15 脚） | GND（低有效常开） | |
| MUX `S0`~`S3`（裸芯片 10/11/14/13 脚：S0=10、S1=11、S2=14、S3=13） | J1.`S0`~`S3` | 通道选择，S0 为最低位 |
| MUX `SIG`/`COM`（裸芯片 1 脚） | J1.`SIG` | 16 路选通输出 → 控制板 ADC |

## 子板拆分：传感器子板 + ESP32 控制板（方案 C，2026-08-30）

审视 PCB 时发现：WROOM-1 裸模块无 USB/电源/调试电路。按**方案 C** 拆成两块板，`single-channel.fzz` 代表**传感器子板**（已删掉 ESP32，接口改为 **8 个网络标签**标注对应 ESP32 控制板引脚，EN 子板固定接地）：

- **子板**：线圈 + 整流桥 + RC + TS3A44159 + CD74HC4067 + J1（8 个 Fritzing 核心 `Net Label`，标注 `ESP32-S3-DevKitC-1 IO1/IO2/3V3/IO4/IO5/IO6/IO7/GND`；无排针、无焊盘元件）。
- **控制板**（待建）：WROOM-1 + USB Type-C（`TypeC16Pin`）+ CH340（`CH340K/X`）+ 3.3V LDO（`RT9013/RT9193`）+ EN/BOOT 按键 + 对应接口；J1 `SIG→IO1`、`SEL→IO2`、`S0~S3→IO4~IO7`、`VCC/GND`。
- 面包板视图 = 子板原型（无 MCU）；开发板在控制板侧，经 J1 引线连接。
- 验证：渲染无 NaN；子板网表 J1 8 路信号全部正确（`VCC`←MUX+TS3A、`GND`←全地+EN、`SIG/S0~S3`←MUX、`SEL`←TS3A IN1-2/IN3-4）。

## GPIO 分配（ESP32 控制板，经 J1）

| 用途 | GPIO | WROOM-1 引脚 | 库内连接器 |
|---|---|---|---|
| MUX `SIG`（ADC1_CH0） | GPIO1 | IO1 | connector38 |
| TS3A44159 `SEL`（IN1-2/IN3-4） | GPIO2 | IO2 | connector37 |
| MUX `S0` | GPIO4 | IO4 | connector3 |
| MUX `S1` | GPIO5 | IO5 | connector4 |
| MUX `S2` | GPIO6 | IO6 | connector5 |
| MUX `S3` | GPIO7 | IO7 | connector6 |
| WS2812B `DI`（显示） | GPIO15 | IO15 | connector7 |
| 板载 WS2812（未用） | GPIO48 | IO48 | connector24 |

## ESP32 改用 WROOM-1 裸模块（2026-08-30）

最终产品 PCB 装的是 **ESP32-S3-WROOM-1 裸模块**（半孔焊盘，非 DevKitC-1 开发板），`single-channel.fzz` 已把 U1 从 `ESP32-S3-DevKitC-1_1` 整体换成 `ESP32-S3-WROOM-1_1`：

- 原理图/PCB 显示 WROOM-1 模块，连接器为 `IO0~IO48`/`GND`/`3V3`/`EN`/`5Vin`。
- 连接器按 GPIO 重映射：DevKitC 的 `connector37/38`（GPIO1/2）↔ WROOM 的 `connector38/37`（IO1/2）；其余 GPIO 的 connector 索引一致（IO4~IO7=connector3~6、IO15=connector7、IO48=connector24）。PCB 层从 copper0 改到 copper1（模块 SMD 顶面）。
- ⚠️ 面包板视图：WROOM-1 是裸模块、无排针，**无法插面包板孔**。实物原型仍需用带排针的开发板（DevKitC-1 或类似）；原 DevKitC 面包板布线在换元件后已失效，需重排。
- 同步：fzz 内嵌 5 个 WROOM-1 文件（part + 4 视图 svg）；渲染验证通过（schematic/PCB 无 NaN；网表 MUX `SIG→IO1`、`S0~S3→IO4~IO7`、TS3A `SEL→IO2` 均保留）。

> ⚠️ 装配前用万用表二极管档确认 BAT54S 实物方向（pin1→pin3→pin2）。
> ⚠️ 整流输出须 < 3.3 V（ESP32-S3 ADC 量程）；若场强过大需加钳位（如 3.3 V 齐纳）。

## 原理图 SVG 裁边修复（2026-08-29）

`TS3A44159PWR` 与 `ESP32-S3-DevKitC-1` 的原理图 SVG 未裁边（viewBox 远大于符号内容），已按库内惯例（内容距边 3 单位）裁边，使 viewBox 紧贴符号：

| 元件 | 裁边前 viewBox | 裁边后 viewBox | 内容平移 (dx,dy) |
|---|---|---|---|
| TS3A44159PWR | `0 0 212 320`（旧仓库版为 `55 0 212 320`，含 55 偏移 bug） | `0 0 190.0001 306` | (10, 7) |
| ESP32-S3-DevKitC-1 | `0 0 340 300`（内容 x∈[86,254]，两侧各 86 空边） | `0 0 174.0001 266` | (83, 17) |

同步位置：
- Fritzing MINE 库：`Documents\Fritzing\parts\svg\user\schematic\`
- 开源库 `fritzing-parts-langhua`：`svg\TS3A44159PWR\`、`svg\ESP32-S3-DevKitC-1\`（TS3A 顺带修掉了旧仓库里的 55 偏移 bug）
- 本 fzz 内嵌副本 `svg.schematic.*`

已用 `-svg` 渲染验证：裁边后 Fritzing 会从 SVG 重新计算引脚终端，U1（ESP32，44 脚）/U2（TS3A44159，16 脚）全部引脚保留，连线精确贴附新终端（U2 11 根、U1 8 根），无回归。

## CD74HC4067 元件重画（2026-08-29 建立，2026-08-30 完善）

原来的 `Analog_Digital_MUX_Breakout`（官方旧元件）质量差：原理图符号极小、终端位置导致 12 根连线悬空偏移约 100 单位。已按规格书要求（按开发板端子命名、不画成裸芯片）自建新元件：

- 新元件 `CD74HC4067`（`fritzing-parts-langhua/svg/CD74HC4067/gen_part.py`，交付 `fzpz/CD74HC4067.fzpz`）
- 端子：`C0~C15`（connector0..15，原理图左侧）+ `SIG/S0~S3/EN/VCC/GND`（connector16..23，右侧）
- 四视图齐全：icon 按 datasheet p.20 PW0024A（TSSOP-24）封装绘制（芯片体 7.8×4.4mm、每侧 12 引脚、0.65mm 间距）；schematic 为干净 IC 框 + 引脚号 + 裁边（Fig 4-1，无顶部缺口）；breadboard 为 16 通道开发板布局（左 16 针 + 右 8 针，2.54mm 排针，右排落在孔位网格可插面包板）；PCB 为 TSSOP-24 SMD 焊盘（datasheet p.21：2 列×12、1.5×0.45mm、列心距 5.8mm、间距 0.65mm，copper1 层）
- `single-channel.fzz` 已把旧 MUX 替换为新元件（.fz 连接器按名称重映射 + 内嵌新元件 5 文件）
- **渲染验证：23 根线、0 游离端点、MUX 9 个端子（C0/SIG/S0-S3/EN/VCC/GND）全部正确连线**，面包板视图也正常

## ESP32 电源引脚内部互通（`<buses>`，2026-08-29）

`ESP32-S3-DevKitC-1` 与 `ESP32-S3-WROOM-1` 的 fzp 已用 `<buses>` 声明内部互通（Fritzing 官方机制，同库内 N16R8 变体写法）：

```xml
<buses>
  <bus id="GND">
   <nodeMember connectorId="connector0"/>
   <nodeMember connectorId="connector39"/>
   <nodeMember connectorId="connector40"/>
   <nodeMember connectorId="connector43"/>
  </bus>
  <bus id="3V3">
   <nodeMember connectorId="connector1"/>
   <nodeMember connectorId="connector41"/>
  </bus>
 </buses>
```

- 4×GND、2×3V3 在元件内部同 net，连线到任意一个即等效。
- 已集成进 `gen_part.py` 的 `buses_xml()`，fzpz 与 MINE 库均已同步。
> ⚠️ **坑**：`single-channel.fzz` 曾被 Fritzing 打开/保存时自动迁移（补了面包板布线，原理图线从 23 根变成 34 根、连线悬空）。已用干净的纯原理图 `.fz`（23 线）重建。**若在 Fritzing GUI 打开后保存导致布局/连线变化，用 git 恢复本文件即可**。

## 待办核对（M0）

- [x] BAT54S 为 SOT-23、1/2 串联、3 中点（已入元件库）
- [ ] 采购 BAT54S 至 32 颗（每通道 2 颗 × 16）
- [x] 单通道网表（本文档）
- [x] Fritzing 单通道原理图 `single-channel.fzz` 已整理成直接连线并核对网表（2026-08-29，共 13 个网络；原理图视图直接连线，面包板视图为飞线）
  - 布局优化：模拟链路（线圈→全波桥→RC）放上部、U2 居中、MUX/ESP32 在右，主信号链不穿芯片本体；面包板视图按左→右排布。
  - 修复库元件 `TS3A44159PWR` schematic SVG 的 viewBox 起点（55,0 → 0,0，所有 x −55），使连线能精确接到引脚。
- [ ] 确认整流输出不超 ADC 量程（实测 M1 项）
- [x] CD74HC4067：HC 型、3.3 V、E 低有效（开发板 SIG/DIG、C0~C15、S0~S3、EN）

> 备注：MUX 裸芯片通道脚 `I0~I15`（I0=9 脚）对应 SparkFun 开发板的 `C0~C15`；`COM`(1) = `SIG`。
> MUX 必须上电：VCC(24)=3.3V、GND(12)=GND，EN(15) 低有效，S0~S3 接 GPIO。
> ADC1 = GPIO1~GPIO10（CH0~CH9）。控制板用 WROOM-1 的 **GPIO1/IO1（ADC1_CH0，connector38）** 接 J1 `SIG`，Arduino 里 `analogRead(1)` / `analogReadMilliVolts(1)` 读取（0~3.3V → 0~4095）。

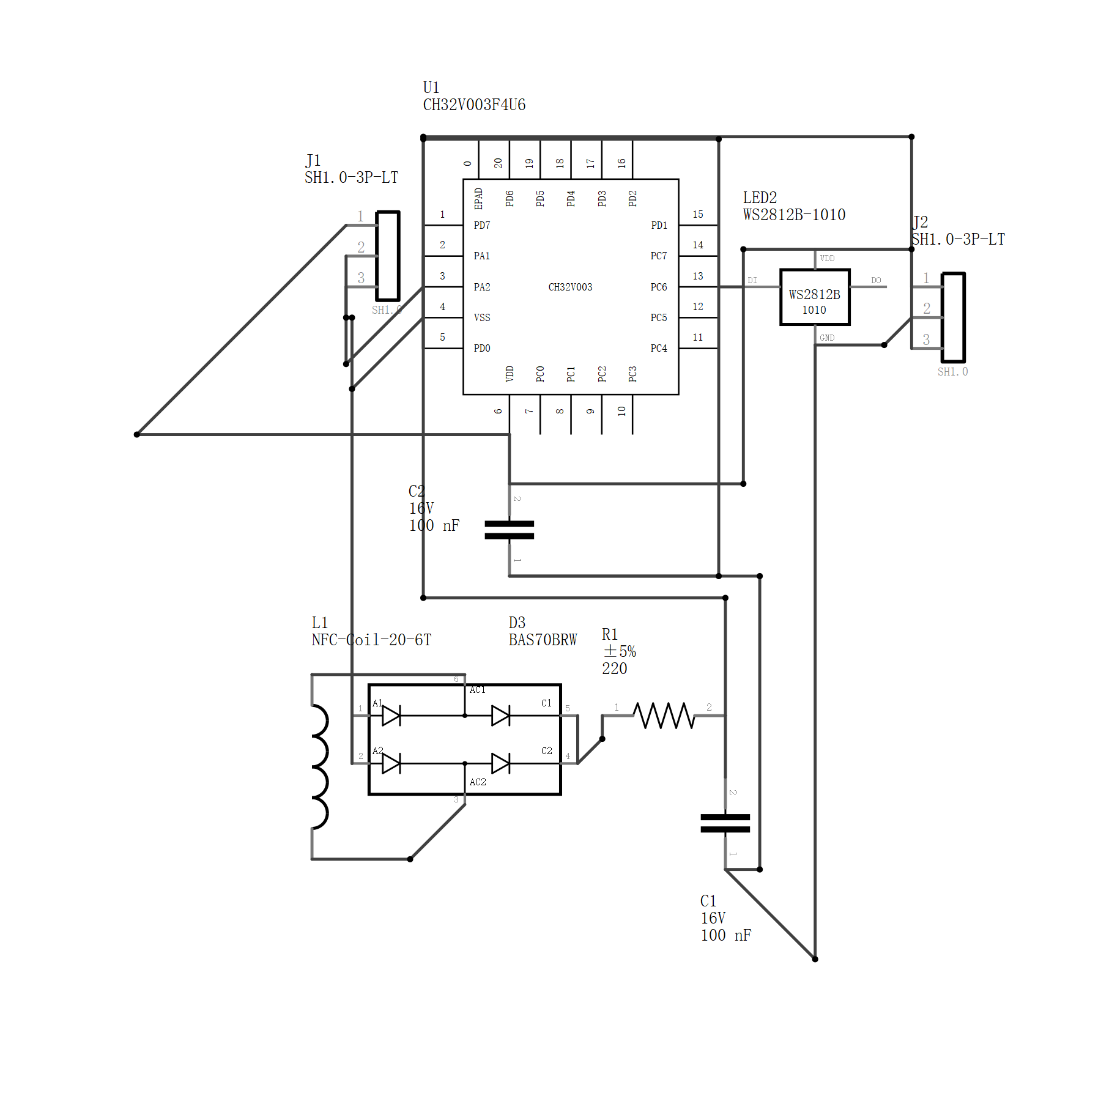
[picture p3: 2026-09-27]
hardware/pixel/pixel-schematic-v8_preview.png

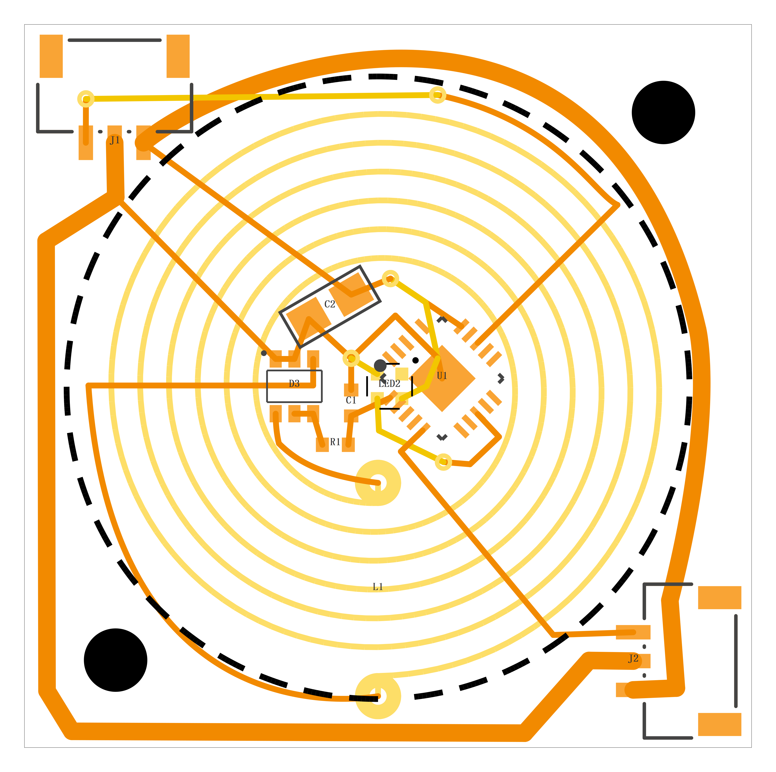
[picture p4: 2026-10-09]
hardware/pixel/pixel-pcb-v83_preview.png

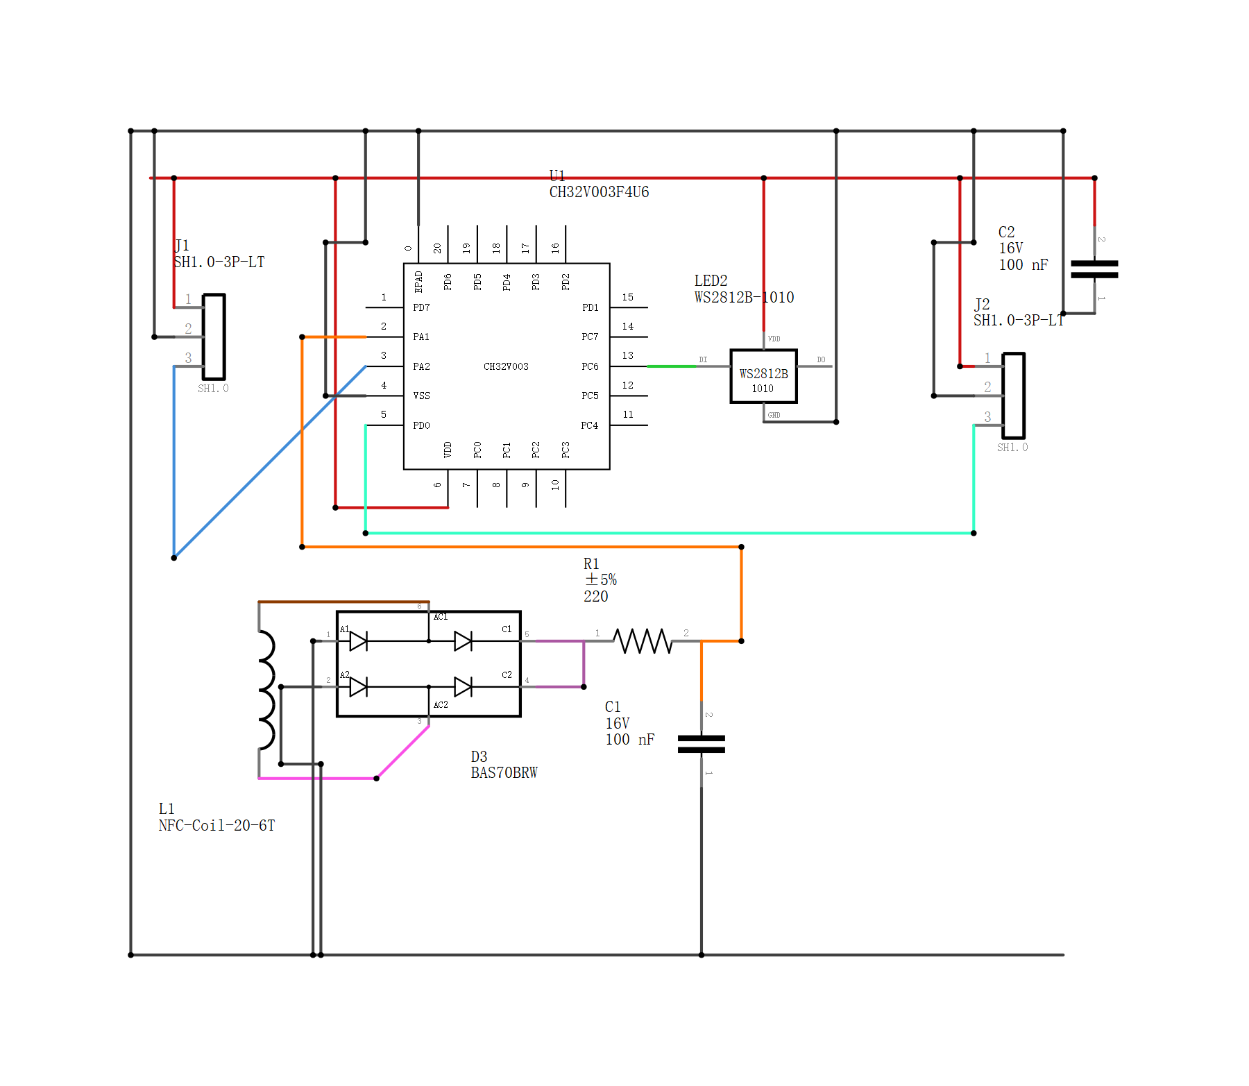
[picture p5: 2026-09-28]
hardware/pixel/pixel-schematic-v19_preview.png

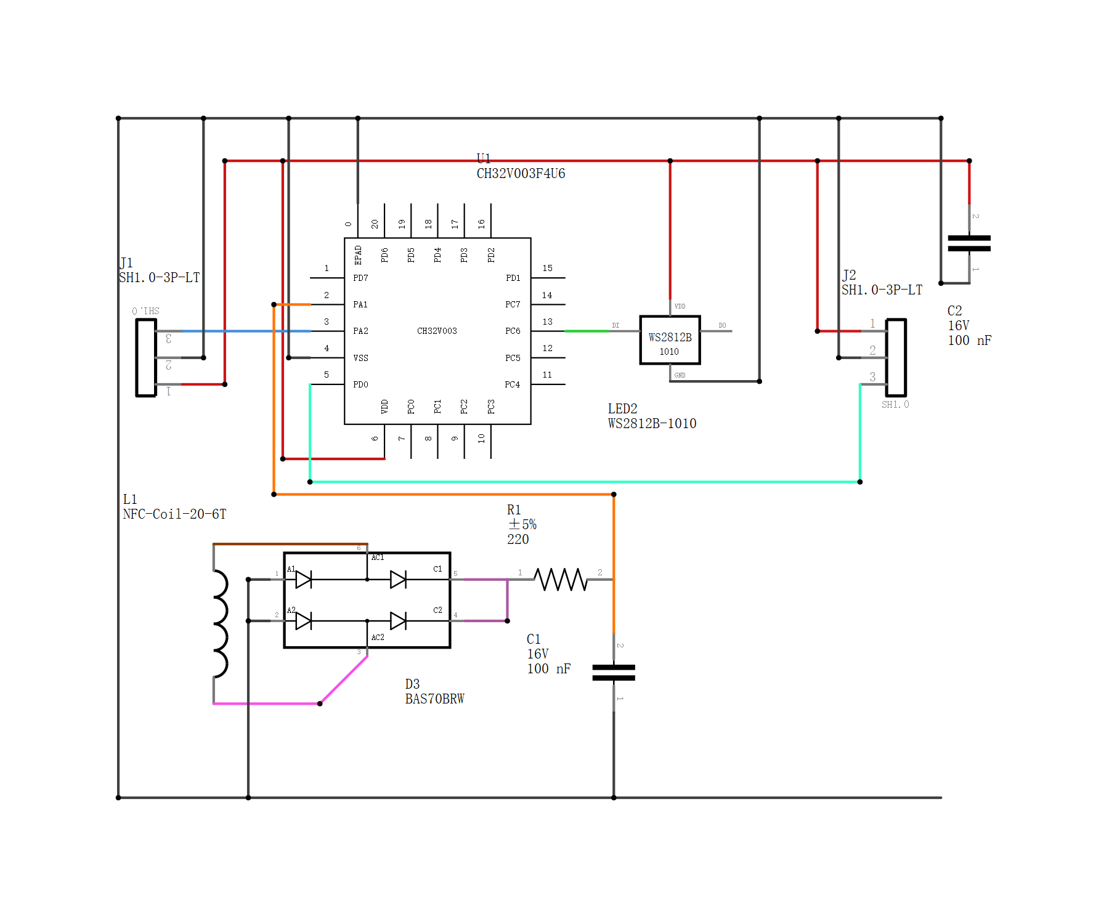
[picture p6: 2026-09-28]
hardware/pixel/pixel-schematic-v27_preview.png

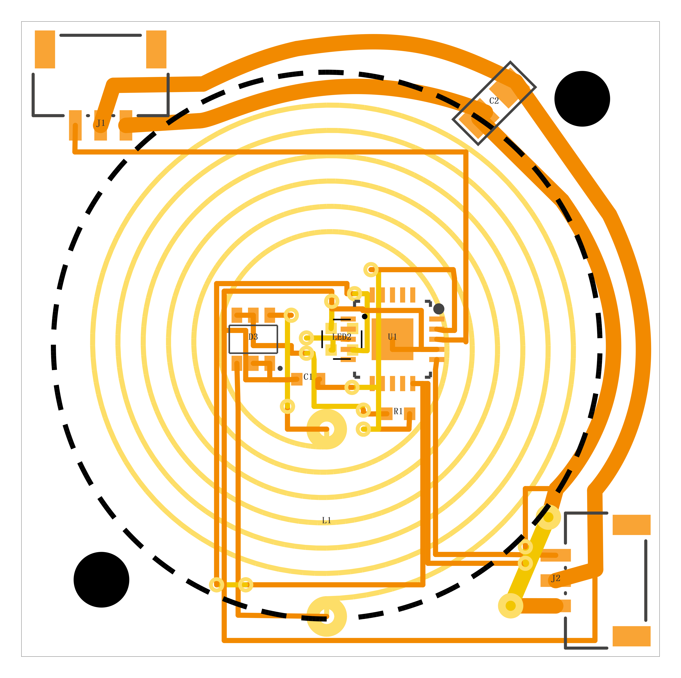
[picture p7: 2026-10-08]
hardware/pixel/pixel-pcb-v61_preview.png

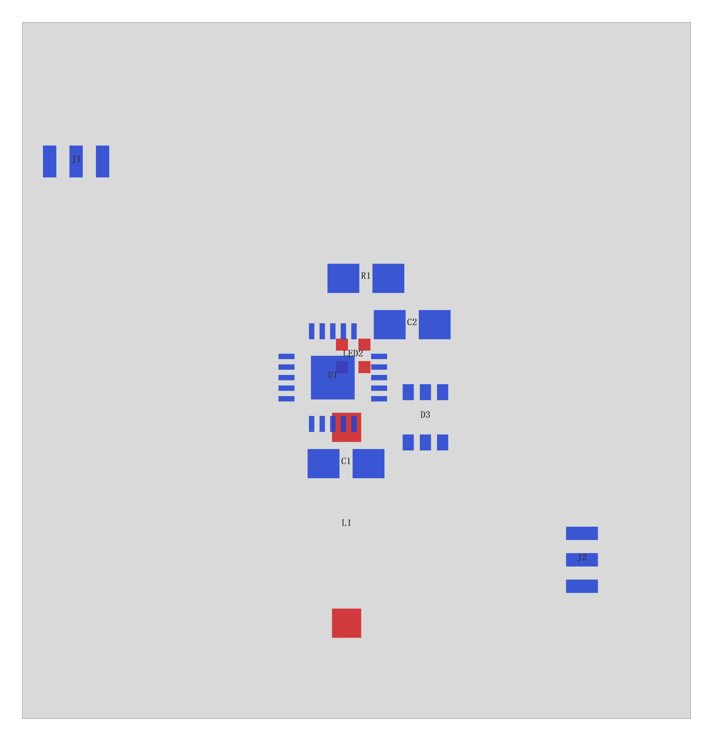
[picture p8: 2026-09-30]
hardware/pixel/pixel-pcb-v18_preview.png

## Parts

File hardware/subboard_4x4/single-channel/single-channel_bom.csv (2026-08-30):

序号 | 物料 | 规格/型号 | 采购网址 | 数量 | 类别 | 状态 | 备注
1 | NFC 线圈 | PCB 铜层 φ20mm / 6T / 线宽0.2mm |  | 1 | 随PCB | 🔴 必买 | 位号 L1；两线制 inner/outer；单线圈参考 φ20（4x4 阵列用 φ19）；由 PCB 铜层生成
2 | BAT54S | SOT-23 双肖特基 | https://detail.tmall.com/item.htm?id=944976706745&skuId=6016034334382 | 2 | 部分已有 | 🟡 待补 | 位号 D1/D2；2 颗组成四二极管全波桥（pin1→pin3→pin2 串联，勿简单并联）
3 | TS3A44159 | TSSOP-16 | https://item.taobao.com/item.htm?id=1004117394794 | 1 | 已购 | ✅ 已到 | 位号 U2；4 通道 SPDT 模拟开关；本子板仅用通道1（COM1/NO1/NC1），IN1-2/IN3-4 并联接 SEL
4 | CD74HC4067 | TSSOP-24 裸芯片 | https://item.taobao.com/item.htm?id=557524880337&skuId=5195814767787 | 1 | 已购 | 🔴 必买 | 位号 U3；16 通道模拟 MUX（I0~I15/SIG/EN/VCC/GND）；面包板原型可用现成开发板（4x4 BOM 第6项）代替
5 | 10kΩ 电阻 | 603 | https://item.taobao.com/item.htm?id=739043743825&skuId=5267873610238 | 1 | 已购 | 🔴 必买 | 位号 R1；整流输出串联电阻（RC 低通）
6 | 100nF 电容 | 603 | https://detail.tmall.com/item.htm?id=724280605862&skuId=5033785017978 | 1 | 已购 | 🔴 必买 | 位号 C1；RC 低通对地电容
7 | PCB 打样 | 单通道子板 2 层 1.6mm | https://item.taobao.com/item.htm?id=623693600774&skuId=5356662567663 | 1 | 待购 | 🔴 必买 | 正面线圈 L1 + 背面 SMD（D1/D2/R1/C1/U2/U3）+ J1 过孔焊盘（NetLabel-Pad PAD-2.0-H1.0 ×8：Ø2.0mm 焊盘 / Ø1.0mm 钻孔，2.54mm 间距，可插标准排针，已入板）；板面 43.46×23.81mm（fzz/gerber 实测）

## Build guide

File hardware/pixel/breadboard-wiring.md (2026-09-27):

# 面包板布线约定（pixel）

> ★★ **跨项目通用的规则正文在库仓 `docs/breadboard-routing-rules.md`** ✓（v0.1.0 ✓）——
> A 节 10 条可机器校验 ✓ / B 节口径与审美（**用户原话 + 推导** ✓）/ C 节 6 遍算法骨架 ✓ / D 节工具索引 ✓。
> 物理约束的最短清单也在库仓 `AGENTS.md` **§5b**（一孔一线 / 颜色含义 / 允许 45° 折线不许盖元件 ✓）。
> 本文只写**本项目**的约定 ✓。

## 0. ★ 面包板要的是**物理连接**，不是"同名即通"（2026-09-26 用户定 ✓）

- **netlabel / 网名是抽象连接** ✗ ⇒ **只适用于原理图** ✓（同名即同网 ✓ 是画原理图的简称手法 ✓）；
  **面包板上没有任何"抽象"** —— 两根线之间**必须**有导体（导线 ✓ 或同一条 bus 的铜片 ✓），
  否则就是没连 ✓。
- 推论（写生成器/写自检时必须遵守 ✓）：
  1. **不许**把"元件脚属于同一个网"当成"它们已经连上了" ✗ —— 同网只是**待办清单** ✓
     （告诉我"这几个脚最终要连成一片"✓），**不是**现成的连接 ✓；
  2. **一条 bus 上挂了两个不同网的脚 = 实物短接** ✗（那一列 5 个孔是**同一块铜片** ✓）
     ⇒ 这是**布局错误** ✓，必须挪脚 ✓；**不许**把它当"两网已合并"去补线 ✗。
     反例教训（本日 ✓）：`bus21` 上 `C1` 的 GND 脚(`21F`) 与 `R1` 的 RC 脚(`21G`) 同列 ⇒
     我把它当成"GND+RC 一片"去布线 ⇒ **RC 自己一根线都没有** ✗、还多出 `21H→22H`、
     `36H→38H` 两根"跨过 C1"的假线 ✗，而自检却报「10 网连通 ✓」✗✗；
  3. **自检要能区分"接通"与"被短接"** ✓：先查"没有 bus 跨两个网" ✓，再查连通 ✓
     —— 顺序反了就会像我一样报假通过 ✗。
- 机器守：`bb_route4.py` 先跑**布局短接硬闸门** ✓（有就报错 + **不写文件** ✗）。

## 0b. ★ 两条引线规则（2026-09-26 用户定 ✓）

- **① 引线不遮挡「接线了的孔」** ✗（用户原话 ✓）—— 孔上有东西（元件脚 ✓ 或跳线端点 ✓）时，
  引线不能把它的开口盖住 ✓；**我的取值：盖住开口面积 > 30% 就算遮挡** ✗（可调 ✓）。
  为什么取 30%（实测 ✓）：孔的开口半径 **1.496 单位**（板子 svg `r=1.197` 局部 ⇒ 直径 **0.845mm** ✓），
  跳线带宽 **2.00 单位**（22.2222 mil = 0.564mm ✓）⇒ 盖 30% ≈ 导线中心离孔心 **≥0.34mm** ✓；
  >50% ≈ 0.24mm（偏松 ✗）、>80% ≈ 只有正中心才算（太松 ✗）。
  机器守：生成器把它当**硬规矩** ✓（“严格路”直接否决 ✓；只有回退时才允许并重罚 ✓），
  自检直接报「遮挡接线孔 N 个 ⇒ 必须 0」✓。
- **② 引线尽量分散均匀、不过度拥挤** ✓（用户举例：某根该走右侧空地，却去挤中间 ✗）。
  做法：候选路算分时，每条段统计**附近（<6 单位 ≈ 1.7mm）有几根已有的线** ✓，
  按 `×(1 + 0.30×邻居数)` 罚 ✓ ⇒ 空地优先 ✓；自检报「拥挤度（每段平均近邻数）」✓ 做基线。
- **③ 一个脚只能「插孔」或「接一根引线」——二选一** ✓（2026-09-26 用户看图指出 ✓）：
  引线**不许**落在已插孔的脚上 ✗（要接**同一条 bus 里的空闲孔** ✓）；
  只有**没插孔**的焊盘（如 U1 的 EPAD 焊盘 ✓）才可以直接接线 ✓。
  例：EPAD 焊盘 → **GND 电源轨**（`pin31Z` ✓ —— 2026-09-26 用户定 ✓：
  「数据手册常说 EPAD 接 VSS，**只适用于 PCB**；面包板 / 原理图 / PCB 有各自的逻辑和美学」✓
  ⇒ 面包板上要看得见"特意接到地" ✓，接到本元件自己的 GND 脚所在的 bus 画出来像"芯片内部连着" ✗
  ⇒ **废** ✗；同理原理图上它接 **LED2 的 GND 脚** ✓，也不是 U1 自己的 pin4 ✗）。
  ★ “正下方那个孔”常常用不了 ✓：实测 `pin36G` 正好被 **U1 的板体遮住** ✗（被遮孔不能用 ✓），
  反正现在也不再用那一列了 ✓。
  机器守：回读自检报「wires on plugged pins N ⇒ 必须 0」✓。
- **④ 不许为了折线而绕远路** ✗（同日用户看到「绕了个大圈子」✓）：打分**以长度为主** ✓，
  折线不给加分 ✗ —— 折线只在能躲开元件/别的线/孔时出现 ✓。
- **⑤ ★ 引线尽可能少相交** ✓（2026-09-26 用户定 ✓，**优先于**④里的“长度为主”✓）：
  交叉的地方一看就乱、查线也容易看错 ✓ ⇒ **交叉数是头号指标** ✓（排在总长/段数前面 ✓）。
  做法（两道 ✓）：① 路的分里给交叉加权 ✓（贪婪阶段）；② 收尾跑**抽出重排** ✓
  —— 把一根抽出来、在**能看见其它所有线**的条件下重算它 ✓，只在指标变好时才采纳 ✓
  （贪婪布线看不见后面放的线 ✗，实测会多出交叉 ✗）。
  量两版差异 / 量任何一版：`py -3.13 bb_compare.py <A.fzz> [<B.fzz>]` ✓
  （手改草稿 `*_byHand.fzz` 已 gitignore ✓，但它可以直接拿来当 B 量 ✓）。
- **⑥ ★★ 美学原则：少相交 = 简单 = 美** ✓（2026-09-26 用户定 ✓，原话：
  「通过修改跳线位置和走向，让图的交叉点减少，从而看起来简单，人看着它觉得简单 =
  人看着它觉得舒服 = 美」✓）。用户给的两个实例（同日 ✓）：
  · 两根作用相同的黑线：右那根跟**元件、跳线有多个交集** ⇒ 不美 ✗；
    左那根**只与一根线相交** ⇒ 美 ✓；
  · 两根红线：斜的那根**与黑线相交两次** ⇒ 不美 ✗；折的那根**跟任何元件都没交集** ⇒ 美 ✓。
  ⇒ 三条判据：
  1. 判据是**交叉数** ✓ —— 同一根线被交叉两次 = **2** 次 ✓（不是“一次” ✗）；
  2. “交集”包括**与元件**相交 ✗（不只线↔线 ✓）；
  3. 降交叉的手段：换接孔 ✓ / 改走向 ✓（正交折线 ✓）——**正交（横平竖直 / 折线）
     比斜线好看** ✓（实测：用户点名“不美”的两根都是斜线 ✗，点名“美”的都是正交或折线 ✓）；
     但**折线不给加分** ✗（第 9 条：不许为了折线而绕远路 ✓）。
- **⑦ ★★ “交集”的准确定义 = 三条一起算**（2026-09-26 当天修正 ✓）：
  **交集 = X 形交叉 + T 形搭线（一方端点搭在对方段内 ✗）+ 从元件本体底下穿过** ——
  三类都算 1 次 ✓；**同一根线被交叉两次 = 2 次** ✓；
  两根线接**同一个孔**、或同一根线的两段在端点相接 ✓ **不算** ✗。
  ★ 我先后只数了 X ✗ ⇒ 目标函数与用户看到的不是一个东西 ✗ ⇒ 越优化越不像“人看着舒服” ✗；
  修正后同一张图 9 → 3 ✓（用户手改版 byHand = 4 ✓ ⇒ 生成版第一次**优于手改版** ✓）。
- **⑧ ★★ 判碰只有“一份实现”** ✓：`bb_compare.pair_kind(a,b,c,d)` ✓ ——
  **度量（看图的工具 ✓）与优化器（布线器 ✓）都调它**，不许各写一套 ✗。
  以前两套实现 + 两套包围盒混用 ✗ ⇒ 数字对不上、找不到原因 ✗（当天踩过 ✗）。
- **⑨ ★★ 不许“自证”** ✗（当天最大教训 ✓）：布线器的自检与布线器**共用**同一个
  几何定义/包围盒 ✗ ⇒ 它有错时两边一起错 ✓，自检永远通过 ✗。
  ⇒ 硬要求：**结论必须能被“另一个实现”或“人的眼睛”推翻** ✓ ——
  ① 数量结论用 `bb_compare.py`（独立于生成器 ✓）复核 ✓；
  ② 与用户手改版对量 ✓；③ 最终以**渲染/用户截图**为准 ✓。
  另外：自己新写的 svg 解析器（把 `path/@d` 的数字当点 ✗）曾把盒子算大 ✗ ⇒
  **新写一套几何读取前，先与已验证的老实现逐件对一遍** ✓（对不上就不能混用 ✗）。
- **⑩ ★ “改一处”要同时看“比的对象”是否同一条件**（当天第三个 bug ✓）：
  重排一根 EPAD 线时，**旧路由**忘了传“自己的元件豁免”✗、**候选路由**传了 ✓ ⇒
  每次比较都是 1→0 ✗、永远“有改进” ✓ ⇒ 同一根线被反复“重排”、全局一动不动 ✗
  （实测连着 8 轮重复 ✗）。教训：**比较的两边必须用同一组参数**✓。
- **⑪ ★★ 目标函数：代价 = 长度 + K × 交集** ✓（2026-09-26 用户定 ✓）
  ★ **K = 10 mm / 个交集** ✓ —— 这是**人为选定的经验值** ✓，**是一个可以随时调整的系数** ✓
  （不是从数据里推出来的物理量 ✗）。含义：为了少 1 个交叉，最多值得多绕 K 毫米 ✓；
  超过就不划算 ✗。调大 = 更看重“少交叉” ✓；调小 = 更看重“短而直” ✓；
  代码里就一行：`bb_route4.py` 的 `K_MM = 10.0` ✓（每次运行都在日志里打印 K ✓）。
  为什么需要它：以前是“交集优先、长度只当平手判据” ✗ ⇒ 为了省 1 个交叉肯绕 4 倍长度 ✗
  （实测 EPAD 被绕到 94mm ✗）。K 是**手感旋钮** ✓，最终以人看着舒服为准 ✓。
  ★ 两段式：前几轮**只按“少交叉”排** ✓、后几轮**按加权代价算账** ✓ ——
  若全程用加权 ⇒ 它会为了减长度到处加交叉 ✗（实测直接掉到 6∼9 个 ✗）。
- **⑫ ★★ 遮挡面积公式曾经写错（2026-09-26 用户追问后查出 ✓，最大的一个 ✗）**：
  `obscures()` 里算“导线带盖住孔的面积比”的圆弓公式，**平方根项符号写反了** ✗
  ⇒ 覆盖率只算真值的 **~1/5** ✗（实测：一根线正好穿过孔心，真值 **78%** ✓、旧公式报 **15%** ✗）。
  ⇒ “孔被别的引线盖住 >30% 就算违规 ✗”这条硬规则一直**形同虚设** ✗；
  布线器对遮挡的惩罚、`covered_by_wires()` 的拦截也一起失效 ✗。
  ⇒ 修完用独立脚本 `_scratch/audit_holes.py` 复核三版：
  v19 **1 处**（`pin34H` 被盖 78% ✗）、v8 **2 处**、v12 **0 处** ✓ ——
  可见之前那几版“看起来更优”有一部分是**几何闸门失效**换来的 ✗。
  ★ 教训：公式也必须有**数值真值校验** ✓（穿心 = $2(h\sqrt{R^2-h^2}+R^2\arcsin\frac{h}{R})/(\pi R^2)$ ✓），
  不能只看“代码能跑” ✗；且同一个公式**只能有一份实现** ✓（布线器里那份抄错了 ✗，现已改为直调
  `bb_compare.obscures` ✓）。
- **⑬ ★★ 留路：先布的“电源/地”走轨与板边，中间走廊留给信号线** ✓（2026-09-26 用户定 ✓，规则 a ✓）
  起因（实测 ✗）：按次序“先布电源/地”后，GND 把 `BR+` 唯一的那条中间走廊（row H，y=63 ✓）占掉了 ✗
  ⇒ 后布的信号线无处可走 ✗（`net BR+: 连不上` ✓）。
  ⇒ 规则：**留路不只是给元件、也是给后面的线** ✓ ——
  GND/5V（组 0/1 ✓）的代价里给“走中间”的那段加权 ✓（能走电源轨/板边就走 ✓）；
  信号线（组 2 ✓）不受此限 ✓（中间本来就是它们的地盘 ✓）。
- **⑭ ★★ 元件在面包板上的摆位（2026-09-26 用户定 ✓）**：
  · **单排针**的元件 ⇒ 可排在上半区（F..J ✓）**或**下半区（A..E ✓）；
  · **两排针**的元件 ⇒ **必须骑中缝** ✓：一排在上半区、另一排在下半区 ✓
    ⇒ **y 方向没有自由度** ✗（只能是“骑缝”那一档 ✓）。
  ★ 推论（实测 ✓）：两排针模块的 5 孔 bus 是**朝上**伸的 ✓
  （例如 U1 的焊盘在 F/E ✓，它的可用孔在 F..J 那一列 ✓）⇒ 摆到下半区时 bus 会伸进自己的板里 ✗
  ⇒ 布线器一开场就报“bus 没有空孔” ✗。
  ⇒ 做法：**先放 y 锁死的两排针模块**（又宽又没得选 ✓）、单排针再**填缝** ✓；
  骑电源轨的元件（去耦电容 ✓）必须落在**真轨孔列**上 ✓（轨孔是“4 个一组、隔一列空” ✓、列 3..61 ✓）。
- **⑮ ★★ 元件布置的四条硬约束（2026-09-26 实测 ✓）**：
  1. **孔必须真实存在** ✓ —— 电源轨只有 **50 列孔** ✗，不能按“10×63”算
     （否则算出 `pin2W` ✗ ⇒ 布线器 KeyError ✗）；
     判据源头：**板零件自己的 connector 集合** ✓（`hole_set` ✓）。
  2. **本体板不许越出板边** ✗（板边 = 孔阵外扩半个孔距 ✓）—— L1 曾被摆到 y=−40 ✗。
  3. **每条被用到的 bus 都要剩空孔** ✓，且必须**对称校验** ✓：不只看新放的零件 ✓，
     还要看**先前已放好零件**的全部脚 ✓ —— 新放的板子同样能把它们的 bus 盖满 ✗
     （实测：J2 的 D 行 bus 被后来的板子盖满 ✗ ⇒ 布线器开场报 `bus 没有空孔` ✗）。
  4. ★★ **“盖住”判定必须带容差** ✗（2026-09-26 根因 ✓）：本体板框是**过实例 transform**
     算出来的 ✓，带 1e-4 级浮点误差 ✗ ⇒ 用**精确边界**比会把**正好压在板边上**的那排孔
     判成“没盖住” ✗（实测：J2 板底边 `108.00009` vs 孔 `y=108.0` ✗ ⇒ 四条 bus 全判漏 ✗，
     而人看是“完全盖住” ✗）。⇒ 统一用 **`COVER_EPS = 1` 单位**（= 0.28mm ✓），
     与布线器（`bb0_route4` 的 `bx0-1 <= hx` ✓）**同一个口径** ✓。
  ★ 另有两条派生结论：**(a) “允许的 y 偏移”要算出来** ✓（由上面 4 条推 ✓），不能写死清单 ✗
  （写死 `(0, ±27)` ✗ ⇒ 20mm 高的 L1 报“放不下” ✗，它真正的合法偏移是 **+18** ✗ 不在清单里 ✗）；
  **(b) 放不下的根因要能点名** ✓（布线器报 `bus 没有空孔` 时**指名**是哪条 bus、上面插着谁、
  被哪块板子盖住 ✗ —— 不点名就只能靠猜 ✗）。
- **⑯ ★★ 电源/地怎么布才算对（2026-09-26 实测 ✓）**：
  · **对侧那条电源轨也算本网资源** ✓（GND ↔ Z/X ✓、5V ↔ Y/W ✓，同一网才可以 ✓，交叉就是短路 ✗）：
    ★ 动机（实测 ✗）：地网的锚点只有一条轨（EPAD 接上去那条 ✓ = **Z** ✓），
    而**骑中缝的模块**（D3：板盖住 G..D 行 ✓）**下半区的脚**只能从下方出线 ✗
    ⇒ 被迫翻过自己的板子去够上轨 ✗ ⇒ 实测绕出 **147mm** ✗ 而且最后還连不上 ✗。
    把 X 的一个空孔加进地网后，**两条轨之间的干线由布线器自己拉** ✓（实测 `pin59Z→pin59X`
    **45.7mm** ✓，落在板边 ✓ = 规则 a ✓）。
  · **电源/地按“星形”接轨** ✓（每条非轨 bus 就近接一条轨 ✓），**不要**让它们自由配对 ✗：
    实测自由配对会把 D3 的 E-bus 直接连到很远的 J2 bus ✗（**147.3mm** ✗），
    而那根线又横着压住了 D3 自己 bus 的孔 ✗ ⇒ 最后 `pin3E` 连不上 ✗。
    改成星形后实测：GND = `8.0 / 8.0 / 10.2 / 7.6 / 25.4 / 10.5 / 10.2 / 40.6 mm` ✓、
    5V = `8.0 / 8.0 / 27.9 / 8.0 / 23.4 mm` ✓ —— **全都是“轨→脚”的短竖线** ✓（跟用户手画那两根一个风格 ✓）。
- **⑰ ★★ 「留路」要按 bus 判、不要按孔判（2026-09-26 实测 ✓）**：
  · 规则 ⑩ 的正确形式：**一条 bus 里 5 个孔 ✓，只要还能剩一个可用孔 ✓**，
    后面那个网就仍能用它 ✓ ⇒ 才允许压 ✓。按“碰到哪个孔就不行”❌ 会把
    **整条 J 行走廊**全禁掉 ❌ ⇒ 实测 `DATA_OUT`（U1 的脚 → J1 的脚）就是这样被
    卡死的 ❌（1809 个候选全废 ✗）。
  · 另外补了两种**走法形状**（实测缺的 ✓）：
    ① **绕“墙”的三折**：把中间那条线放在**两个元件框之间的空当**（框外 ±1.5 孔距 ✓）
      —— 实测 `COIL_A` 需要它 ✓（L1 的脚只能从 F 行出 ✓、D3 的脚只能从 J 行出 ✓，
      而 F 行横着别人要用的孔 ✓）；
    ② **绕一个框的“U 形”（4 个弯）**：`当 `J1` 这种上半区的墙 ✓，需要“从框左边下去 +
      从框右边上来”✗（三折表达不了 ✓）。
- **⑲ ★★ 删旧导线时，必须同时删“孔 → 那根线”的记录** ✗（2026-09-26 用户截图实测 ✓）：
  · 症状（用户看到的 ✓）：在 Fritzing 里**悬停一个孔 ⇒ 一大片孔都亮** ✗ ——
    看起来像“很多孔被错误地连在一起” ✗。用户原话：「似乎有错误的网，导致很多点是通的」✓。
  · 根因：布线器删了旧 `Wire` 实例 ✓，但**板子连接表**里 “孔 → 那根线” 的
    `<connect modelIndex=…>` 还留着 ✗ ⇒ 指向**不存在的实例** ✗ ⇒ Fritzing 就把它当成
    “接在一根看不见的线上” ✗。
  · 实测数字（独立审计 `_scratch/audit_connects.py` ✓）：我以前的版本 **12 处悬空引用** ✗、
    用户手画版 **0 处** ✓ ⇒ 交付前必须清 ✓。
  · 修法：① 写文件前**清空**板子连接表（实测清了 48 条 ✓）；
    ② 收尾再扫一遍，删掉**任何**指向不存在实例的 `<connect>`（实测又清 8 条 ✓，
    就是那两根被删的旧导线 `90012830` / `90012839` 留下的 ✓）；
    ③ 用 `audit_connects.py` 复核 ⇒ ① 悬空 0 ✓ ② 一个孔接多根线 0 ✓ ③ 一个脚接多根线 0 ✓。
  · ★ 对布线/长度**无影响** ✓：布线器只读（板子的 `<bus>` ✓、零件的脚位 `<connects>` ✓、`NETS` 网表 ✓），
    **从不读**板子连接表 ✗ ⇒ 几何与指标不受影响 ✓（但文件必须干净 ✓）。
  **`hardware/pixel/pixel-breadboardNN_preview.png`**（`_scratch/render_bb.py <fzz> <png> ✓`）
  并用 `Start-Process` **打开** ✓。画的时候**不自创几何** ✓：零件摆放用 `part_box.py`
  那套矩阵/缩放 ✓（与“本体包围盒”同一个实现 ✓）、导线用 `wireExtras/@color` + 2 单位宽 ✓；
  图例里的 `TXT…` 文字件不画正文 ✓（免得挡住视图 ✓）。
- **⑱ ★★ 每次做完都要给图**（2026-09-26 用户定 ✓，原话：「我有个困扰，只是听你说，
  看不到你做了什么」）：结论不要只用文字报 ✓ —— 要产出

- **每个 fzz 自带自己的图例** ✓ —— 图例是**视图里的一件东西** ✓，跟着文件走 ✓，不依赖外部文件 ✓；
- 图例画在面包板的**空白区**（右/下侧 ✓），每行 = **该网络颜色的短线** + **网络名** ✓；
- 颜色含义要**一眼可读** ✓（见下表 ✓）；图例里出现的颜色必须与跳线颜色**逐一对上** ✓。

## 2. 颜色约定

| 网络 | 颜色 | 色值 | 说明 |
|---|---|---|---|
| `GND` | **黑** | `#404040` | 接地 ✓（官方的表里 black 的 wire 值就是 `#404040` ✓，**不是** `#000000` ✗） |
| `5V` | **红** | `#cc1414` | 电源正 ✓ |
| `DATA_IN` | 蓝 | `#418dd9` | 上游数据（进） |
| `DATA_OUT` | 青 | `#33ffc5` | 下游数据（出） |
| `LED_DIN` | 绿 | `#25cc35` | 像素数据 |
| `RC` | 橙 | `#ef6100` | 阻容节点 |
| `BR+` | 紫 | `#ab58a2` | 倍压节点 |
| `COIL_A` | 棕 | `#8c3b00` | 线圈一端 |
| `COIL_B` | 粉 | `#fa50e6` | 线圈另一端 |

★★ **只能用 Fritzing 官方配色表里的值** ✓（2026-09-26 定位到根 ✓）。
**权威来源**（可逐行核 ✓）：
```
F:\build-fritzing\fritzing-app\resources\ratsnestcolors.xml
  <view name="breadboardView"> 下每个 <color name="…" wire="#……" /> ✓
  ＝ blue #418dd9 | red #cc1414 | black #404040 | yellow #fff800 | green #25cc35
    grey #999999 | white #ffffff | orange #ef6100 | ochre #a37911 | cyan #33ffc5
    purple #ab58a2 | brown #8c3b00 | pink #fa50e6
```
（代码依据 ✓：`items/wire.cpp` 用 `RatsnestColors::wireColor(viewID, colorName)` ✓；
表本身在 `utils/ratsnestcolors.cpp` 读上面那份 XML ✓。）

✗ **失败模式（用户截图实证 ✓）**：写了**表里没有的 hex**（`#ff0000` / `#000000` / `#0055ff` /
`#00a0a0` / `#00a000` / `#d08000` / `#8000c0` / `#c00080` / `#8b4513` / `#f28a00` / `#f2c600` ✗）
⇒ **画出来对**（渲染只认 `wireExtras/@color` ✓）、但**指示栏的「颜色」下拉认不出** ✗
⇒ 回退成**列表第一项（蓝）** ✗ —— 实测：选一根黑线，面板显示「蓝」✗。
⇒ 所以改颜色时**先去上表里挑一个** ✓，不要自创 ✗。
机器守：`_scratch/file_sanity.py <fzz>` 直接报「非标准色的导线 N 个 ⇒ 必须 0」✓。

（新增网络时**在此表加一行** ✓，并同步图例 ✓。）

## 2b. ★ 电源轨的**行约定**：第一行 = GND(蓝) / 第二行 = 5V(红)（2026-09-26 用户定 ✓）

- **红线 = 正极、蓝线 = 负极** ✓ —— 这是面包板的通行读法 ✓，而**板子自己的 svg 就是这么印的** ✓：
  实测（`breadboard2.svg` ✓）上行组 **第一行 Z 上方** 那条线是 `#0000FF`（蓝 ✓）、
  **第二行 Y 下方** 是 `#FF0000`（红 ✓）；下行组同理（X 上方蓝 ✓、W 下方红 ✓）⇒
  **第一行(Z/X) = 负极 = GND ✓、第二行(Y/W) = 正极 = 5V ✓**（用户原话：「5V 应该接第二行，
  GND 接第一行」✓）。
- 机器守：`fix_breadboard_layout.py` 里已把 `C2` 两只脚对调到「5V→`30Y` ✓ / GND→`29Z` ✓」✓；
  以后**凡是能落在轨上的电源脚，都按这条落** ✓（落在轨上 = 同一条长 bus ⇒ **一根线都不用** ✓）。
- 例（本板 ✓）：`5V` 的轨脚 = `pin30Y`（第二行 ✓）、`GND` 的轨脚 = `pin29Z`（第一行 ✓）。

## 3. 图例的实现方式（★ 已被 §5 取代 ✓ 2026-09-26，留档 ✓）

Fritzing 的 sketch **没有"自由文字"图元** ✗ —— 视图里的文字只能来自**元件** ✓，所以图例需要一件
**能在面包板视图里显示文字的小件** ✓。两条候选（**定了才动手** ✓）：

| 方案 | 做法 | 代价 |
|---|---|---|
| A | 给库里的 `NetLabel-Pad` **加一个面包板视图** ✓ | 改一个已有元件 ✓（要用户点头 ✓） |
| B | 新做一件 `Legend` / `LegendText`（只有面包板视图 ✓、无连接器 ✓ 或连接器不接 ✓） | 新增元件 ✓（按 §2 芯片流程只做面包板视图 ✓） |

## 4. 跳线规则（生成器要满足 ✓）

1. **一孔一线** ✓：`元件脚已插的孔`一律**不接跳线** ✗ ⇒ 跳线接在**同一条 bus 内的空闲孔** ✓，
   且**每个空闲孔最多用一次** ✓（生成时报「占用孔冲突数」✓，必须 **0** ✓）；
2. **5V / GND 走电源轨** ✓（用户 2026-09-26 定 ✓）；轨上取孔也遵守第 1 条 ✓；
3. 倾斜/折线允许 ✓，但**不许盖在元件本体上** ✗；
4. 生成后自检：① 每孔占用 ≤1 ✓ ② 含 bus 的**脚级**连通性 = 10 网全通 ✓ ③ 线端落在孔心（标定残差 ✓）。

## 5. 图例的实现（已定稿 ✓ 2026-09-26）

**用 Fritzing 自带的 `BreadboardLogoText`** ✓（`moduleIdRef="BreadboardLogoTextModuleID"` ✓，
`path=":/resources/parts/core/breadboardlogotext.fzp"` ✓）—— **不新造元件** ✓、不用你装库 ✓。

- 它**没有连接器** ✓ ⇒ 放进视图**不会给网表添节点** ✓；只有 `breadboardView` ✓；
- 色条是**一根没有任何 `<connectors>` 的面包板导线** ✓（纯装饰 ✓，电气上不存在 ✓）；
- 生成器：`bb_legend3.py` ✓（**幂等** ✓：每次先把旧图例清掉 ✓ ——
  判据 = `BreadboardLogoText` 件 + "面包板导线里没有 connectors 的装饰件" ✓）；
- 参数（可用命令行覆盖 ✓）：起点 `(590, 12)` ✓ | 标题→首行 `22` ✓ | 行距 `12` ✓ |
  文字微调 `-3` ✓ | 色条长 `9` ✓ | 间隙 `3` ✓。

### ★ 三条实测出来的坑（别再猜 ✓）

| 坑 | 事实 |
|---|---|
| **尺寸规律** | 正文 **1.7586 mm/字符** ✓、高 **2.28615 mm** ✓；标题「图例：」**2.54 mm/全角字** ✓（= 7.62 ✓）、高 **3.302 mm** ✓ —— 字号**由盒子(mm)大小决定** ✓，不是 svg 的 `font-size` ✓ |
| **比例必须一致** ✗ | `viewBox` 宽 : 13 **必须等于** 盒子 mm 宽 : 高 ✓ —— 不一致时 svg 会"**按最小比例缩放并居中**" ✗ ⇒ 字号/基线跑偏 ✓（标题错了两轮就是这个 ✓） |
| **左对齐** | 盒子按**各自文字宽度**给 ✓ + 盒内 `text-anchor="start" x="1"` ✓ + 各行共用同一左缘 ✓ ⇒ 就齐了 ✓（"加半宽补偿"那招没用 ✗ —— 锚点约定不是我以为的那样 ✓） |

## 6. ★★ 预览图（`render_bb.py`）：**先看再发**，且必须自报尺寸（2026-09-27 用户报 ✗）

用户原话：「你的 preview.png **没有一个是正确的**，你为啥有信心给俺看呢？」✗ —— 因为我**从没看过自己发的图** ✗、
只看到"渲染没报错"就发 ✗ ⇒ 正踩用户的规矩「以你打开的实样为准，别凭自己的渲染自嗨」✗。

| 坑 | 事实（都量过 ✓，不是猜 ✓） |
|---|---|
| **画布尺寸声明** ✗ | `<svg width="1800" height="615">` **没单位** ⇒ Inkscape/浏览器按 **CSS px** 解释 ⇒ 文档 **476mm** ✗ 而内容只有 **175.8mm** ✗。⇒ 一律**显式写 mm** ✓（1 单位 = 25.4/90 mm ✓） |
| **面包板 svg 的 dpi** ✗ | `breadboard2.svg` 是 Illustrator 导出（`id="Layer_1"`、`x="0px"`、`width="468.238px"`，**且有 viewBox** ✓）⇒ 用"有 viewBox 就 90dpi"会算成 **132.1mm** ✗，而它必须是 **165.2mm** ✓（**72dpi** ✓）。核对锚点：`468.238 × 25.4/72 = 165.2mm` ✓ ≈ 孔阵 `576 单位 = 162.6mm` ✓（差 9 单位 = 一列留边 ✓） |
| 症状 | 板子被画小 20% ✗ ⇒ **底部 X/W 两条轨掉到板子外面** ✗ ⇒ 看着像"导线悬在板外" ✗（放大看局部反而正常 ✓ —— 零件与导线之间自洽 ✓，错的只有板子 ✗） |
| **零件 svg 的 viewBox 原点** ✗ | 常不是 (0,0)（本库件会写 `viewBox="7 7 18 18"` ✓）⇒ 缩放时**必须补** `translate(-minX,-minY)` ✓，否则整件平移错位 ✗ |

**规矩（记死 ✓）**：
1. **图我看过才发** ✓（`view_image` 就一次的事 ✗ —— 之前偏偏没做 ✗）；
2. 渲染器**自报口径** ✓：每件报「用了哪个 svg ✓ / 算出 k ✓ / 物理尺寸 mm ✓」，板子报「mm ↔ 孔阵 mm」✓
   ⇒ **物理尺寸对不上就是错** ✓（不许"没报错就算对" ✗）；
3. 与用户打开的实样冲突时，**以用户的实样为准** ✓，改工具 ✗ 不改结论。
4. 配套诊断：`wire_dump.py <fzz>`（逐根导线打出真实 `<geometry>` ✓）——
   它钉死过一条口径 ✓：**Fritzing 把折线存成多个导线实例** ✓，每个实例只有一段 ✓、
   `x2/y2` 是**相对 (x,y)** 的向量 ✓（例：`pin12A`(108,144)+`y2=27` ⇒ 正好落在 `pin12X`(108,171) ✓）。

---

## 7. ★ 斜线预算（2026-09-27 用户定 ✓）

- **斜线不是"越少越好"、也不是"越多越好"** ✓ —— 用户原话 ✗：
  「v98 的缺点是**斜线太多了**，不够漂亮；v99 的缺点是**一条斜线都没有**，不够自然」✗；
  「还是希望有 **3 条以内**的斜线，而且斜线最好**跟我的斜线一样**」✓。
  ⇒ 实测定稿 **4 条** ✓（与用户手版同数 ✓；其中 `DATA_OUT (243,63)->(270,108) 14.8mm`
  **与他画的那条逐字相同** ✓）。
- **系数 `DIAG_PEN = 1.25`** ✓（`bb_route4.py` 里一行 ✓，可用 `PP_DIAG_PEN` 临时改 ✓）。
  ★ 它**是算出来的** ✗ 不是试出来的 ✓：拿用户手版那根 5V 比 —— 斜着走 `13.7P + 27.9` ✓、
  正交走 `45.7` ✓ ⇒ 斜线胜出要 `P < 1.30` ✓ ⇒ 取 **1.25** ✓。
- **形状代价按"逐段"算** ✓（`shape_factor` ✓）：等效正交长
  $= \sum_i \ell_i \times (\text{该段是斜线} ? 1.25 : 1.0)$ ✓。
  ★ **不许**用"点数 > 2 就免罚"的老口径 ✗ —— 那样"斜线 + 一小段直"能**绕过**罚 ✗
  （实测斜线 **1 → 9 条** ✗，见 `router-review.md` §5.2 ✓）。
- **查斜线用 `tools/bb_diag_list.py`** ✓（**逐条点名** ✓，别只看一个数字 ✗）；
  并且要拿 `*_byHand.fzz` **逐条对照** ✓（"为什么没像我这样画"只能这样回答 ✓）。

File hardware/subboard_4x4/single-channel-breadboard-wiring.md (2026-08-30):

# 传感器子板·面包板接线说明（SYB-118，无 MCU）

> 对应 `single-channel.fzz` 的**面包板视图**。面包板上是**子板元件**（线圈/整流/RC/TS3A/MUX）+ **J1 接口（8 路信号）**；**没有 MCU**。
> ESP32 在独立**控制板**（开发板或待建板，带 USB 供电/调试），经 **J1 引线**接到子板。子板原理图接线见 [`single-channel-schematic-wiring.md`](single-channel-schematic-wiring.md)。

## 布局总览

用 **2 块 SYB-118 面包板**（下称 BB2、BB3），子板元件分布：

```
BB2（左板）                          BB3（右板）
┌──────────────────────────┐        ┌──────────────────────────┐
│ L1 线圈 → A 列             │        │ U2 TS3A44159 → C/F 列     │
│ D1/D2 整流桥 → E/F 列       │        │ （pin37C~44C, 37F~44F）    │
│ R1/C1 RC 低通 → F/H/I 列    │        │                          │
│ MUX（U3）→ D/H 列          │        │                          │
│ （pin43H~58H, 47D~54D）    │        │                          │
│ J1 接口（8 路）→ 空白区   │        │                          │
└──────────────────────────┘        └──────────────────────────┘
```

> 插座记法：`pin<行号><列字母>`，如 `pin19J` = 第 19 行 J 列孔。列 A~E 一组、F~J 一组，同组相邻 5 孔内部连通。
> ⚠️ 原开发板占用的插座（BB2 的 J 列、BB3 的 D 列）现为空，J1 的 8 路信号可用跳线从元件引出到开发板。

## J1 · 接口引出（8 路信号 → 网络标签）

> 原理图上接口用 8 个网络标签标注（`ESP32-S3-DevKitC-1 IO1/IO2/3V3/IO4/IO5/IO6/IO7/GND`）；面包板实物用跳线把各信号引到开发板。

> 脚序为**实际物理顺序**（PnP 实测，上→下）：`3V3, SIG, SEL, S0, S1, S2, S3, GND`；3V3 与 GND 分居两端。

| 针（上→下） | 信号 | 去向（子板） |
|---|---|---|
| 1（顶） | `3V3`（VCC） | MUX `VCC`、TS3A `VCC` |
| 2 | `IO1`（SIG） | MUX `SIG` |
| 3 | `IO2`（SEL） | TS3A `IN1-2`/`IN3-4` |
| 4 | `IO4`（S0） | MUX `S0` |
| 5 | `IO5`（S1） | MUX `S1` |
| 6 | `IO6`（S2） | MUX `S2` |
| 7 | `IO7`（S3） | MUX `S3` |
| 8（底） | `GND` | 全子板地 |

## 元件插孔表（每个脚→面包板插座）

### U3 · CD74HC4067（MUX，BB2）

| 端子 | 插座 | 端子 | 插座 |
|---|---|---|---|
| C15 | `pin43H` | C14 | `pin44H` |
| C13 | `pin45H` | C12 | `pin46H` |
| C11 | `pin47H` | **SIG** | `pin47D` |
| C10 | `pin48H` | **S3** | `pin48D` |
| C9 | `pin49H` | **S2** | `pin49D` |
| C8 | `pin50H` | **S1** | `pin50D` |
| C7 | `pin51H` | **S0** | `pin51D` |
| C6 | `pin52H` | **EN** | `pin52D` |
| C5 | `pin53H` | **VCC** | `pin53D` |
| C4 | `pin54H` | **GND** | `pin54D` |
| C3 | `pin55H` | | |
| C2 | `pin56H` | | |
| C1 | `pin57H` | | |
| **C0** | `pin58H` | | |

### U2 · TS3A44159（BB3）

| 端子 | 插座 | 端子 | 插座 |
|---|---|---|---|
| **IN1-2** | `pin37C` | NO2 | `pin37F` |
| **NC1** | `pin38C` | COM2 | `pin38F` |
| **COM1** | `pin39C` | NC2 | `pin39F` |
| **NO1** | `pin40C` | **GND** | `pin40F` |
| **VCC** | `pin41C` | NO3 | `pin41F` |
| NC4 | `pin42C` | COM3 | `pin42F` |
| COM4 | `pin43C` | NC3 | `pin43F` |
| NO4 | `pin44C` | **IN3-4** | `pin44F` |

### L1 · NFC 线圈 / D1·D2 整流桥 / R1·C1 RC 低通（BB2）

| 元件 | 脚 | 插座 |
|---|---|---|
| L1 | inner | `pin28A` |
| L1 | outer | `pin35A` |
| D1 | A1 | `pin27F` |
| D1 | node | `pin28E` |
| D1 | K2 | `pin28F` |
| D2 | A1 | `pin34F` |
| D2 | node | `pin35E` |
| D2 | K2 | `pin35F` |
| R1 | 端1 | `pin28I` |
| R1 | 端2 | `pin31F` |
| C1 | 端1 | `pin31H` |
| C1 | 端2 | `pin34H` |

## 信号跳线表

元件插入后，按以下网络用跳线把对应插座连起来（同网即同电气节点）：

| 网络 | 插座（→ 脚） | 说明 |
|---|---|---|
| 通道1输出 | `BB2 pin58H`(MUX C0) ↔ `BB3 pin40C`(TS3A NO1) | 选通通道 1 → MUX |
| BR+ | `BB2 pin28F`(D1 K2) ↔ `BB2 pin28I`(R1 端1) | 整流输出 → RC 串联电阻 |
| node_RC | `BB2 pin31F`(R1 端2) ↔ `BB2 pin31H`(C1 端1) | RC 节点（→ TS3A COM1） |
| 线圈→桥 | L1 inner `pin28A` ↔ 桥A node `pin28E`；L1 outer `pin35A` ↔ 桥B node `pin35E` | 线圈两端接整流桥中点 |
| BR-（GND） | D1 A1 `pin27F`、D2 A1 `pin34F` → GND 电源轨 | 桥负极接地 |
| node_RC→TS3A | `BB2 pin31H`(C1 端1) ↔ `BB3 pin39C`(TS3A COM1) | 滤波输出进开关 |
| TS3A NC1→GND | `BB3 pin38C`(NC1) → GND | 背景采样 |
| TS3A SEL→J1 | `BB3 pin37C`(IN1-2)、`pin44F`(IN3-4) ↔ J1 pin3 `SEL` | 选通控制（两脚并联） |
| MUX SIG→J1 | `BB2 pin47D`(SIG) ↔ J1 pin2 `SIG` | 16 路选通输出 → 控制板 ADC |
| MUX 地址→J1 | S0 `pin51D`↔J1 pin4、S1 `pin50D`↔J1 pin5、S2 `pin49D`↔J1 pin6、S3 `pin48D`↔J1 pin7 | 通道选择，S0=最低位 |
| MUX 电源 | VCC `pin53D`→J1 pin1 `3V3`、GND `pin54D`→J1 pin8 `GND`、EN `pin52D`→GND | EN 子板接地常开 |
| C1 端2→GND | `BB2 pin34H`(C1 端2) → GND | 低通滤波对地 |
| 电源轨 | J1 pin1 `3V3` → 3V3 轨；J1 pin8 `GND` → GND 轨 | 由控制板经 J1 供电 |

> ⚠️ 装配前用万用表二极管档确认 BAT54S 实物方向（pin1→pin3→pin2）；整流输出须 < 3.3 V（ESP32 ADC 量程）。
> ⚠️ 面包板视图 = 子板原型（无 MCU）。ESP32 在独立控制板，经 J1 引线供电/读信号；控制板原理图待建。

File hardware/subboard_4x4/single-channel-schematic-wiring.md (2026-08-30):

# 传感器子板·原理图接线说明（1×8 接口，无 MCU）

> 对应 `single-channel.fzz` 的**原理图/PCB 视图**。子板上**没有 MCU**：8 路接口信号用 **8 个网络标签**（Fritzing 核心 `Net Label`，标注 `ESP32-S3-DevKitC-1 IO1/IO2/3V3/IO4/IO5/IO6/IO7/GND`）标出对应 ESP32 开发板/控制板引脚，接独立的 **ESP32 控制板**（含 WROOM-1 + USB Type-C + CH340 + 3.3V LDO + EN/BOOT，待建）。
> 面包板原型接线见 [`single-channel-breadboard-wiring.md`](single-channel-breadboard-wiring.md)。

## 架构（方案 C）

```text
传感器子板                          ESP32 控制板（独立，待建）
 线圈→整流→RC→TS3A→MUX                 WROOM-1 + USB-C + CH340 + LDO
        │                                  │
        └─ 8×网络标签(ESP32 引脚标注) ──引线── 对应接口
          VCC GND SIG S0 S1 S2 S3 SEL       IO1 IO2 IO4-7 ...
```

## 信号链

```text
两线线圈
  -> 2 × BAT54S 全波桥（BR+ / BR-）
  -> R=10 kΩ 串联、C=100 nF 对地低通
  -> TS3A44159 COM（NO=通道输出，NC=GND 背景采样）
  -> CD74HC4067（MUX，C0~C15）
  -> J1.SIG -> ESP32 控制板 ADC1（GPIO1/IO1）
```

## 元件清单（库内元件）

| 编号 | 元件 | 连接器 |
|---|---|---|
| U整流A/B | `BAT54S.fzpz` | `A1`(1) / `node`(3) / `K2`(2) |
| **U3**（MUX） | `CD74HC4067.fzpz` | `C0~C15`(connector0..15) / `SIG`(16) / `S0~S3`(17..20) / `EN`(21) / `VCC`(22) / `GND`(23) |
| **U2** | `TS3A44159PWR.fzpz` | `NO1`(connector12)/`COM1`(13)/`NC1`(14)、`IN1-2`(15)、`IN3-4`(7)、`VCC`(11)、`GND`(3)（NO2-4/COM2-4/NC2-4 同序） |
| **J1**（接口） | 自建 `NetLabel-Pad` ×8 | 8 个网络标签，PCB 上生成 8 个实体过孔焊盘（PAD-2.0-H1.0：Ø2.0mm 焊盘 / Ø1.0mm 钻孔，2.54mm 间距），标注信号对应 ESP32 开发板/控制板引脚（`IO1/IO2/3V3/IO4/IO5/IO6/IO7/GND`） |
| L1 | `NFC-Coil.fzpz` | `inner` / `outer` |
| R1 / C1 | 核心元件 | 10 kΩ / 100 nF |

> 注：TS3A 括号内为**库内 connector 编号**（= 物理脚 − 1，如 NO1=物理 13 脚→connector12）。

## J1 接口定义（8 个过孔焊盘，EN 子板固定接地）

> 下表为**实际物理脚序**（PnP 实测，板右缘一列，上→下）：`3V3, IO1, IO2, IO4, IO5, IO6, IO7, GND`。
> 3V3（VCC）与 GND **分居两端**（相距 7 个焊盘），不会互相短路。

| 脚（上→下） | 标签 | 信号 | 去向 | 对应 ESP32 控制板 |
|---|---|---|---|---|
| 1（顶） | `3V3` | VCC | MUX VCC + TS3A VCC | 3V3 |
| 2 | `IO1` | SIG | MUX 公共输出 | IO1（ADC1_CH0，GPIO1） |
| 3 | `IO2` | SEL | TS3A IN1-2/IN3-4（并联） | IO2（GPIO2） |
| 4 | `IO4` | S0 | MUX 地址 0（LSB） | IO4（GPIO4） |
| 5 | `IO5` | S1 | MUX 地址 1 | IO5（GPIO5） |
| 6 | `IO6` | S2 | MUX 地址 2 | IO6（GPIO6） |
| 7 | `IO7` | S3 | MUX 地址 3（MSB） | IO7（GPIO7） |
| 8（底） | `GND` | GND | 全子板地（MUX/TS3A/桥/RC/EN） | GND |

> MUX `EN` 已在子板上接 GND（低有效常开），不引出。
> 接口在原理图上用 8 个网络标签表示，标签文字标出对应 ESP32 控制板引脚（IO1/IO2/IO4~IO7/3V3/GND）。这 8 个网络标签使用自建 **`NetLabel-Pad`** 元件（2026-08-30，2026-08-31 更新），**PCB 上已生成 8 个实体过孔焊盘**（**PAD-2.0-H1.0**：Ø2.0mm 焊盘 / Ø1.0mm 钻孔，**2.54mm 间距**，Bottom 面右缘一列），已实测：PnP 为 `PAD-2.0-H1.0`、drill 文件有 8×Ø0.97mm 钻孔（2026-08-31 从 PAD-1.2-H0.6 无钻孔改为现封装，焊盘环用 circle 才能生成钻孔）。**标准 2.54mm 排针可直接插入**。

## 子板网表（通道 1 为例）

| 起点 | 终点 | 说明 |
|---|---|---|
| L1 `inner` | U整流A.`node` | 线圈一端接桥 A 中点 |
| L1 `outer` | U整流B.`node` | 线圈另一端接桥 B 中点 |
| U整流A.`A1` | GND | BR- |
| U整流B.`A1` | GND | BR- |
| U整流A.`K2` | `BR+` | 整流输出正 |
| U整流B.`K2` | `BR+` | 整流输出正 |
| `BR+` | R1(10 kΩ) | 串联电阻 |
| R1 另一端 | `node_RC` | 低通节点 |
| `node_RC` | C1(100 nF) → GND | 低通滤波 |
| `node_RC` | U2.`COM1` | 滤波输出进开关 |
| U2.`NO1` | U3.`C0` | 通道 1 输出 → MUX（裸芯片 `I0`=9 脚） |
| U2.`NC1` | GND | 背景采样路径 |
| U2.`IN1-2` / `IN3-4` | J1.`SEL` | 两脚并联到同一 SEL |
| U2.`VCC` | J1.`VCC` | 3.3V 由控制板供给 |
| U2.`GND` | J1.`GND` | |
| U3.`VCC` | J1.`VCC` | 裸芯片 24 脚 |
| U3.`GND` | J1.`GND` | 裸芯片 12 脚 |
| U3.`EN` | GND（子板） | 低有效常开 |
| U3.`S0`~`S3` | J1.`S0`~`S3` | 通道选择，S0 最低位（裸芯片 10/11/14/13：S0=10、S1=11、S2=14、S3=13） |
| U3.`SIG` | J1.`SIG` | 16 路选通输出（裸芯片 1 脚 COM） |

## ESP32 控制板 GPIO 对应（待建板）

| 用途 | GPIO | WROOM-1 引脚 | 库内连接器 |
|---|---|---|---|
| J1 `SIG`（ADC1_CH0） | GPIO1 | IO1 | connector38 |
| J1 `SEL` | GPIO2 | IO2 | connector37 |
| J1 `S0` | GPIO4 | IO4 | connector3 |
| J1 `S1` | GPIO5 | IO5 | connector4 |
| J1 `S2` | GPIO6 | IO6 | connector5 |
| J1 `S3` | GPIO7 | IO7 | connector6 |
| WS2812B `DI`（显示，如用） | GPIO15 | IO15 | connector7 |
| 板载 WS2812（未用） | GPIO48 | IO48 | connector24 |

> ADC1 = GPIO1~GPIO10（CH0~CH9）。J1 `SIG` 接控制板 **GPIO1/IO1（ADC1_CH0，connector38）**，Arduino 里 `analogRead(1)` / `analogReadMilliVolts(1)` 读取（0~3.3V → 0~4095）。
> ⚠️ 整流输出须 < 3.3 V（ESP32 ADC 量程）；若场强过大需加钳位（如 3.3 V 齐纳）。

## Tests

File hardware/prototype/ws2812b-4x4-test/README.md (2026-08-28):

# WS2812B-5050 4×4 矩阵测试（ESP32-S3-DevKitC-1）

验证 4×4（16 颗）WS2812B 矩阵模块的最小点亮 + 灯序。

## 模块引脚（库内 `WS2812B-5050-4x4`）

```
         顶排
   GND | VCC | DOUT | GND
   ─────────────────────
        （30×30mm 板）
   ─────────────────────
   GND | VCC | DIN  | GND
         底排
```

- 底排：pin1=GND, pin2=VCC, pin3=DIN, pin4=GND
- 顶排：pin1=GND, pin2=VCC, pin3=DOUT, pin4=GND
- 灯序：**每列从下往上爬**（列与列之间在底部相连），像素 0（=元件 LED 1）在**右下角**。✅ 已实测验证。

  ```
        列0  列1  列2  列3
  第0行: 15   11    7    3
  第1行: 14   10    6    2
  第2行: 13    9    5    1
  第3行: 12    8    4    0   ← 像素0在右下角
  ```

## 接线

| ESP32-S3-DevKitC-1 | 4×4 模块 | 说明 |
|---|---|---|
| `3V3`（或外接 5V） | `VCC` | 电源 |
| `GPIO15`（丝印 `15`） | `DIN` | 数据输入 |
| `GND` | `GND` | 共地 |
| — | `DOUT` | 空接或级联 |

> ⚠️ **电源**：16 颗满白约 960mA。用 3V3 供电必须保持低亮度（固件默认 30，安全）。满亮度请外接 5V 到模块 VCC 并共地。
> ⚠️ 本板 `5Vin` 实测 0V（见单颗测试），无法从板子取 5V。

## 编译 + 烧录（arduino-cli）

```powershell
arduino-cli compile --fqbn esp32:esp32:esp32s3 .
arduino-cli upload -p COM32 --fqbn esp32:esp32:esp32s3 .
```

## 测试内容（固件内）

1. **全亮单色**：红 → 绿 → 蓝 → 白（验证 16 颗都亮 + 颜色顺序）
2. **逐颗扫**：橙灯沿蛇形 0→15 依次点亮（验证灯序）
3. **追逐灯**：一颗沿蛇形来回跑
4. 熄灭后循环

## 预期现象（已实测 2026-08-28）

- 四色全亮阶段：16 颗应全部同色点亮 ✅
- 逐颗扫阶段：橙色灯从**右下角**开始，**沿右列向上**移动 ✅（每列从下往上爬）
- 3V3 供电：亮度 30 合适（80 偏亮）；16 颗满白约 200mA，勿再调高

## 测试结果

| 项 | 结果 |
|---|---|
| 16 颗全亮 + 颜色顺序 | ✅ 正常 |
| 灯序（右下角起，每列从下往上） | ✅ 与元件一致 |
| 3V3 供电亮度 30 | ✅ 合适；80 偏亮 |
| 元件灯序描述 | 已修正为“每列从下往上”（原假设为行/列交替蛇形，均与实测不符） |

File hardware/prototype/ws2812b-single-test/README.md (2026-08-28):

# WS2812B 单颗测试（ESP32-S3-DevKitC-1）

验证单颗 WS2812B-5050 灯珠 + ESP32-S3 的最小点亮回路。✅ 已实测通过（2026-08-28）。

## 接线（已实测）

| ESP32-S3-DevKitC-1 | WS2812B-5050 | 说明 |
|---|---|---|
| `3V3` | `VDD` | 电源 3.3V（**实测用 3V3，不用 5Vin**，见下） |
| `GPIO15`（丝印 `15`，库内 connector7） | `DI` | 数据输入 |
| `GND` | `GND` | 共地 |
| — | `DO` | 空接 |

> ⚠️ **丝印核对**：GPIO15 在板子上丝印标号是 **`15`**（不是 `7`）。丝印标 `7` 的是 GPIO7（connector6）。按丝印字母找，别按位置数。

> ⚠️ **电源备注**：本板 `5Vin` 实测读 **0V**（USB 供电下仍为 0，板子本身能跑、板载灯正常），改用 **`3V3`** 给 VDD 后外部灯珠正常点亮。量产方案需另定电源路径（或修 5V 问题，或 3V3 供电）。

## 依赖（已装好）

- `arduino-cli` 1.2.2
- 核心：`esp32:esp32` 3.3.3
- 库：`Adafruit NeoPixel` 1.15.5

## 编译 + 烧录（arduino-cli）

```powershell
# 1) 确认板子 COM 口
arduino-cli board list

# 2) 编译（FQBN: ESP32S3 Dev Module）
arduino-cli compile --fqbn esp32:esp32:esp32s3 .

# 3) 烧录（把 COMx 换成实际端口）
arduino-cli upload -p COMx --fqbn esp32:esp32:esp32s3 .

# 4) 看串口日志（115200）
arduino-cli monitor -p COMx --config baudrate=115200
```

> 💡 如果烧录卡住提示连接失败：按住板子 **BOOT** 键不放再点上传，出现 "Connecting..." 时松开。
> 💡 若用 Arduino IDE：工具 > 开发板 > `ESP32S3 Dev Module`，管理库装 `Adafruit NeoPixel`，直接上传即可。

## 预期现象（已实测）

- 红灯渐亮 → 绿灯渐亮 → 蓝灯渐亮
- 红 / 绿 / 蓝 各常亮 1 秒
- 白灯常亮 1 秒
- 熄灭 1 秒后循环

## 测试结果（2026-08-28）

| 项 | 结果 |
|---|---|
| 板载 WS2812 (GPIO48) | ✅ 正常循环 |
| 外部 WS2812B-5050 (GPIO15) | ✅ 3V3 供电正常点亮 |
| 5Vin 供电 | ❌ 实测 0V，改用 3V3 |
| Adafruit NeoPixel 1.15.5 | ✅ 编译烧录正常 |

若灯不亮，先检查 VDD 是否接到了 3V3、GND 是否共地、DI 是否接在丝印 `15` 上。

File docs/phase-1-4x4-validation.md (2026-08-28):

# Phase 1: 4x4 子板验证

本阶段目标：验证一个 4x4、16 通道的 NFC 近场磁场相对分布显示链路，不追求绝对 A/m 测量。

## 先锁定的设计边界

- 工作频率：13.56 MHz NFC 近场。
- 传感器：4x4 个 PCB 线圈，目标覆盖 80 mm x 80 mm。
- 采集：每通道整流、低通滤波，再由模拟多路复用器送入 ESP32-S3 ADC。
- 差分：TS3A44159 在“正常信号”和“背景/短路”路径之间切换。
- 显示：4x4 WS2812B 模块，1 个采样通道对应 1 个 LED。
- 输出：归一化后的相对场强和串口调试数据；不宣称绝对 A/m 精度。

## 打板前的关键电路复核

现有 BOM 中的 BAT54S 是双二极管串联器件，不应直接当作完整四二极管全波桥。你提供的 WJ1196454 规格书显示：SOT-23 的 1、2 脚是串联两端，3 脚是两只二极管的中点。对于普通两线线圈，推荐每通道使用两颗 BAT54S 组成四二极管桥，因此 16 通道需要 32 颗 BAT54S。

对于每个线圈，必须在原理图中明确选择一种拓扑：

1. 使用两颗 BAT54S 组成四二极管桥；或
2. 使用适合小信号 RF 的四二极管桥式整流方案；或
3. 改用中心抽头线圈，并确认两只二极管的连接方式满足全波整流。

BAT54S 桥式连接时，每颗器件的 3 脚为内部中点，不能把两颗器件简单并联。按本规格书的串联方向，每通道可这样组成桥：

```text
U整流A：1脚接 BR-，3脚接 COIL_A，2脚接 BR+
U整流B：1脚接 BR-，3脚接 COIL_B，2脚接 BR+
```

其中 `COIL_A`、`COIL_B` 是线圈两端，`BR+` 和 `BR-` 是整流输出。这样两颗 BAT54S 的四只二极管共同构成全波桥；`BR+` 接滤波网络，`BR-` 接 GND。实际装配前仍需用万用表二极管档确认实物方向。TS3A44159 的 COM、NO、NC、SEL、V+、GND 也必须按实际数据手册核对，不能仅凭封装外形连接。

## 方案 C：全波整流 + 差分背景采样

每个通道的信号链为：

```text
两线线圈
	-> 2 × BAT54S 全波桥（BR+ / BR-）
	-> R=10 kΩ 串联、C=100 nF 对地的低通
	-> TS3A44159 的 COM
			 NO -> 该通道输出
			 NC -> GND（背景采样）
	-> CD74HC4067
	-> ESP32-S3 ADC1
```

TS3A44159 的 4 个开关通道分别服务 4 个传感通道，因此 16 通道需要 4 颗 TS3A44159。该器件有两组控制输入：`IN1-2` 控制通道 1/2，`IN3-4` 控制通道 3/4。将每颗芯片的 `IN1-2` 与 `IN3-4` 短接，再把四颗芯片的控制线并联到同一个 ESP32-S3 GPIO，即可让 4 个通道同步切换。采样时分别读取正常路径和背景路径，再做相减。

CD74HC4067 选择 `HC` 型而不是 `HCT` 型，使用 `3.3 V` 供电。规格书给出的 HC 工作范围为 `2~6 V`，`HCT` 则要求 `4.5~5.5 V`。其 `E` 引脚低有效：`E=0` 时工作，`E=1` 时所有通道断开。

当前实际购买的是 CD74HC4067 开发板，而不是裸芯片。原型阶段可直接使用开发板：开发板的 `C0~C15` 接 16 路 TS3A44159 输出，`SIG` 或 `DIG` 接 ESP32-S3 ADC，`S0~S3` 接四个 GPIO，`EN` 接 GND 或 ESP32 GPIO，`VCC` 接 3.3 V，`GND` 接系统地。不要把开发板供电设为 5 V 后再把 `SIG` 接入 ESP32 ADC，否则模拟输出可能超过 3.3 V。

### TS3A44159 PW（TSSOP-16）引脚

按 TI 规格书 SCDS225 的 "Pin Configuration and Functions"，Fritzing 中应使用以下定义（**2026-08-28 核对，13–16 脚与库内 `TS3A44159PWR.fzpz` 一致**）：

```text
1 NO2       2 COM2      3 NC2       4 GND
5 NO3       6 COM3      7 NC3       8 IN3-4
9 NO4      10 COM4     11 NC4      12 VCC
13 NO1     14 COM1     15 NC1      16 IN1-2
```

在本项目中，`VCC=3.3 V`，所有 `NC1..NC4` 接 GND，四个滤波输出接 `COM1..COM4`，四个通道输出接对应的 `NO1..NO4`。`IN1-2`（16 脚）与 `IN3-4`（8 脚）并联后接控制输入。

### CD74HC4067（24 脚）引脚

```text
1 COM       2 I7        3 I6        4 I5
5 I4        6 I3        7 I2        8 I1
9 I0       10 S0       11 S1       12 GND
13 S3      14 S2       15 E        16 I15
17 I14     18 I13      19 I12      20 I11
21 I10     22 I9       23 I8       24 VCC
```

`S0` 是最低位，通道编号按 `S3 S2 S1 S0` 的二进制值选择。方案 C 中，裸芯片的 `COM` 接 ESP32-S3 ADC，`I0~I15` 接 16 路 TS3A44159 输出，`E` 接 ESP32 GPIO 或直接接 GND 使能。使用开发板时，这些端子分别对应 `SIG/DIG`、`C0~C15` 和 `EN`。

## 第一阶段里程碑

### M0：器件和拓扑确认

- [ ] 按 WJ1196454 规格书确认 BAT54S 为 SOT-23、1/2 为串联两端、3 为中点。
- [ ] 采购数量改为 BAT54S ×32，按每通道两颗桥式整流计算；现有 16 颗还差 16 颗。
- [ ] 画出单通道完整原理图：线圈、整流、RC、TS3A44159。
- [ ] 确认整流输出不会超过 ESP32-S3 ADC 输入范围。
- [ ] 确认 CD74HC4067 的供电电压、信号范围和 EN 逻辑。

### M1：单通道台架验证

- [ ] 用一个线圈和整流电路连接示波器。
- [ ] 在 13.56 MHz NFC 读卡板附近确认有稳定载波响应。
- [ ] 测量无场、弱场、强场三种状态的输出电压。
- [ ] 检查整流输出纹波和二极管小信号灵敏度。

### M2：4 通道验证

- [ ] 验证 TS3A44159 的四个 SPDT 通道。
- [ ] 验证正常路径与背景路径切换。
- [ ] 验证 CD74HC4067 能逐通道读取。
- [ ] 先用串口输出数据，不接 LED 也应能完成验证。

### M3：4x4 子板 PCB

- [ ] Inkscape 生成 4x4 线圈阵列 SVG。
- [ ] Fritzing 完成元件布局、网络连接和板框。
- [ ] 增加测试点：VCC、GND、SEL、MUX 公共端和每路整流输出。
- [ ] 导出 Gerber，并用 Gerber 查看器检查铜层、阻焊、丝印和钻孔。

### M4：显示和免校准相对热力图

- [ ] ESP32-S3 读取 16 路数据。
- [ ] 每帧执行背景相减。
- [ ] 对 16 路结果做最大值归一化。
- [ ] 映射到 4x4 WS2812B 模块。
- [ ] 保存一组串口数据作为第一份可复现实验记录。

## 推荐的近期顺序

1. 先画并确认一个通道的原理图。
2. 用面包板或飞线完成单通道和四通道实验。
3. 再做 4x4 PCB 的 SVG 和 Fritzing 设计。
4. 子板验证通过后，再复制为四块并设计 64 通道母板。

## 验收标准

- 无 NFC 激励时，各通道输出接近背景值。
- NFC 读卡板激励时，输出随距离和位置变化。
- 切换 SEL 不会造成 ADC 饱和或明显串扰。
- 4x4 LED 显示位置与 4x4 线圈位置一致。
- 更换读卡板位置后，热力图形状能随之变化。

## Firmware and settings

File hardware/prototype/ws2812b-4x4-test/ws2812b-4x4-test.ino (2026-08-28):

// ============================================================
// WS2812B-5050 4x4 矩阵测试 — ESP32-S3-DevKitC-1
// ============================================================
// Wiring（4x4 模块，库内 WS2812B-5050-4x4）:
//   ESP32-S3  3V3(或外接5V) -> 模块 VCC
//   ESP32-S3  GPIO15       -> 模块 DIN
//   ESP32-S3  GND          -> 模块 GND（共地）
//   (模块 DOUT 可空接，或接到下一块 DIN 级联)
//
// 电源：16 颗灯珠满白约 960mA。3V3 供电请保持低亮度（默认 30）；
//       要满亮度需外接 5V 到模块 VCC，并共地。
//
// 灯序：模块为蛇形扫描（右下角 1→16），像素 0 在右下角。
//
// Library: Adafruit NeoPixel 1.15.5
// Board: ESP32S3 Dev Module (esp32:esp32:esp32s3)
// ============================================================

#include <Adafruit_NeoPixel.h>

#define PIN         15          // ESP32-S3 GPIO15
#define NUMPIXELS   16          // 4x4 = 16 颗

Adafruit_NeoPixel pixels(NUMPIXELS, PIN, NEO_GRB + NEO_KHZ800);

void setup() {
  Serial.begin(115200);
  delay(200);
  Serial.println("WS2812B 4x4 test starting...");

  pixels.begin();
  pixels.setBrightness(30);     // 实测 3V3 下 30 亮度合适；80 偏亮，满白需外接5V
  pixels.clear();
  pixels.show();
  delay(300);
}

void loop() {
  // 1) 全亮单色循环：验证 16 颗都能亮 + 颜色顺序
  allColor(255, 0, 0);   // 红
  allColor(0, 255, 0);   // 绿
  allColor(0, 0, 255);   // 蓝
  allColor(255, 255, 255); // 白（3V3 下会偏暗/偏色，属正常）

  // 2) 累积铺路：验证完整蛇形路径（路径逐渐铺满，可看清走向）
  verifyTrail(255, 80, 0); // 橙色铺路 + 慢速逐颗带序号

  // 3) 追逐灯（knight rider）：沿蛇形来回
  knightRider(0, 255, 128);

  // 4) 熄灭
  pixels.clear();
  pixels.show();
  delay(800);
}

// 累积铺路：从像素0开始一颗颗点亮且不熄灭，路径像画线一样铺满
// （实测确认：每列从下往上爬，列间底部相连）
void verifyTrail(uint8_t r, uint8_t g, uint8_t b) {
  for (int pass = 0; pass < 3; pass++) {
    for (int i = 0; i < NUMPIXELS; i++) {
      pixels.setPixelColor(i, pixels.Color(r, g, b));
      pixels.show();
      Serial.print("trail to pixel "); Serial.println(i);
      delay(250);
    }
    delay(1500);   // 16 颗铺满后停留，便于观察整条路径
    pixels.clear();
    pixels.show();
    delay(800);
  }
  // 逐颗慢速走一遍（带序号，方便核对每个位置）
  for (int i = 0; i < NUMPIXELS; i++) {
    pixels.clear();
    pixels.setPixelColor(i, pixels.Color(0, 255, 255));
    pixels.show();
    Serial.print("pixel "); Serial.println(i);
    delay(400);
  }
}

// 全部 16 颗同时显示一种颜色
void allColor(uint8_t r, uint8_t g, uint8_t b) {
  for (int i = 0; i < NUMPIXELS; i++) {
    pixels.setPixelColor(i, pixels.Color(r, g, b));
  }
  pixels.show();
  delay(1200);
}

// 逐颗点亮一圈（按蛇形像素顺序 0..15）
void pixelWalk(uint8_t r, uint8_t g, uint8_t b) {
  for (int i = 0; i < NUMPIXELS; i++) {
    pixels.clear();
    pixels.setPixelColor(i, pixels.Color(r, g, b));
    pixels.show();
    delay(120);
  }
}

// 追逐灯：一颗高亮沿蛇形来回跑
void knightRider(uint8_t r, uint8_t g, uint8_t b) {
  for (int i = 0; i < NUMPIXELS; i++) {
    pixels.clear();
    pixels.setPixelColor(i, pixels.Color(r, g, b));
    pixels.show();
    delay(60);
  }
  for (int i = NUMPIXELS - 2; i > 0; i--) {
    pixels.clear();
    pixels.setPixelColor(i, pixels.Color(r, g, b));
    pixels.show();
    delay(60);
  }
}

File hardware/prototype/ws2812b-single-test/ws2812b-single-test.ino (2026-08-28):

// ============================================================
// WS2812B-5050 外部单颗测试 — ESP32-S3-DevKitC-1
// ============================================================
// Wiring:
//   ESP32-S3  5Vin(或3V3) -> WS2812B  VDD
//   ESP32-S3  GPIO15      -> WS2812B  DI
//   ESP32-S3  GND         -> WS2812B  GND
//   WS2812B  DO           -> (unconnected)
//
// 注：若 5Vin 供电读数为 0，可先用 3V3 给 VDD 供电验证灯珠能否点亮。
//
// Library: Adafruit NeoPixel 1.15.5
// Board: ESP32S3 Dev Module (esp32:esp32:esp32s3)
// ============================================================

#include <Adafruit_NeoPixel.h>

#define PIN         15          // ESP32-S3 GPIO15
#define NUMPIXELS   1           // 单颗灯珠

Adafruit_NeoPixel pixels(NUMPIXELS, PIN, NEO_GRB + NEO_KHZ800);

void setup() {
  Serial.begin(115200);
  delay(200);
  Serial.println("Onboard WS2812 (GPIO48) test starting...");

  pixels.begin();
  pixels.setBrightness(40);     // 首次测试先调低亮度，保护眼睛和灯珠
  pixels.clear();
  pixels.show();
  delay(300);
}

void loop() {
  // 1) 呼吸渐变：红 → 绿 → 蓝（也顺便验证颜色顺序 GRB）
  fade(255, 0, 0);   // 红
  fade(0, 255, 0);   // 绿
  fade(0, 0, 255);   // 蓝

  // 2) 单色常亮各 1 秒（方便肉眼核对颜色顺序）
  solid(255, 0, 0);
  solid(0, 255, 0);
  solid(0, 0, 255);

  // 3) 白色（三色全亮）
  solid(255, 255, 255);

  // 4) 熄灭
  pixels.clear();
  pixels.show();
  delay(1000);
}

void fade(uint8_t r, uint8_t g, uint8_t b) {
  for (int i = 0; i <= 255; i++) {
    pixels.setPixelColor(0, pixels.Color(
      (uint8_t)((long)r * i / 255),
      (uint8_t)((long)g * i / 255),
      (uint8_t)((long)b * i / 255)));
    pixels.show();
    delay(3);
  }
  delay(300);
}

void solid(uint8_t r, uint8_t g, uint8_t b) {
  pixels.setPixelColor(0, pixels.Color(r, g, b));
  pixels.show();
  delay(1000);
}

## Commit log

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2026-08-29 feat(subboard): single-channel sensor schematic with CD74HC4067 MUX
    M0 signal chain: coil -> 2x BAT54S full bridge -> RC low-pass -> TS3A44159 -> CD74HC4067 -> ESP32-S3 ADC1. Replaces official MUX breakout with new CD74HC4067 part; adds netlist, GPIO map, and syncs embedded ESP32-S3 fzp (buses) into prototype fzz.
    [single-channel.fzz, ws2812b-4x4-test.fzz, ws2812b-single-test.fzz]
2026-08-30 refactor(subboard): ESP32 拆分到控制板，子板接口改为 8 个网络标签
    - 方案 C：子板无 MCU，接口用 8 个网络标签（ESP32-S3-DevKitC-1 IO1/IO2/3V3/IO4~IO7/GND）标注对应开发板/控制板引脚
    - 面包板视图用开发板 SVG 图像（IMG1），不影响原理图/PCB；删除自建排针/焊盘元件
    - 新增 single-channel-schematic-wiring.md / single-channel-breadboard-wiring.md
    - 更新 single-channel-schematic.md / schematic-spec.md
    - README：产品形态（尺寸预估 + 显示布局三方案 A/B/C）+ 开发过程总览 M0~M5
    - 修复：IO2(SEL) 网络标签原误接 MUX C7，已改接 SEL 网
    - 验证：网表 8/8 正确、三视图渲染无 NaN
    [single-channel.fzz]
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2026-08-30 single-channel 子板：J1 焊盘 2.54mm 间距 + PAD-2.0-H1.0 过孔焊盘
    - J1 焊盘间距 2.0mm → 2.54mm（100mil），3V3/GND 分居两端
    - NetLabel-Pad 升级为 PAD-2.0-H1.0（Ø2.0mm 焊盘 / Ø1.0mm 钻孔），可插标准 2.54mm 排针
    - 板尺寸按 fzz/gerber 实测修正为 43.46×23.81mm
    - 新增 single-channel BOM；接线文档同步 J1 实际物理脚序
    - 重新导出 Gerber（drill 含 8×Ø0.97mm J1 孔）
    [single-channel.fzz, single-channel_bom.csv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]
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2026-09-26 pixel 面包板：审计/度量工具入库 + 交付 v46
    工具（都是本次工作新写的 ✓，可独立复算 ✓）：
    - hardware/pixel/audit_layout.py 6 条硬约束的**独立**审计器（一孔一端点 / 遮挡接线孔 /
    引线重叠 / bus 短接 / 网连通 ⑤⑥）—— 它抓到过 check_netlist.py 漏掉的 EPAD 悬空 ✗
    - hardware/pixel/bb_compare.py 度量尺子：交集（X 交叉 + T 搭线 + 穿元件）、长度、
    用孔数、斜线段、拥挤度（两版对比时用它，保证"同一把尺子" ✓）
    - hardware/pixel/fix_epad_ground.py 原理图：EPAD → LED2.GND（看得见"特意接地" ✓）
    - hardware/pixel/fix_breadboard_layout.py 面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
    [pixel-breadboard46.fzz]
2026-09-26 pixel 面包板：修预览图的"假象" + 交付 v53（当前最优）
    ★ 用户报的 bug ✗：「你的 preview.png 没有一个是正确的，你为啥有信心给俺看呢？」
    根因（都量过 ✓，不猜 ✗）：
    ① preview.svg 的 `<svg width="1800" height="615">` **没单位** ✗ ⇒ 按 CSS px 解释
    ⇒ 文档 476mm ✗ 而内容只有 175.8mm ✗。修 ✓：显式写 mm（1 单位 = 25.4/90 mm ✓）。
    ② 面包板 svg 的比例算错 ✗：`breadboard2.svg` 是 Illustrator 导出（`id="Layer_1"`、`x="0px"`、
    `width="468.238px"`，且有 viewBox ✓）⇒ "有 viewBox 就 90dpi" 算成 132.1mm ✗，
    而板子必须 165.2mm ✓（**72dpi** ✓）。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
    [pixel-breadboard53.fzz]
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2026-09-26 修复面包板预览的三个真根因（对齐 Fritzing 口径）；LED2 脚位机验 Δ=0.00
    用户判定：「preview 是错的」而「Fritzing 里 LED2 位置正确」⇒ 坏的是渲染器，.fzz 没问题。
    三处全在 hardware/pixel/（render_bb.py + part_box.py）：
    1) px 单位 = 1/72 英寸（此前按 1/90、1/96、1/1000 都错）
    证据 A：面包板 breadboard2.svg 头 `width="468.238px" viewBox="0 0 468.238 …"`
    ⇒ 468.238px = 165.2mm ≈ 孔阵 576 单位 = 162.6mm（差 9 单位 = 端部留边）
    证据 B：WS2812B_1010 面包板 4 脚中心差 14.401x21.600 用户单位 → 18.00x27.00 sketch 单位
    = 它插的孔 col31→col33(18) 与 rowE→rowF(27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
2026-09-26 统一 px 单位口径：part_box.canvas_mm 的 25.4/96 → 25.4/72（消灭第二份错口径）
    上一提交把渲染器的 px 钉成 1/72 英寸（两条独立证据），但 part_box.canvas_mm 里还留着
    25.4/96 ⇒ 同一件事两份口径，其中一份必错。它喂 body_box（算"本体遮住了哪些孔"）
    ⇒ px 件的本体算小 25% ⇒ 少算被遮的孔 ⇒ 可能把线布到元件底下，且审计漏报
    （§5b 第 4 条那条硬规则会形同虚设）。
    无单位（width="25"）故意仍不支持 ⇒ 返回 None ⇒ 上层视为"不知道"，而不是算一个错的出来。
    改后用修正后更严的本体框复验 pixel-breadboard59.fzz：
    audit_layout.py ⇒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
2026-09-26 工具全部入库 + 仓库内自包含（不再依赖草稿区与元件库仓）；v62 = 第一版完全合法且零交叉
    用户 2026-09-27：「好的，入库和提交吧」。起因是这一轮的教训：生成器只在
    f:\git\_scratch 里 ⇒ 崩溃、改一处不生效、参数丢失，全查不出来。
    入库到 hardware/pixel/：
    run_v6.py（管线驱动）、bb_route4.py（布线器）、bb_legend3.py、file_sanity.py、
    fix_connects.py、part_measure.py、pin_ruler.py
    （后两个原本在元件库仓 fritzing-parts-langhua/tools ⇒ 跨仓依赖，换机器就断）
    ⇒ 现在仓库内自包含：实测把 FRITZING_TOOLS 指到 X:\nonexistent 仍然跑通。
    脚本改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
    [pixel-breadboard62.fzz]
2026-09-26 工具归位：通用件移到元件库仓 tools/（本项目不留副本）；统一工具定位；验证 v64 == v62
    用户 2026-09-27 纠正：「按咱们之前的约定，是应该入到 fritzing-parts-langhua\tools 的」
    ⇒ 上一笔把通用工具放进本项目是错的，本笔纠正：
    · 移出本项目：bb_compare.py / bb_legend3.py / file_sanity.py / fix_connects.py / part_box.py
    （已在库仓 tools/）；并删掉我多拷的 part_measure.py / pin_ruler.py（库仓原本就有）
    · 新增 hardware/pixel/toolpaths.py = 工具定位的唯一处
    默认按相对路径指向同级仓 …\fritzing-parts-langhua\tools（不写死机器路径），
    FRITZING_TO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
2026-09-27 检查程序：脚位自检改按 Fritzing 口径（读 sketch 的 <leg>），消除 C2/R1 的误报
    ★ 用户 2026-09-27 的判断（原话）：「我的建议是 3，不改图，改检查程序。现在我在 Fritzing 里看，
    没有看到任何错误」✓ —— **判断完全正确** ✓，不需要改图 ✓。
    ★ 铁证（读 sketch 原始数据 ✓）：sketch 里每个 <connector> 下的 `<leg><point>` 就是
    **Fritzing 画腿用的端点** ✓：
    C1（好 ✓）connector0 腿末点 y=18.0031、connector1 y=18.0031 ← 两条一样 ✓
    C2（报错 ✗）connector0 y=18.0033、connector1 y=27.0033 ← 差 9 ✗
    我们那次"已批准修正"（fix_brea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
2026-09-27 pixel: 布线器 —— 斜线预算 + 让路器 4 个 bug + 单条 tie 换接（335.6mm，超越手版）
    交付：pixel-breadboard104.fzz
    总长 335.6mm / 交集 0 / 斜线 4 条 / 拥挤度 0.44
    6 条硬约束 0 违规、网表 10/10、文件自检 0（全部由独立工具所量）
    对照：v95 363.6mm、用户 100_byHand 345.7mm ⇒ 比手版短 10.1mm
    其中 DATA_OUT (243,63)->(270,108) 14.8mm 与用户手画的那条逐字相同
    bb_route4.py（10 处改动，每处都有实测证据）：
    1. 让路器愿望枚举扩成"这根线自己在同 bus 里的各孔组合"（原来只在两个固定端点之间找，
    端点一旦被别处挪歪就再也列不出"想走水平直线"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
    [pixel-breadboard100.fzz, pixel-breadboard104.fzz]
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2026-09-27 pixel: 原理图渲染器 render_sch.py（对 Fritzing 导出逐件验平 Δ≤0.0004）+ v1 摆位修正
    ★ 为什么要：本机 Fritzing 的**命令行导出是坏的** ⇒ 每轮都得用户手动导图给我看。
    现在渲染器自己出图，这一环自动化了。
    ★ 不许自证 ✓：`--verify-export` 拿 **Fritzing 自己导出的 svg** 当尺子逐件核对 ——
    pixel-schematic.fzz 9 件 Δ ≤ 0.00040 单位（0.00011 mm）
    pixel-schematic-v1.fzz 9 件 Δ ≤ 0.00003 单位（0.00001 mm）
    常数 (1.05, 117.1) **只用一件标定** ✓，其余 8 件逐件验证 ✓。
    ★ 纠正我先前的错结论：原理图 sketch 单位**不是** 1/72 in ✗，而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
    [pixel-schematic-v1.fzz]
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2026-09-27 修 bug：原理图里 px 单位是 1/90in（不是 1/72in）—— 用户截图"线没接到脚上"的根因
    一、根因（实测钉死 ✓，不是猜 ✗）
    - 症状（用户截图 ✓）：Fritzing 里"网在一起 ✓、线严重错位 ✗"。
    - 先证明**导线几何本身没错** ✓：逐根比向量全部一致 ✓，起点差是同一个常数 (12.463, 61.650) ✓。
    - 再做**无需标定**的判别 ✓（同一导出文件里，比"同一零件内部两个脚的向量" ✓）：
    L1/C1/C2/R1/U1/J1/J2 全部 0.8 精确 ✓；**只有 LED2(48px)、D3(66px) 是 0.64** ✗
    ⇒ 0.64/0.8 = 0.8 ⇒ 我把 px 当 1/72in ✗，Fritzing 按 **1/90in** ✓ 读。
    - 修 `render_sch.py`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
    [pixel-schematic-v7.fzz]
2026-09-27 给 --verify-export 补"引脚判别"（起因：它以前只比锚点 ⇒ 假通过一整天）
    一、补了两条**不需要任何标定**的判据（全在导出内部比 ✓，全局平移/缩放自动抵消）
    - ⑤ 同一零件内的**脚向量**：我算的 × s ↔ 导出画的 ✓
    （抓"零件 k 算错 / 镜像旋转 / 脚编号接错"—— px 那个 bug 正是它抓的）
    - ⑥ **线到脚**：每条"导线→脚"连接 ⇒ "导出画的线端" ↔ "导出画的脚" ✓
    （抓"按错的脚位画线"—— 用户看到的"网在一起、线却错位"）
    二、为什么以前没抓到（教训）
    - 老的 ①②③ 只比"零件锚点"与"导线自己"，两边都用**我自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
2026-09-27 按修正后的真实尺寸重调摆位：GAP_X 2→1 格、GAP_Y 3→2 格（扫描实测）
    起因：`px` 那个 bug 修掉后 LED2/D3 小了 20% ⇒ 旧间距是照**错的尺寸**调的 ⇒ 布线器为绕空档
    把交叉撑到 12、画布也放大。
    扫描（`_scratch/sweep_layout.py`，全流程 6 组）
    | GAP_X/Y | 交叉 | 压线 | 位号压(元件/导线/位号) | 总长 | 画布 mm |
    | 1.0/2.0 | 9 | 8 | 0/3/0 | 2137.3 | 90.9×90.5 | ← 采纳
    | 2.0/2.0 | 12 | 7 | 0/3/0 | 2242.9 | 97.0×88.4 |
    | 2.0/3.0 | 12 | 7 | 0/3/1 | 2386.9 | 97.0×96.6 | ← 旧值
    | 3.0/3.0 | 11 | 6 | 0/4/0 | 2467.7 | 103.1×91.2 |
    | 1.0/3.0 | 9 | 8 | 0/3/1 | 2281.3 | 90.9×98.6 |
    | 1.5/2.5 | 10 | 7 |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
    [pixel-schematic-v8.fzz]
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2026-09-28 pixel 原理图 v28：支线共享同网竖线（学手改版第三次）⇒ 总长 −52.2、擦身 15→8
    新形状（用户选 ②：在支线搜索里加候选，不做后处理）：
    · 同一条轨上的支线可以**沿脚行横走**、搭到**同网那根已通轨的竖线端点**上 ⇒ 不再各竖一趟。
    · 档1（交付档）：总长 2692.1 → **2640**（−52.2）、导线 55 → **52**、**跨网擦身 15 → 8**、
    交叉 15（不变）、贴脚/穿体/重叠/**假接头 0**、悬空端 **1**、画布 105.8×87.4（不变）、
    网表 ✓ 10 网全对、告警 0、退出码 0、sch_style_check 通过（FAIL 0 / 提示 1）。
    两处硬卡点（都是打印 used 看出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
    [pixel-schematic-v28.fzz]
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2026-09-29 pixel 原理图：脚位模型修正（标签脚在箭头尖端）+ 接地符号规则 ⇒ v31
    起因：用户手改 v30（把 GND 网标签换成接地符号；挪 RC 标签、去掉多余导线）让我检查。
    接地符号（新规则，源码取证）：
    - connectoritem.cpp::isGrounded() = 脚名 ∈ {gnd, vss, ground}；symbolpaletteitem.cpp 里
    bus id == "groundbus" ⇒ LocalGrounds ⇒ 全图所有叫 GND/VSS/GROUND 的连接器是一张网
    - sch_net.py 新增 is_ground_symbol / grounded_connectors / ground_links
    （脚名从 .fzz 自带的那份 .fzp 里读；草图里只有 connectorId）
    - check_netlist.py 用它 ⇒ 用户那版从"GND 被拆成 2 段"✗ 变成 9 网全对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
    [pixel-schematic-v31.fzz]
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2026-09-29 pixel 原理图：接地符号图形入库 + 与 Fritzing 导出逐点对账（check_labels 两个 bug）
    用户导出 pixel-schematic-v32_图示.svg 后一次办完两件：
    ① 接地符号图形入库（用户同意）
    - 从导出里逐字摘出 GroundModuleID 的绘制内容（两个实例完全一致）⇒
    _assets/ground_symbol.svg + _assets/LICENSE-ground.txt（来源/许可/用途，同 WS2812B·JST 那套）
    - sch_net.ground_art() 读它并摆位：
    translate(几何 + (9.001,0.596)) · scale(1.25) · translate(-7.201,-0.375)
    ⇒ 脚正好落在 ground_pin() 上（图形与脚位同一份口径）⇒ 预览里画出来了
    - 顺手独立复核脚位：导出里 translate + 内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
2026-09-29 pixel 原理图 v34：标签就近贴本侧引脚 + 支线代价按整条算 + 成组删冗余
    三条口径都是先核用户手改版、再由他点头实现的（①成组删 ②支线=整条 ③标签就近），另有四处连带修正：
    · 180° 开放为标签候选（用户截图实测 Fritzing 会把标签文字自动摆正；我旧注释写反了）
    · 修「引线蹭脚」把自己出发的那只脚也算进去 => 贴引脚旁的候选全被误否
    · 修级联清断头把挂着真脚的线也删掉（R1 被孤立、标签浮空 11.5 单位；五道判据全绿也没拦住，靠另一份只读核对器量出来）
    · 标签对任何元件本体留 CLEAR=1.7mm（用户问「RC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
    [pixel-schematic-v34.fzz]
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2026-09-29 pixel/README 第三十手：开工第一步否掉了原方案 —— 轨是按包围盒算出来的，会跟着被挪的件跑
    量到：原始 pixel-schematic.fzz 里没有 5V/GND 轨（41 根全 #404040，y=-72 不在其中）；layout 里 0 根导线 => 轨由路由器造；轨 y = 零件包围盒顶 - 28.8（-43.2-28.8=-72.0 与实测吻合）。
    => 把 C2 挪上去会把包围盒顶顶高、轨跟着上移到 -101.2，脚又不在轨上，白挪。用户那版成立是因为他在已布好线的图上挪件（轨已定死）。
    修正方案（下一轮）：两趟 —— 先跑一遍路由读出两条轨的线并钉死，再跑 --snaprails 让脚落在锁定轨上，然后重新布线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
2026-09-29 pixel: 加 --snaprails（把「所有脚都在电源/地上」的件摆到轨上）+ 三条硬护栏
    实现：在 emit 拆链之前跑（此时轨已由路由器算好 => 这才叫先把轨钉住再挪件）。认轨=同网最长的「光板直段」（无 from/to、直线）；候选=保持朝向/翻 180 度 x 平移（把某只脚对到它那条轨上），目标=每只脚到它那条轨线段的距离之和，取最小且必须严格更小、且不压别的件；脚正好落在轨上就把旧支线删掉并在轨上切开挂上（不留零长度残根）。
    踩到的三处：①切轨时拿首尾两点重造 path => 多点 path 被截断 => 导线 46->40、六道判据全红；改成把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
2026-09-29 pixel/README 第三十手：第三次尝试（靶放宽到整网 + 退开留支线 + 候选里判可行性）也做不成，量出「到网距离之和」不是总长的好代理
    三处改动都对，也确实找到可行落点（C2@(237.38,-32.84)、未翻转、支线 59.1->21.6、无穿体无压件），但总长反而 1941.0->1991.2、交叉 8->9、多两处贴脚 => 按这个代理调优会把别的线拖长拖弯。已回退到「做不成就原样不动」的安全版（实测带 --snaprails 输出与 v35 逐条目相同 26/26）。
    结论：用户那 -104.7 单位不是挪一件能拿到的，它由三处局部改动组成（C2 挪位 + 5V 改斜线 + 标签宿主线缩短），其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
2026-09-29 fix(pixel): v36 作废 —— 修好 C2 的 5V 连接、修好橡皮图章闸门（v37 交付）
    用户看图抓出两个真错：
    1) C2 的 5V 脚一根线都没有：骑轨预摆位把它摆成"脚正好落在轨上"，那条支线长度 0，
    被折成 1 个点当"退化段"丢掉 ⇒ 脚孤零零，但图上它正压在轨线上 ⇒ 看着像接上了。
    修法（结构性）：脚落在轨上时不建支线，改成把轨在该 x 处断开（切成两段，两侧各把
    那只脚记成 to/from）⇒ 连接显式、--trim 的终端模型也看得见它（以前整条轨是一段、
    from/to 都是 None ⇒ 终端模型里根本看不见坐脚 ⇒ 把载着断点的那截轨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
    [pixel-schematic-v36.fzz, pixel-schematic-v37.fzz]
2026-09-30 fix(pixel): 支线车道不许贴着"自己那件"的身子（v38 交付）
    用户看图（第二次）："黑色竖线离电容太近了吧？" —— 量出来是几何必然：C2 的盒子
    x=259.96…274.36（电容板半宽 7.2），而 GND 脚支线"出脚 7.2"的车道正好 = 盒子左边缘
    ⇒ 竖线贴着自己的本体跑。既有闸门不管这种：穿体闸门只管"穿过"，而"自己那件"是唯一
    被豁免的（线要进肚子才能接到脚上）⇒ "贴着自己的身子"没人管。
    修法（只剔车道、不动任何合格条件）：车道若落在本件盒子 ± CLEAR(6.0 单位 = 1.7mm)
    之内就剔掉 ⇒ 退到下一档。实测 C2 出脚 7.2 → 14.4（竖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
    [pixel-schematic-v37.fzz, pixel-schematic-v38.fzz]
2026-09-30 refactor(pixel): 通用工具收进元件库仓；项目只留项目脚本 + 项目数据（pixel_nets.py）
    用户 2026-09-30 定：通用工具只有一份，放在 fritzing-parts-langhua/tools/，项目里不留
    副本（toolpaths.py 里早就写着这条，只是项目里还躺着副本）。
    搬走 17 个：sch_geom/sch_box/sch_net/sch_text/sch_glyphs、render_sch/render_bb/
    wire_dump/set_rot、check_netlist/check_fake_wires/check_flags/check_grounds/
    check_label_touch/check_junctions/check_labels、bb_route4、_assets/ground_symbol.svg(+许可)。
    留在项目：gen_schematic_wires、gen_schematic_layout*、pins_*、audit_layout（直接读本板
    网表/摆位）、fix_*/run_v6、t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
2026-09-30 fix(pixel): 线圈定心改用铜箔包围盒（原来用焊盘包围盒，环偏 6.4mm、被顶出板外）+ v3 与预览
    [pixel-pcb-v2.fzz, pixel-pcb-v3.fzz]
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2026-09-30 fix(pixel/pcb): 摆位几何统一到"真占地 + 单一基准系"（J1/J2 不再出板）
    根因链（四处同一个病 ✗）：
    ① pcb_pads.absbox 背面件分支漏减画布原点（已在库仓提交 1b5f797 ✓）；
    ② 本体框取**铜箔** ✗ ⇒ 连接器只有 3 个带 id 的信号焊盘（2 个固定焊盘 + 丝印都没 id ✗）
    ⇒ 铜箔框 1.5 × 5.2 mm vs 真占地 5.33 × 4.35 mm ✗
    ⇒ 改用"**画出来的一切**"（新 ink_box() ✓，与 part_box.shape_bbox 同一份实现 ✓）；
    ③ 框的**基准系**混了 ✗：把实例**当前的** M 也乘进去 ⇒ 朝向被**转两遍** ✗
    ⇒ 统一到"不转、不镜像"那一系（= variants() 用的 rot_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
    [pixel-pcb-v23.fzz]
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2026-10-01 pixel PCB：过孔几何口径修正 + 缩宽 + 写回加固（v48/v49/v50 草图）
    一、过孔 geometry 口径（v49）
    - `<geometry>` 是 svg 画布原点，真铜心 = geometry + 0.86444 mm
    （安装孔 +1.66454）⇒ 统一到 part_box.VIA_DRAW_OFF_MM / draw_off_units()
    - v49 只改 16 个过孔的 geometry，两个平面视图保持 x=y=0
    二、缩宽（neck-down，v50）
    - gen_routes.split_neck()：在缩宽区边界切段，按段写 mils（区内 10 mil）
    ★ 只缩不涨；10/24 mil 不许被 merge_collinear 合并
    - ★ 顺序必须是：先按缩宽区切 → 再跑一遍拓扑整理 → 最后按位置重标 mil
    （反了 ⇒ 新切出的 T 型接点没人管 ⇒ 13 处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
    [pixel-pcb-v26.fzz, pixel-pcb-v48.fzz, pixel-pcb-v49.fzz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]
2026-10-01 pixel PCB：写回流水定序 + 四个自检 + 安装孔提示（v50 系列草稿）
    一、写回（build_xml）流水定序 —— 这是「17 处悬空端点」的修法之一
    - 顺序定为：① 按缩宽区切段 → ② 端点归并 → ③ 拓扑整理 → ④ 按位置标 mil → ⑤ 合并
    ★ ② 必须在 ③ 之前（旧顺序 ①→③→②）
    - split_neck()：遇到斜段就不切（原样放行）—— 切法只对横平竖直成立
    - merge_collinear 带上 mil（10/24 mil 不许合并）
    - 端点归并 SNAP_U = 0.18（≈0.051 mm < 半格 0.15 mm）
    二、诊断开关（都留在代码里，实测有用）
    - --why：① 路由器产物自检（孤立端点）② 几何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
2026-10-01 pixel PCB：写回吸附按网筛（修 4 处「结错网」）+ 硬闸门 ③ + 追踪自检
    一、修「写回把线结到别的网的盘上」（实测 4 处短路）★ 本轮主修复
    - 逐阶段追踪定位（build_xml 里 _stage()，盯 U1.connector2=PA2/DATA_IN 与
    connector3=VSS/GND，两者只差 0.400 mm）：
    ① 缩宽切段 = 干净 → ② 端点归并 ⇒ 立刻冒出跨网端点
    - 根因：_snap() 把**所有焊盘中心**都当吸附点
    ⇒ 端点离它 0.03∼0.05 mm（= A* 格心，最大偏半格 0.075 mm）就被硬吸到
    **隔壁那张网**的盘心上
    - 修法：_snap(p, net)，盘心只在**属于本网**时才允许吸附（过孔心/一般端点照旧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
2026-10-01 pixel PCB：5V/GND 改走 12 mil（24 mil 直连单独画）+ 修日志里写死的 10 mil
    - mil_pow 默认 24 → 12（用户 2026-10-01 定：24 mil 的 5V/GND 可以单独画，
    保证 J1/J2 直连用 24 mil 即可）⇒ 需要时 --mil-power=24 回到旧口径
    - 日志里“（细间距区 10 mil）”改为读 RT.NECK_MIL（缩宽带正在 12/8 mil 之间试）
    - 实测 v60（NECK_MIL=8）：连通 7/9、悬空端点 0、问题 5 处
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2026-10-01 pixel PCB：A 案「留走廊」（5V 先单独布好并钉住）+ 连通 7/9 → 8/9
    用户 2026-10-01 选 A。
    - 先把 5V 单独布好（此刻没人挡它），再把它钉住（pre）⇒ 其余网的栅格里它是硬障碍
    ⇒ 谁都不许占用它的通道。`--no-lock` 可回旧行为（对照用）。
    - 钉住那一次调用也传 copper_keep（与主调用同口径）—— 少了它，5V 的过孔会落在线圈铜上
    与其他焊盘边（实测 v70：4 处 ⑦ 违规）
    实测对照（都开了闸门修复）：
    v71 留走廊 ✓：连通 8/9、问题 1 处（RC 未连通）、压盘 0、短路 0、悬空 0 ← 当前默认
    v72 --no-lock：连通 8/9、问题 5 处（4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
2026-10-01 pixel PCB：补齐「去白钻对」那轮漏传的 copper_keep + prio_list 回退；挪件试到第三个（C1/R1/U1）
    ★ 本轮唯一实质收获（真问题）：`去白钻对` 那轮 `route_ripup` 重布时**漏传 `copper_keep`**
    —— 和之前「钉 5V 那次」是同一个坑的**第二个调用点**。
    证据：补之前那版能凑出 9/9，但**3 个过孔压在/贴着线圈铜**（⑦ −0.050 / +0.003 / +0.031 mm）；
    补上之后 ⑦ = **0** ⇒ 那个 9/9 是"靠违规换来的"，不能要。
    - `prio_list` 回到**只钉 `5V`**：钉 5V+RC 两次实测都不好
    （R1 原位：连通不变但过孔 8→16；R1 挪走后：掉到 7/9）
    - 改板实测（都带上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
2026-10-01 pixel PCB：第三十五手 —— **byHand 版第一次布线**：只布 7 张信号网 ⇒ **7/7 全通 ✓✓**
    底图 = 用户手画的 `pixel-pcb-v51_byHand.fzz`（18 条 24 mil 粗线 + 2 颗过孔 + C2 转 341°）；
    产物 = **`pixel-pcb-v52_byHand.fzz`**（+ 预览 svg/png）。用户的 5V/GND 长线**原样不动** ✓。
    结果：**7/7 信号网全通 ✓✓**（线长 97.5 mm ✓、过孔 7 ✓、悬空 0 ✓、叠 0 ✓）；
    对照：9 张网一起布 ⇒ **6/9** ✗（布线器会把 5V/GND 再布一遍 ⇒ 挤掉信号线）。
    ⇒ 结论：用户的摆位能布通；手工电力线必须保持不动。
    ★ 本轮先修了一个**工具 bug** ✗（这个文件暴露的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
2026-10-01 pixel: 生成过孔时的偏移改为按尺寸算（配合库 `fritzing-parts-langhua` 的修复）
    `gen_routes` 写文件时要**减掉**「`<geometry>` → 铜心」的偏移 —— 原来直接
    `PB.draw_off_units("via")` 拿**默认常数** ✗（= `0.3/0.15` 过孔的值 ✓）
    ⇒ 一旦改了 `_VIA_HOLE_VAL` 而忘了改偏移，写出来的过孔就会偏 ✗
    （2026-10-02 那次「Fritzing 说通、校验器说断」的病根正是它 ✓）。
    现在偏移从**同一份** `_VIA_HOLE_VAL` 解析出的 `_VIA_SIZE_MM` 传入 ✓
    （库侧口径：偏移 = 铜半径 + 画布留白 0.56444 mm ✓，见 `part_box.ring_off_mm` ✓）。
    当前值仍是 `0.3mm,0.15mm` ⇒ 偏移 `0.86444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
2026-10-01 pixel: 5V/GND 收尾 ⇒ `pixel-pcb-v58.fzz`（8/9 网连通 ✓、0 短路 ✓）
    用户 2026-10-02 定 ✓：「1. 电容问题，我选改网表」✓ ＋「2. 继续，把剩下 8 个脚接上吧」✓。
    ## 一、网表：`C2` 的两只脚**对调** ✓
    板上的铜与网表编号**交叉** ✗ —— GND 那根总线接的是 `C2.connector0` ✓、
    5V 那根接的是 `C2.connector1` ✓（**依据 = Fritzing 自己写的 `<connect>`** ✓：
    `Wire90013341` 端0 → `C2.connector0` ✓、`Wire90013354` 端1 → `C2.connector1` ✓），
    而 `pixel_nets.py`（照原理图）原来写的是**反的** ✗。
    电容无极性 ⇒ 实物没毛病 ✓（且实测**没有铜短接** ✓：两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
    [pixel-pcb-v58.fzz]
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2026-10-02 pixel: 修 `<buses>` 从未生效的真 bug + 加"与 Fritzing 另存文件逐条比连接"的工具
    ★ 用户 2026-10-02 的怀疑（"你的全接通判定标准与 Fritzing 不一样"）**实证命中**：
    fz_exact.py 的 `<buses>` 表**一直是空的** ✗：
    · 只在 `.fzz` 包里找 `.fzp` ✗ —— 这包只有 7 个，而 `core/wire.fzp`、`core/netlabel.fzp`、
    `core/via.fzp` 这些**核心件不在包里** ✗
    · 而且原来按 `<moduleId>` 建表 ✗，可 `inst2mid` 存的是 `path="…"` ✗ ⇒ 永远对不上 ✗
    ⇒ "同 `bus()` 合并"这条规则**从未生效** ✗
    修法：按 **`.fzp` 文件名**建表 ✓，两路来源（包内 ＋ `.fz` 里记的绝对路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
2026-10-02 pixel: 第四十一手 —— 两颗过孔被我的生成器放重了（用户发现）⇒ v62
    ★★ 用户 2026-10-02 的原话：「移动 Via8，发现它与 Via6 位置重叠在一起了。这是你程序的 bug 吧？」
    ⇒ **是** ✓。量出来正好 **2 对完全叠死**（心距 0.000 mm ✗）：
    · `Via6` ↔ `Via8`：铜心都 (45.181, 20.522) mm ✗｜记录 0 条 ✗ / 4 条
    · `Via17` ↔ `Via18`：铜心都 (43.931, 15.472) mm ✗｜记录 5 条 / 4 条
    两对都查实属**同一个网** ✓ ⇒ 不是短路 ✗，是**重复放着** ✗ ⇒ Fritzing 只认其中一颗"接上了" ✓、
    另一颗撂单 ✓ ⇒ ⇒ **这就是它报「还有 2 个连接件需要布线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
    [pixel-pcb-v62.fzz]
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2026-10-02 pixel: 记下本轮查出的三处工具硬伤 + Fritzing 事实（含复现命令）
    BUG-1 ✗✗ model["net_pads"] 从未写回 ⇒ obstacles() 的"同网豁免"形同虚设
    ⇒ 每只焊盘都算不出网名 ⇒ 0.4 mm 脚距的 QFN 起步格被邻居盘框盖住
    ⇒ 布线器报"起点格空"（BR+/DATA_IN/DATA_OUT/LED_DIN 四张网永远布不通）。
    修：调用方一行写回（gen_routes.py）。证据与复现命令见正文。
    BUG-2 ✗✗ 走线可以是**贝塞尔曲线**（<wireExtras><bezier><cp0/><cp1/></wireExtras>）
    口径 = Fritzing 源码 src/utils/bezier.h。只读 <geometry> 两端点、按直线算
    ⇒ 线间距/交叉/保线障碍框/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
2026-10-03 修 `--rails` 跑完"没产出"的 bug：重叠报告里解包崩了 ⇒ 文件根本没写
    症状（2026-10-03 实测 ✓）：`gen_schematic_wires.py … --rails --socket=4` 跑完
    **日志最后一行是「规则自检：不同的导线重叠 1 对」✓、退出码 1 ✓、但输出文件不存在** ✗
    ⇒ 看上去像"拒写" ✗ —— 其实是**崩在报告循环里** ✗✗：
    File "gen_schematic_wires.py", line 2906, in main
    for (p1, q1), (p2, q2) in ov_pairs[:6]:
    ValueError: too many values to unpack (expected 2)
    病根 ✓：`used` 的元素是 **3 元组** `(端点, 端点, 网名)` ✓（`used.append((best[k], best[k+1], net))` ✓），
    而 `ov_pairs.append((u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
2026-10-05 像素板第五十手（续 3）：撤回「窄口袋」结论（我又读错折行）＋ 判决落到搜索侧
    错在哪：上一节那句 C2.connector1=1 是折行的数字，真值 144（终端 Substring 截断，我读了半句）⇒ 今天第三次结论翻得太急。
    补上逐脚泛洪后：GND 每只脚都通到同一片 22763 格（74.4%），C2.connector1 通到 28509 格（93.2%）；BR+ 三只脚 21772/20534/21772 格。⇒ 没有窄口袋 ⇒ 不是没路。
    判决按库自己的二分法（pcb_route.py L1480）：可达 ⇒ A* 的问题（上限/代价）；不可达 ⇒ 障碍模型堵死。我们落在前一档 ⇒ 下一刀在搜索侧。
    附带修好 boundary_report 的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
2026-10-05 像素板第五十手（续 15）：闸门接进打分（opt-in）实测仍 7/9，第一维被连通数占住
    改动（默认关）：ESCAPE_PENALTY + escape_penalty() + _GATE，打分从 (连通,-长) 变成 (连通,-小口袋脚数,-长)。
    实测 --mil=8 --escape-penalty 仍 7/9，逐网与基线相同：第一维是连通数，它不同时后面的脚口维轮不上说话，而 7/9 那一档只有一份解。
    实际收益：闸门可用（escape_gate 在 v69 上报 0 只），且这条规则与实物相容已验（以后任何脚口改动的前提）。顺带修显示 bug：开罚项后长 X mm 误把罚项当长度。
    收尾二选一：① 接受 7/9 + 人工补 2 张；② 逐路径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
2026-10-05 像素板第五十手（续 16）：逐路径脚口代价 ⇒ 首破天花板 7/9 -> 8/9
    改动（tools/pcb_route.py，默认关）：ESCAPE_COST_MM + --escape-cost / ESCAPE_R_MM + --escape-r / escape_shadow()（用库自己的 grid.rc 算格号）+ astar 的 avoid2/avoid2_w（复刻已有的加罚不禁死机制）。
    实测：--escape-cost=0.3 或 0.6 ⇒ 8/9（RC 通了，只剩 GND）；--escape-r=0.3 ⇒ 7/9（半径太小，RC 又丢）；--signals-first 在库驱动上是 no-op。
    对照：同一条规则接在候选解打分上无效（第一维连通数占住），接在每步代价上有效。
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2026-10-05 像素板第五十手（续 20）：判官指路（按「谁切了谁」重排次序）实测也否掉 ⇒ 第三个家族出局
    同一 _route_once 只换次序：原次序 6/9（217.5mm/15孔）；受害者挪到最前 4/5/4 ✗；最小扰动（只挪到加害者前一格）4/6/4 ✗ 且两轮循环；对照组（反方向）恒等 6/9。原因：把 RC 挪前它自己立刻变成加害者（一段切掉 5V/BR+/DATA_OUT 共 4 只脚）⇒ 伤害大于收益且震荡。
    顺手修真 bug（报告层，§13 两个声音）：判官把 k2=(位号,connectorN) 印成「网名.脚名」，现改成 U1.connector1（网 RC）。
    三个家族全部实测否掉（事后拦 / 保护带 / 按判官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
2026-10-05 像素板第五十手（续 21）：查出常任加害者是 DATA_IN ⇒ 排最后实测更差（6/9）；并改正上一轮读反的判官图
    勘误：上一节把判官的图读反了（旧标签把网名印在焊盘位号处）⇒ 受害者当成加害者。修标签后重跑：7/9 那份的真故事是一条链——DATA_IN 的一段（U1.connector2→J1.connector2）切了 U1.connector1（网 RC），RC 的一段（R1.connector1→C1.connector0）切了 C1.connector1（网 GND）；8/9 那份 GND ✗ 同样是被 DATA_IN 切了 J1.connector1。
    查明：打印里《脚数↑》GND 打头不是 bug（那次日志带 --first=GND）；库自己 6 个次序正确（probe_order 原样打印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
2026-10-05 像素板第五十手（续 26）：独立复核改成每次必跑（补强幽灵连接）＋ 记入候补 PR
    漏洞不在判据（pcb_check ⑤ 抓到了）而在流程：那一层「重新读刚写的文件、用几何核」挂在 --check 底下（选做），出 v70 时没加 ⇒ 报告数字全来自布线器自己的模型。
    补强：gen_routes 每次写完都跑独立复核，并多印两句——「这份文件不是全通：N 张网有 M 张断着」+「Fritzing 状态栏很可能照样显示布线完成（它顺着文件里的 <connect> 声明走，旧声明会让它误判）⇒ 别信状态栏，信这一行」；有问题时退出码 1，不静默。实测：同一条命令现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
2026-10-06 像素板第二十九轮：旋转（15° 步长）＋ 双件联挪做出来了 ⇒ 六族总账天花板仍是 8/9（差 1 条连接）；并抓到我自己一个真 bug
    - 新增 hardware/pixel/tools/mutate.py：旋转（绕"该件全部焊盘的重心"）+ 多件联挪。
    - tools/place_drv.py：加 --rot/--rot-only/--rot-step=/--rot-parts= 与 --joint/--joint-only/--joint-parts=；
    候选集改成 build_cands()（平移 + 翻面 + 旋转 + 联挪）。
    ① 旋转（用户点名 15° 步长，90° 太粗）：
    中心 = 该件全部焊盘的重心（板坐标）；数学 p' = c + R(p-c) ⇒ M' = R·M、loc' = c + R(loc-c)；
    矩阵数学复用 part_box，读 .fz 的 <transf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
2026-10-06 像素板第三十三轮：用户报「v74 仍是布线完成」⇒ 读出 Fritzing 模型的死角（脚上零铜时状态栏结构性无法诚实）⇒ 真·幽灵找到（旧 PCB 声明把没布通的脚并进别人的链）⇒ reset_pcb_decls() 清掉旧 PCB 声明；v74 撤回；下一步待用户点头做逃逸残段
    读实三处源码：connectoritem.cpp:1340 collectEqualPotential（组网靠声明）、:1413 collectParts（丢掉 Wire ⇒ 网的脚 = 声明闭包里的元件脚）、graphutils.cpp:447 scoreOneNet（边 = 声明 → collectChained 链端）。
    一只脚只有两种命运，且两条路都让状态栏说完成：①有声明 ⇒ 并进那条链 ⇒ 判已连通（v74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
    [pixel-pcb-v74.fzz]
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2026-10-07 pixel: 差异图保住双面板层色（色相 = 层 / 深浅 = 版）
    用户 2026-10-07 原话：「仍然有个问题，双面板的颜色差异看不出来了」。
    ⇒ 旧的"整版一色（A 蓝 / B 红）"把 copper0/copper1 刷成一色了。现在改成：
    - **色相 = 层**：顶层 = 暖橙、底层 = 冷蓝；
    - **深浅 = 版**：浅 = A（旧）、深 = B（新）；
    - 非铜（丝印 / 板框 / 位号 / 孔）= **中性灰**（A 浅 / B 深）；
    - 两版重合处叠得更深（= 没动）。
    - 实现：改用元件库新增的 render_pcb.remap_colors() **认色换色**（不再用"刷成一色"的
    repaint_colors）；图例 6 行、每行带**真实色块**，文字只用 A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
2026-10-09 像素板第五十二轮：用户报「删任意一根导线 **也还是布线完成**」⇒ 照源码复刻状态栏**逐视图**量一遍 ⇒ **证伪**"网模型被弄空"✗、**证明**"删线报未布在 Fritzing 里做不到"✗ ⇒ 交付 `pixel-pcb-v83.fzz` ＋ 两把新尺子
    病（用户 2026-10-10 原话 ✓）：「`pixel-pcb-v82.fzz` 三个视图，都是**布线完成**。但是有问题啊，
    我在三个视图里**随意删除任意一根导线，也还是布线完成**」✗
    ## ① 先量出来（**照源码复刻，四个读数逐字对上** ✓）
    新尺子 ✓：库仓 `tools/pcb_status.py`（引擎，一份实现 ✓）＋ 本仓 `tools/pcb_rats_probe.py`
    **逐视图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
    [pixel-pcb-v83.fzz]
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2026-10-10 pixel-pcb-v86：C2 也换 0603（＋ 电阻/电容全家改名 1/2、结构病收口）
    1. C2 → Capacitor-0603（swap_rc_0603.py 新增通用档 --swap=<位号>:<库件名>）：
    原核心库电容（焊盘 1.20×1.10、脚距 1.70、斜放、在背面）换成 0.65×0.80／1.45。
    独立复核 probe_wire_moves.py（与换件工具零共享代码）：端点动了的恰好 4 条
    （挂 C2 上的 Wire90013614/15、Wire90014016/81，各 Δ0.108 mm），另 133 条一动没动、
    没增没删。包内 pcb svg = connector0pad＋connector1pad 两块 ＋ 一个丝印组。
    闸门：pcb_check 全过（⑩ 113 条声明全合格、⑫ 悬空 0）、check_netlist 9/9、
    pcb_status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
    [pixel-pcb-v85.fzz, pixel-pcb-v86.fzz]
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2026-10-10 撤回 v87 ✗（用户实测：R1.1 离 Wire90016002 只有 0.035 mm ⇒ 做不出来）
    - 用户原话：「不能使用 v87，你修改的版本，R1.1 离 Wire90016002 过近，检测程序有 bug 吧？」
    —— 他说对了。实测（_work/pad_wire_gap.py，判据用 pcb_route._pt_seg_d / pcb_wire.trace_pts
    的唯一实现）R1.1（= R1.connector0，我们改名 1/2 之后 "1" 就是 connector0）到 Wire90016002
    （网 COIL_A）的铜净距只有 +0.0352 mm，比嘉立创 1 oz 最小 0.127 还小 ⇒ 做不出来。
    - 闸门的洞：④b 原来只在"线身真的压住异网焊盘"（d ≤ 线半宽）时报 ⇒「贴近但没碰上」是盲区。
    已在库仓补（提交 85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
    [pixel-pcb-v87.fzz]
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2026-10-15 pixel: README「六十」补一句状态栏预测（pcb_status ⇒ 面包板 K=0 ⇒ `Routing completed`）
    用户验收那一步要读的是 Fritzing 状态栏那句 ⇒ 把我这边**能给的对照**写进同一节 ✓：
    `tools\pcb_status.py pixel-pcb-v89.fzz --nets=pixel_nets.py` ⇒ **面包板视图 K=0** ✓
    （文案应为 `Routing completed` ✓）；`SWIO` 只 1 只零件脚 ⇒ Fritzing 不当它是一张网 ✓
    （`sketchwidget.cpp:7013` ✓，设计如此 ✓ 不是漏接 ✓）；
    同跑还报 **PCB 视图 K=2** ✗ ⇒ 那是**该视图仍是 v87** 的缘故 ✓（「遗留 1」✗），不是面包板的问题 ✓。
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2026-10-18 fix(pixel): EXPECT 的 RC 网把 PD5 写成 connector17（那是 PD4）→ connector18
    - 依据 `_work/_bb/u1.fzp`：connector17 = PD4 / connector18 = PD5 / connector19 = PD6
    - 症状：bb_probe 拿 PD4 去比对 ⇒ RC 报「断成 2 片」✗；
    v90 与手改版 byHand 报的是**同一句**（说明不是图的问题，是数据写错）
    - 修后：两版都「判定 ✓ 与项目数据一致（11/12 张网连通成一片 ✓）」
    - 教训：EXPECT 里的 connectorN 必须对部件 fzp 的 name= 核实，
    别信注释里「pin 18 ⇒ con17」那种推算（差一位）
2026-10-18 docs(pixel): 交付 pixel-pcb-v91.fzz（面包板手改定稿 ＋ RC 的 EXPECT 笔误已修）
    - 来源：用户手改的 pixel-pcb-v90b_byHand.fzz（已把 R3 旁路/短接、DATA_IN 断、DATA_IN_C 断三处修好）
    - 数据修正：pixel_nets.py 的 EXPECT["RC"] 把 PD5 写成 connector17（那是 PD4）→ connector18（提交 386e460）
    - 判据（都在交付件上跑）：
    · bb_probe 判定 ✓ 与项目数据一致（11/12 张网连通成一片）
    · _netdump 12 张网各 1 个连通块
    · bb_precheck ✓ 允许布线
    · _wirehole 一孔一根线 0 冲突 / _board_side_audit 98 孔 0 不一致 / fix_joints 接头全部双向
    - README §六十二 记录；三张预览（pre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
2026-10-18 面包板预览加电阻色环 + 修三个写错的阻值 ⇒ 交付 pixel-pcb-v92.fzz
    起因：用户拿 Fritzing 截图指出预览里四个电阻一模一样、Fritzing 里是分色的（用户是对的）。
    一、渲染器（库仓 tools/render_bb.py）
    - 照 src/items/resistor.cpp 复刻 setBands()：按 resistance 算三道环 + 倍率 + 公差色，
    改 band_1_st / band_2_nd / band_rd_multiplier / gold_band 的 fill。
    - 颜色表逐值照抄 ColorBands(:71-82) / Tolerances(:85-95)，不自己调色。
    二、色环一上色，暴露了真问题：v91 里三个阻值是错的
    - R1: 220 → 10k（设计 10 kΩ）
    - R3: 4.7k → 100
    - R4: 4.7k → 100
    （R2 4.7k / C1 C2 100nF 16V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
2026-11-06 像素板最小固件（台架第 ③ 步）：PC6 驱动 WS2812 + PD6 采包络
    - 新增 hardware/pixel/firmware/min-bringup/（自包含，不依赖 WCH SDK、不依赖仓库外文件）：
    · src/regs.h 只写用到的寄存器（地址/位值照数据手册 CH32V003DS0 V1.8
    与 MounRiver 自带 EVT 的 ch32v00x*.h 核对，逐条记在 README）
    · src/startup.S 自己写的启动：0x0 = j reset、0x08 起 60 项 trap、sp=0x20000800、
    mtvec 用向量表模式（出异常就停在 trap，LED 保持最后颜色）
    · ld/ch32v003.ld FLASH 16K @0x0、RAM 2K @0x20000000（CH32V003 代码区就在 0）
    · src/main.c ① 上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
2026-11-06 最小固件：自检挪到 ADC 之前、改成满亮度白光；没信号改成常亮暗白
    问题（用户 2026-11-06 报「WS2812B 不亮」）：
    原来那版把上电自检排在 adc_init() 之后，而 ADC 初始化/首转里有两处死等
    （等 RSTCAL/CAL 清零、等 EOC）—— 一旦卡住，灯永远不闪，等于把
    「MCU 没跑」和「ADC 卡住」混成同一现象。
    改动（只改判据可读性，不动 ADC/SPI 的取值）：
    1. 上电自检挪到 spi_init() 之后、adc_init() 之前；亮度 60/255 -> 200/255，
    时长 60 ms 亮 / 240 ms 灭 -> 各 200 ms。
    2. 没信号（mv < 20）时不再用「每秒 10 ms、20/255」的暗白心跳（占空 1%，
    而 WS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
